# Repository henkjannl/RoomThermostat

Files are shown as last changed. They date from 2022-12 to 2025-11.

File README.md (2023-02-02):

# Roomthermostat

I wanted to create a room thermostat that can be controlled remotely ('honey, did you remember to switch off the heating?') but which also remains fully operational if internet connectivity is lost. Therefore it can be controlled through Telegram, but also via the hardware unit if WiFi is down. This is also useful since visitors may not want to use Telegram.

<p align="center">
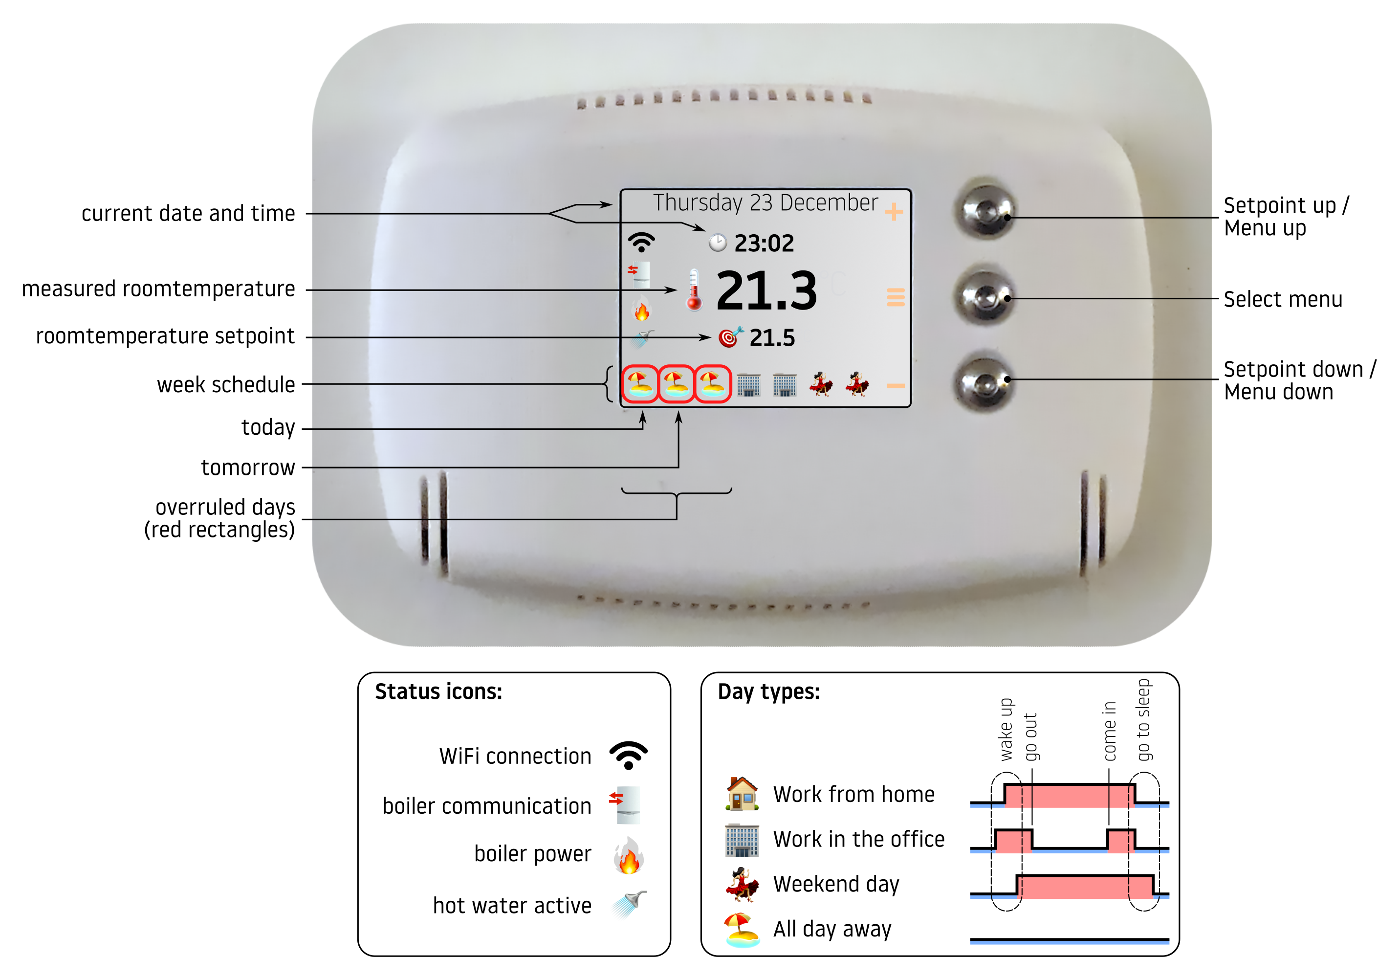
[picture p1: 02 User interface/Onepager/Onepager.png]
     
</p>

This fully (software & mechanics & electronics) open source project is based on an ESP32 microcontroller and the OpenTherm protocol.

The thermostat can be controlled by three touchbuttons on the device or via Telegram. 
In Telegram, an inline keyboard is used which changes depending on the context. This way, the user experience is similar to controlling the device via the hardware. The menu status of each Telegram user is kept in memory, so all users can communicate with the thermostat independently.

### Priorities for the temperature setpoint

<p align="center">
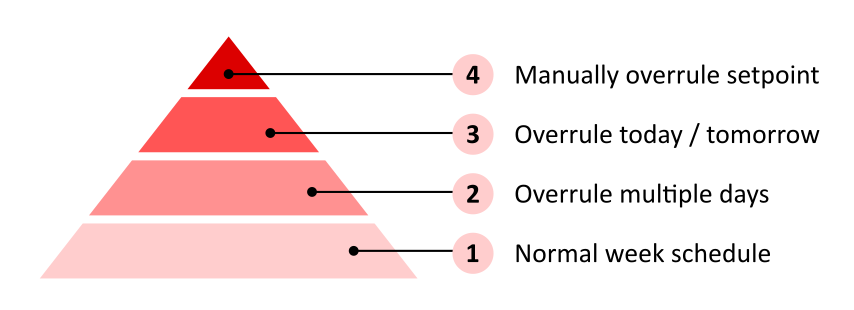
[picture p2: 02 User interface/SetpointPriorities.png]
setpoint priorities
   
</p>

The temperature setpoint can be chosen in four different ways, with increasing priority level:
1. The lowest priority level is the **normal week schedule**, which says which day type it is depending on the day of the week. 
    * There are four predefined day types:
        * :house_with_garden: **work from home**: temperature high at wake-up, and low at bed time
        * :office: **work from the office**: temperature high at wake up, low when going out, high when coming home and again low at bed time
        * :dancer: **weekend**, like :house_with_garden: **work from home** but with different wake-up and bed times
        * :palm_tree: **all day away**: temperature low throughout the day
    * The days of the week can be programmed in **settings**. 
    * All times for each type of day type can be modified
    * The low temperature and high temperature can be modified. These are the same temperatures for all day types
2. It is possible to **overrule multiple days** with a different day type, for instance to program multiple days as :dancer: **weekend day** (e.g. holiday at home) or as :palm_tree: **days away** (e.g. holiday away). 
    * The thermostat will be overruled until the number of days expires, or if the **overrule multiple days** function is **switched off** by the user
    * It is also possible to set the number of days to **forever**, for instance if heating is not required during the summer. The **overrule multiple days** can then be **switched off** in autumn.
3. **Today** and **tomorrow** can be overruled by a schedule that is different from the normal schedule.
    * Every night at midnight, **today** is replaced by **tomorrow** and **tomorrow** is switched off
    * Both can be **switched off** or changed by the user
    * For instance: if the holiday starts tomorrow, **multiple days** can be overruled to be :palm_tree: **day away**, after which **today** can be overruled as :dancer: **weekend day**
4. At all times, a **higher or lower temperature** can be manually selected. 
    * When the next programmed timeslot of the lower priority day type dawns, the temperature setting switches back the program of the nearest lower priority
    * It is also possible to choose ```Auto``` from the main menu in Telegram to switch the manual setpoint override off

If the temperature setpoint is manually overruled (priority level 4), it is displayed in red font.

Overruled day icons (priority levels 2 and 3) are surrounded by a red rectangle on the hardware unit. Telegram commands that overrule priority levels 2 and 3 will typically display  day type icons for the next 7 days.

The thermostat can be controlled by three touchbuttons on the device or via Telegram.
In Telegram, an inline keyboard is used which changes depending on the context. This way, the user experience is similar to controlling the device via the hardware. The menu status of each Telegram user is kept in memory, so all users can communicate with the thermostat independently.

## Controlling the thermostat through Telegram
### Main menu in Telegram

After selecting ```/start``` in Telegram, the following message and keyboard are returned:

<p align="center">
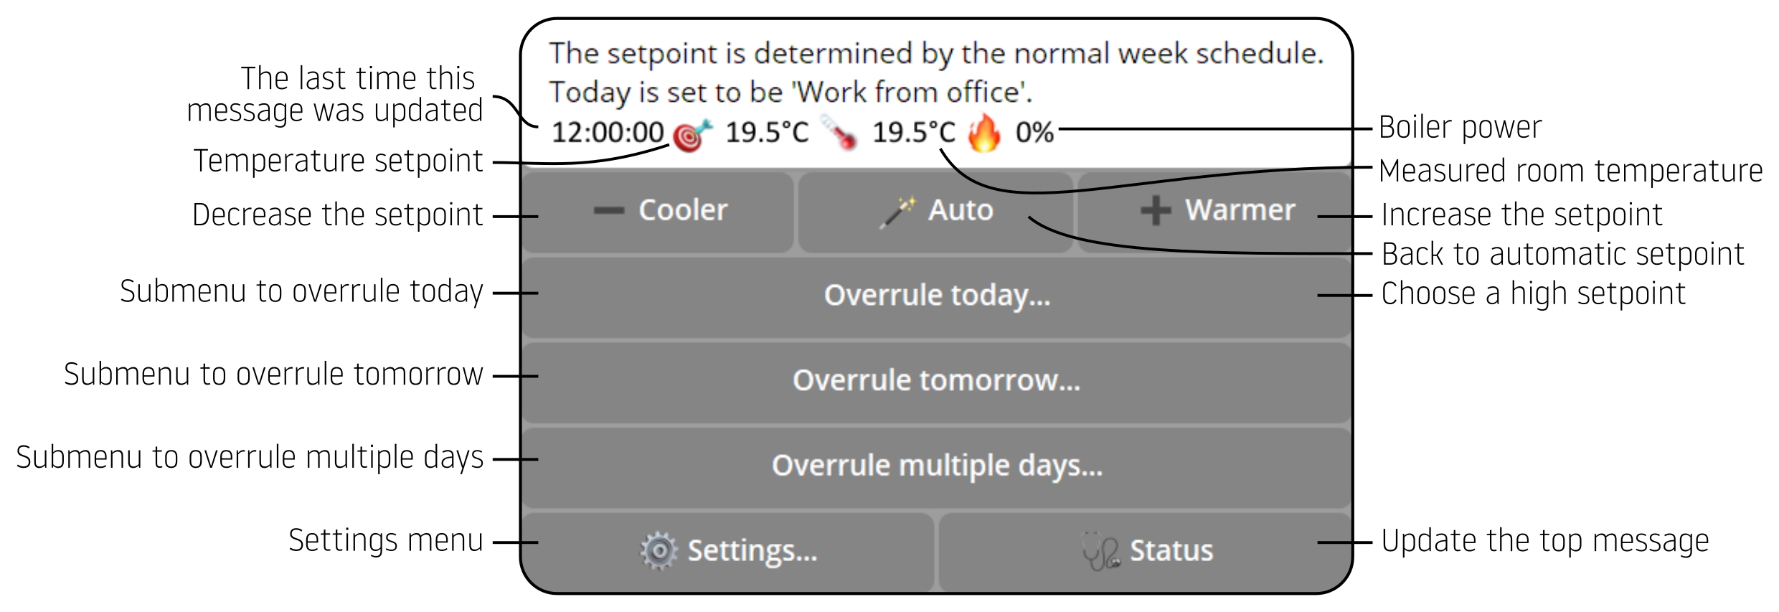
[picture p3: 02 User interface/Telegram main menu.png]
telegram main menu
   
</p>

The temperature in the room or settings of the thermostat can change over time. The display in Telegram is not automatically updated. The ```Status``` button can be used to update the status.

The settings menu has the following options:

<p align="center">
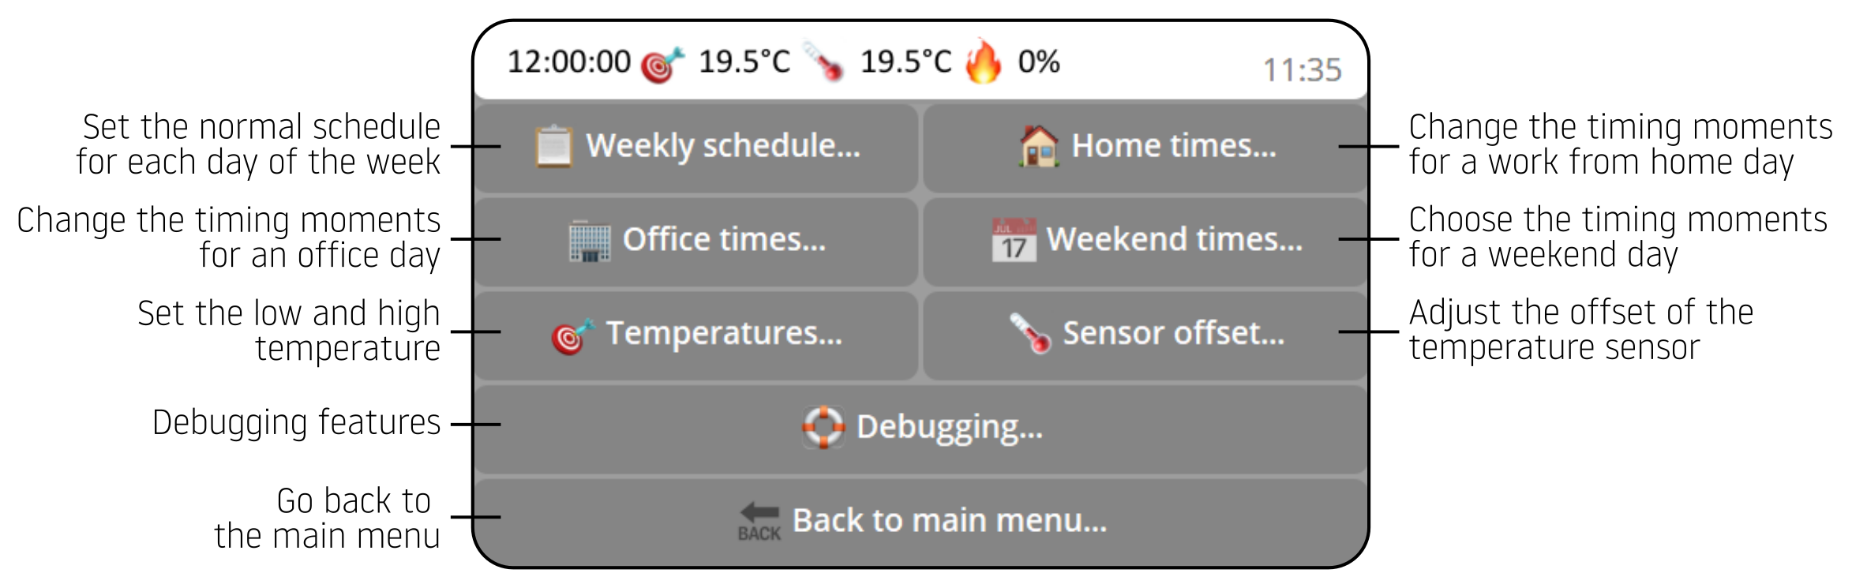
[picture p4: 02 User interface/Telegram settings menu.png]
telegram main menu
   
</p>

### Simple use case in Telegram: going on a short holiday

The scenario is that we are going on a holiday for a few days and we will return on Monday.

To do this, select ```Overrule multiple days...``` in the main menu:

<p align="center">
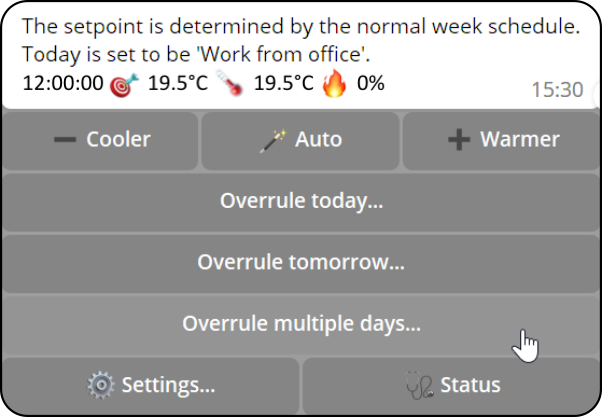
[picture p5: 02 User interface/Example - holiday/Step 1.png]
   
</p>

The icons in the next window show that the next two days are currently :office: **work from office**-days, followed by two :dancer: **weekend days** and again some :office: **work from office**-days.

<p align="center">
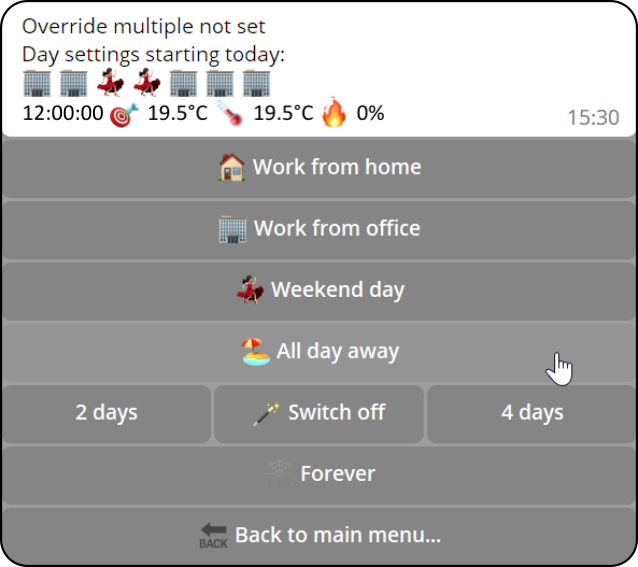
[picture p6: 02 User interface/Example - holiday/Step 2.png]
   
</p>

Select :palm_tree:```All day away``` since we will be going on a holiday:

The :palm_tree:```All day away``` scenario means that the setpoint temperature will remain low throughout the day.

Then select ```4 days``` button multiple times in the next menu until the message says there are 5 :palm_tree:**all day away**-days, including Monday, which is the last day that the temperature should remain low:

<p align="center">
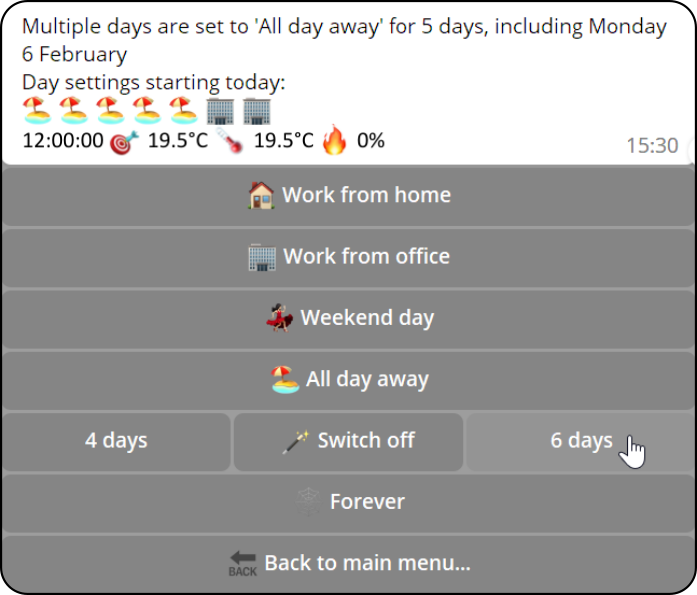
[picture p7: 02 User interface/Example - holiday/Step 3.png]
   
</p>

Next select ```Back to the main menu```:

<p align="center">
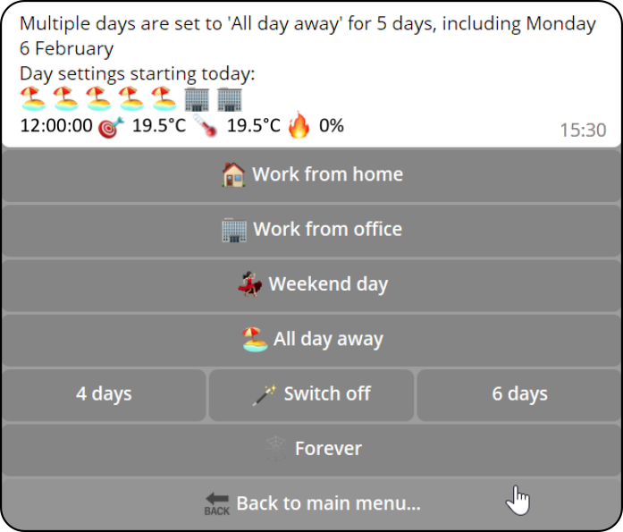
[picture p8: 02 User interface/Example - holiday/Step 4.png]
   
</p>

Now, the current day is also selected as an :palm_tree:**All day away**, with a low temperature setting for the remaining part of the day. To resolve this select ```Overrule today...```:

<p align="center">
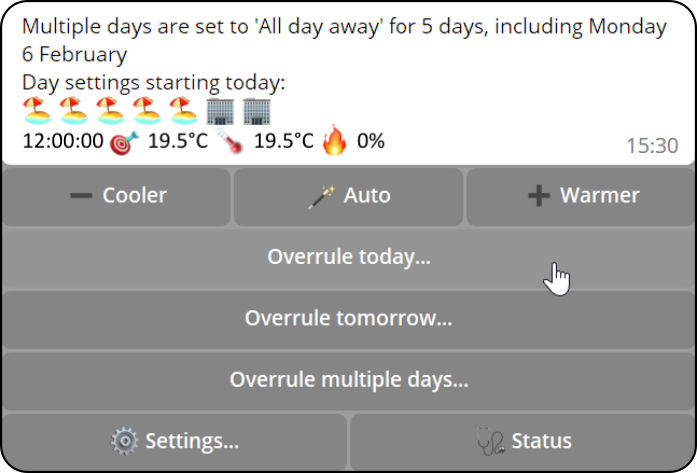
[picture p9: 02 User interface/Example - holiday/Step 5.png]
   
</p>

Choose :dancer:```Weekend day``` so we can pack our bags comfortably:

<p align="center">
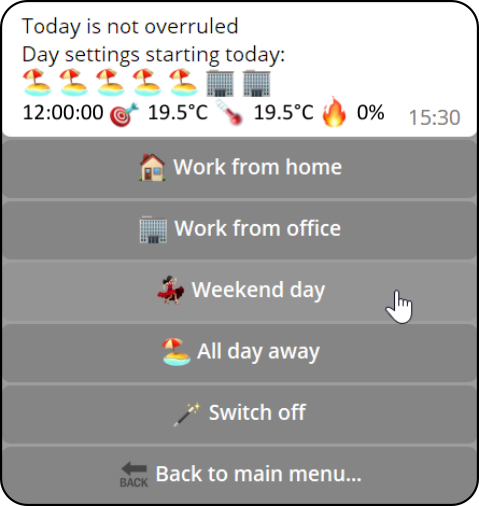
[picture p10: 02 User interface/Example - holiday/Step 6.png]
   
</p>

The remaining **Multiple days** will remain selected, only the current day will be overruled. It is also possible to overrule the next day while the remaining  **multiple days** remain overruled.

<p align="center">
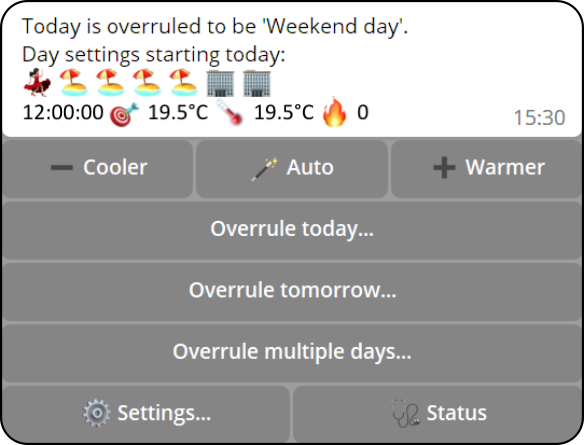
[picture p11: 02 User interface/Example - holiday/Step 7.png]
   
</p>

Of course it is also possible to do these steps after we leave, without the need to overrule the current day. As we are returning home during the next Saturday, we can also overrule the current day to ensure the house is comfortable upon arrival.

### Switch off the thermostat for a longer period of time

To switch off the thermostat for a longer period of time, for instance during the summer or during a long holiday, proceed as follows:
* Select ```Overrule multiple days...``` in the main menu
* Select :palm_tree: ```All day away```
* Select ```Forever```
* Select ```Back to the main menu...```

The thermostat is now switched off until ```Overrule multiple days``` is ```Switched off```

## Building the device

### Electronic hardware 
The hardware consists of:
* an ESP32 (mh-et-live-minikit-d1)
* an OpenTherm adaptor designed by Ihor Melnyk (DIYless Master OpenTherm Shield - https://diyless.com/product/master-opentherm-shield)
* a 2.4" 320x240 TFT screen (ILI9341)
* a 3D printed housing designed in FreeCad
* up to 4 Dallas DS18B20 temperature sensors
* a 4k7 resistor as pull-up for the Dallas temperature sensors
* 3 touch buttons (stainless steel screws, ISO7380-1, M5 x 16 + nut ISO4032 M5)
* 16 magnets (ø10 x 2.75 mm)
* a PCB designed in KiCad. This is optional, components can also be connected with wires, although it is more work and less reliable

Except for the housing and the OpenTherm interface, everything was ordered at AliExpress. The total bill of materials was about €35. The bill of materials can be found here ```\04 Electrical\Bill of materials.ods```.

### Mechanical hardware

There are two options:
* Connecting electronics via the cross connect PCB - the casing then consists of two panels, see ```03 Mechanical\RoomThermostat.FCStd```
* Connecting electronics via wires - the casing then consists of three panels, see ```03 Mechanical\RoomThermostat with PCB.FCStd```

In case of the PCB, there are two main parts to 3D print, a **front panel** and a **rear panel**. The rear panel can be screwed to the wall. The front panel is clicked on the rear panel through magnets.

Both prints need to be paused in some layer during printing to add round magnets before recommencing the printing.

It is possible to add up to four Dallas temperature sensors on the PCB (but fewer sensors should also work).

There are central ventilation openings on the bottom and top of the device to cool the ESP32 and prevent thermal cross talk between the heat of the ESP32 and the temperature sensors. There are ventilation openings in front of each temperature sensor also to measure the room temperature as accurate as possible.

The sofware has an **adjust sensor offset** feature to add or subtract a value from the measured temperature for calibration. That means that if the temperature measured by the thermostate is different from the actual room temperature, this can be corrected through the hardware buttons or via Telegram. 

### Software preparation
It is required to make a specific Telegram bot account for the thermostat. There are many sources explaining how a new Telegram bot can be created, such as in this [Random Nerd Tutorials Telegram example](https://randomnerdtutorials.com/telegram-control-esp32-esp8266-nodemcu-outputs/).

One ChatID can be provided to which the roomthermostat sends a message upon startup. This is useful to be aware that the thermostat was reset, due to a software bug or power outage.

In order to use the software, the user must first:
* make a copy of `template.jsn` (located in the `..\RoomThermoStat\05 Software\Roomthermostat\data` folder)
* rename the copy `config.jsn` 
* fill in details of one or more WiFi routers, including the timezone in which each router is located (`lon` and `lat` are currently not used)
* upload the data to SPIFFS using the ESP32 sketch upload data tool
* copy `User_Setup.h` and `User_Setup_Select.h` to the `..\Arduino\libraries\TFT_eSPI` folder (perhaps good to backup the existing versions)

The format of the `config.json` file is as follows:

```JSON
{
    "AccessPoints": [
        { "SSID": "SSIDOfWifi1", "password": "PasswordOfWifi1", "timezone" : "Europe/Amsterdam" },
        { "SSID": "SSIDOfWifi2", "password": "PasswordOfWifi2", "timezone" : "Europe/Amsterdam" }
    ],
    "BotName"     : "Name of the bot",
    "BotUsername" : "Username of the bot",
    "BotToken"    : "##########:XXXXXXXXXXXXXXXXXXXXXXXX",
    "ChatID"      : "########"
}
```

Note that there is a `config.json` and a The format of the `config_test.jsn`. The `config_test.jsn` is for test purposes, with a different bot token. It can be used for test purposes while the main thermostat bot remains accessible. To use the test bot, specify ```#define USE_TESTBOT true``` in `Roomthermostat.ino`.

Next it is necessary to upload the data folder to the ESP32 using `Tools` > `ESP32 Sketch Data Upload` in the Arduino IDE (see how this works at [Random Nerd Tutorials Telegram](https://randomnerdtutorials.com/install-esp32-filesystem-uploader-arduino-ide/).

Also, a number of libraries must be installed in Arduino:
* `ArduinoJSON` by Benoît Blanchon - https://arduinojson.org/
* `DallasTemperature` by Miles Burton - https://github.com/milesburton/Arduino-Temperature-Control-Library
* `JPEGDecoder` by Bodmer - https://github.com/Bodmer/JPEGDecoder
* `OpenTherm` by Ihor Melnyk - https://github.com/ihormelnyk/opentherm_library
* `TFT_eSPI` by Bodmer - https://github.com/Bodmer/TFT_eSPI
* `UniversalTelegram` by Brian Lough - https://github.com/witnessmenow/Universal-Arduino-Telegram-Bot

Big shout out to everyone for creating and maintaining these beautiful pieces of work!

## Software internals

### Overview of processes
| File | Module |
|---|---|
| Roomthermostat.ino | Initialization and main loop |
| a_constants.h | Defines, constants, data types |
| b_interfaces.h | Queues and structs that connect the subsystems |
| c_logger.h | Datalogging (to be implemented) |
| d_keyboard.h | Keyboard |
| e_menu.h | Menu of hardware unit |
| f_telegram.h | Handler for Telegram messages |
| g_controller.h | Temperature controller, including PID controller and program |
| h_temperature.h | Temperature measurement and communication with boiler |
| i_wifi_time.h | Wifi controller and real time clock |
| j_jpeg.h | Library to display jpeg images |
| k_display.h | Display of the hardware unit |
| l_backlight.h | Backlight |

<br><br>

## Flow of events and messages

Initially, FreeRTOS was envisaged to handle all different processes. However, I did not (yet) get this working together with the OpenTherm library, which is very time critical. It is only possible to debug this with the live boiler attached,  which is a little barrier. Now, all processes are handled sequentially by the main loop.

It also appears that the SPI bus that communicates with the display does not work well while the capacitive touch button routine is called. Every time the display updates, the `touchRead()` is temporarily disabled.

The touch buttons are also disabled while OpenTherm communicates with the boiler.

<br>
The flow of events and messages is as follows:
<br>

<p align="center">
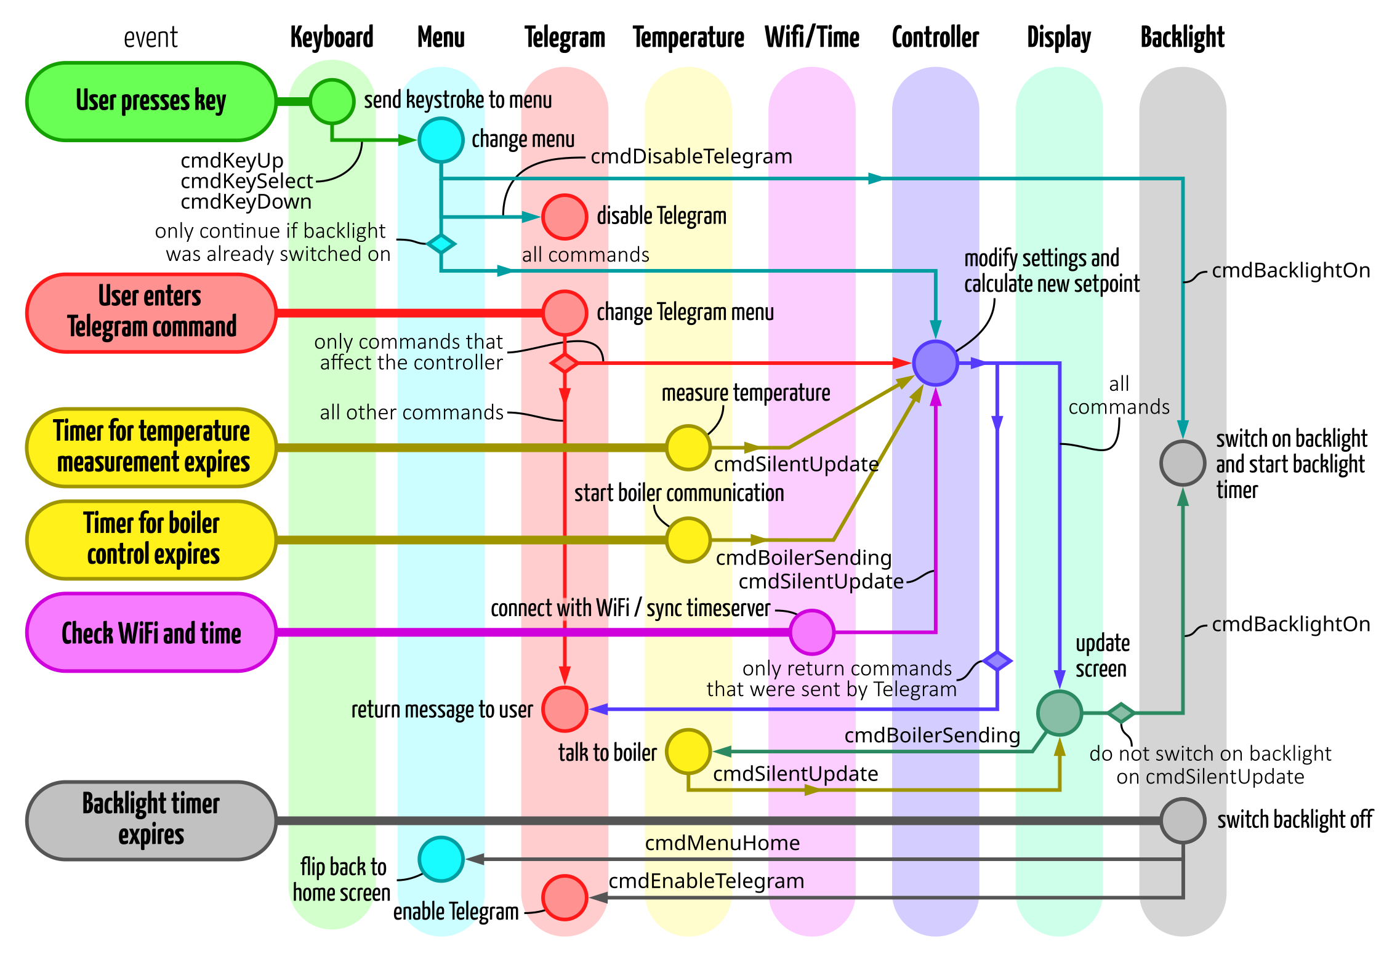
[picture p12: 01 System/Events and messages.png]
events and messages
 
</p>

* On the left hand side, the events that trigger activities are listed
* The circles represent code
* The arrows between the circles represent messages that are sent over the queues

### User presses key
* the ISR is running at about 30 Hz and is kept a small as possible. The capacitive sensors sometimes give a spike which only lasts one clock tick. Therefor, a key press is only considered valid if the key remains pressed for 2 subsequent samples. The ISR of the keyboard only sends a message to the menu, containing the key that was pressed. Subsequent actions are then carried out by the menu and other modules
* The capacitive sensor does not work well together with the SPI bus of the display, resulting in a crash of the microcontroller. Also, the keyboard ISR can interfere with the timing of the OpenThrem protocol. Therefore, polling the capacitive sensors is disabled during display or OpenTherm communication 
* the Backlight is controlled by the Display. In some cases, a button press does not result in a command to the controller (e.g., pressing the 'up'-button while the top menu item was already selected). In these cases, the backlight should also switch on. Therefore, the menu always sends a `cmdBacklightOn` command directly to the Backlight
* Telegram can take a few seconds to return. To improve responsivity of the keyboard, Telegram is temporarily disabled while the user is interacting with the keyboard. Telegram will be re-enabled as soon as the blacklight switches off.
* the first key press is only used to switch on the backlight. If the backlight is off while a key is pressed, the key is ignored and the backlight is woken up

### User enters a command in Telegram
* the status of the Telegram menu is stored independently for each individual ChatID, so each user can interact with Telegram independently of the other Telegram users and of the hardware unit
* some commands change the status of the controller (e.g., change a wake up time may cause a different setpoint for the boiler), others do not (e.g., moving to another screen in Telegram)
* only commands that change the status of the controller are sent to the controller, the other commands are directly forwarded to the Telegram queue that handles sending a response to the chat
* if the controller receives the command, it causes an update of the display which in turn switches on the backlight. This way, people in the room may notice that the setpoint was potentially changed and may act accordingly
* after the controller completes the action, the command is forwarded to the Telegram queue that returns the response to the user

### The timer for temperature measurement expires
* after the temperature is measured, the controller gets the chance to change the boiler setpoint, and a display update is triggered. This is done via a  `cmdSilentUpdate` command, which does not trigger the backlight: the change is only visible to the user if the backlight was already switched on

### The timer for the boiler expires
* as the timer expires, the controller is called to update the boiler setpoint
* the controller then forwards the `cmdBoilerSending` command to the screen which changes the boiler icon
* then, the screen again forwards the command to the temperature queue which triggers actual communication with the boiler
* finally, a `cmdSilentUpdate` command restores the boiler icon to the normal state

### Check WiFi and time timer expires
* this event (re-)connects to WiFi if needed, syncs with the timeserver if needed and updates the screen to reflect the change of the icon, without switching on the backlight

### Backlight timer expires
* the backlight is switched off
* the menu of the hardware unit is flipped back to the home screen
* Telegram is re-enabled

## Overview of directories:
* GUI and icons were created in Inkscape and are located in `..\RoomThermoStat\02 User interface\GUI design.svg`
* All types and structures of the menu structure are managed in `..\RoomThermoStat\02 User interface\Menu structure.xlsx`
* GUI colors are chosen in Inkscape converted to RGB565 in  `..\RoomThermoStat\02 User interface\Color converter RGB565.xlsx`
* Mechanical design is done in FreeCAD and is located in `..\RoomThermoStat\03 Mechanical\_RoomThermostat.FCStd`
* The interconnect PCB is designed in KiCAD and is located in  `..\RoomThermoStat\04 Electrical\Interconnect PCB V1.0 - as ordered JLC PCB`
* Arduino programs to test individual pieces of hardware are located in `..\RoomThermoStat\05 Software\Tests`
* Current version of the Arduino software is located in `..\RoomThermoStat\05 Software\Roomthermostat`

## Over the air software updates

After uploading the code over the COM port the first time, over the air updates are possible. However, during normal operation, the keyboard handler will interfere with the update process.
Therefore, first use Telegram to select ```Settings``` > ```Receive over the air update...```. The keyboard handler, the boiler and Telegram will 
be disabled for five minutes during which time boiler will switch off. 
During these five minutes, th blue LED on the back of the ESP32 will blink. During this time, choose the over the air port in Arduino (instead of the COM port) and upload the software over WiFi.

# To do

Software:
* over the air update still not working well
* over the air update does not display network port in Arduino IDE (perhaps call ArduinoOTA.handle() more often?)
  * while waiting for over the air software update, display message on screen
* improve responsiveness (keys and Telegram)
  * try to get FreeRTOS working again to improve performance of buttons and Telegram
    * perhaps Telegram can run on other core?
  * implement OpenTherm protocol in hardware timer in non-blocking way
* separate timers for blocking Telegram and backlight (backlight longer than blocking Telegram)
* include icons in the menu
* save logdata through WiFi connection 
  * Deta Base?
  * send logfile as attachment to Telegram
* much code can be simplified to remove structures that were used in previous attempts to get the code working
    * some userEventMessage_t constructs can be replaced with sendMessage() calls
    * some userEventMessage_t constructors may no longer be used
    * ...
* send automatic updates to last message of known clients every 15 minutes
  * also store list of chatIDs in permanent storage?
  * add functionality to whitelist or blacklist chatIDs?
* optimize heater control functionality
    * allow user to modify water temperature of heater and shower
    * check if D-action is implemented well in PID controller
    * take into account the weather in the control strategy
    * monitor the time it takes to heat the room in the morning, and compensate that by starting earlier or start with higher temperature
* also enable setting the time and date through hardware buttons if WiFi is unavailable
* display progress upon startup
* try if SPI frequency in TFT_eSPI can be set to higher value

Code cleanup:
* find replace action GoOut > Leave
* cleanup Serial.print
* check use of const in function calls
* cleanup the use of messages. Some fields may no longer be needed

Hardware:
* add a capacitor to prevent brownout of the ESP32 at startup
* little more space between adjacent boards
* more room for connector
* no two components at same location on either side of the main PCB (order of soldering doesn't matter, desoldering is possible)
* next step: integrate OpenTherm components and ESP32 components on main board

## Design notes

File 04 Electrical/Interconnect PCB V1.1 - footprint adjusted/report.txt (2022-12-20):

Plotted to 'C:\Users\henkj\IOT\RoomThermoStat\04 Electrical\Interconnect PCB V1.1 - footprint adjusted\Gerber\Interconnect PCB-F_Cu.gtl'.
Plotted to 'C:\Users\henkj\IOT\RoomThermoStat\04 Electrical\Interconnect PCB V1.1 - footprint adjusted\Gerber\Interconnect PCB-B_Cu.gbl'.
Plotted to 'C:\Users\henkj\IOT\RoomThermoStat\04 Electrical\Interconnect PCB V1.1 - footprint adjusted\Gerber\Interconnect PCB-F_Silkscreen.gto'.
Plotted to 'C:\Users\henkj\IOT\RoomThermoStat\04 Electrical\Interconnect PCB V1.1 - footprint adjusted\Gerber\Interconnect PCB-B_Silkscreen.gbo'.
Plotted to 'C:\Users\henkj\IOT\RoomThermoStat\04 Electrical\Interconnect PCB V1.1 - footprint adjusted\Gerber\Interconnect PCB-F_Mask.gts'.
Plotted to 'C:\Users\henkj\IOT\RoomThermoStat\04 Electrical\Interconnect PCB V1.1 - footprint adjusted\Gerber\Interconnect PCB-B_Mask.gbs'.
Plotted to 'C:\Users\henkj\IOT\RoomThermoStat\04 Electrical\Interconnect PCB V1.1 - footprint adjusted\Gerber\Interconnect PCB-Edge_Cuts.gm1'.
Created Gerber job file 'C:\Users\henkj\IOT\RoomThermoStat\04 Electrical\Interconnect PCB V1.1 - footprint adjusted\Gerber\Interconnect PCB-job.gbrjob'.
Info: Done.

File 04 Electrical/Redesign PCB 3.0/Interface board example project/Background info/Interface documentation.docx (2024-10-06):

# OpenTherm interface board

I want to create a new version of my room thermostat, and this time I want to order an assembled PCBA at JLCPCB. Eventually I also want to add a USB-C connector, power supply and ESP32 to the board, but to try out if my KiCad skills are sufficient, I first created a very simple board, which only consists of the redlined area of the schematic below:

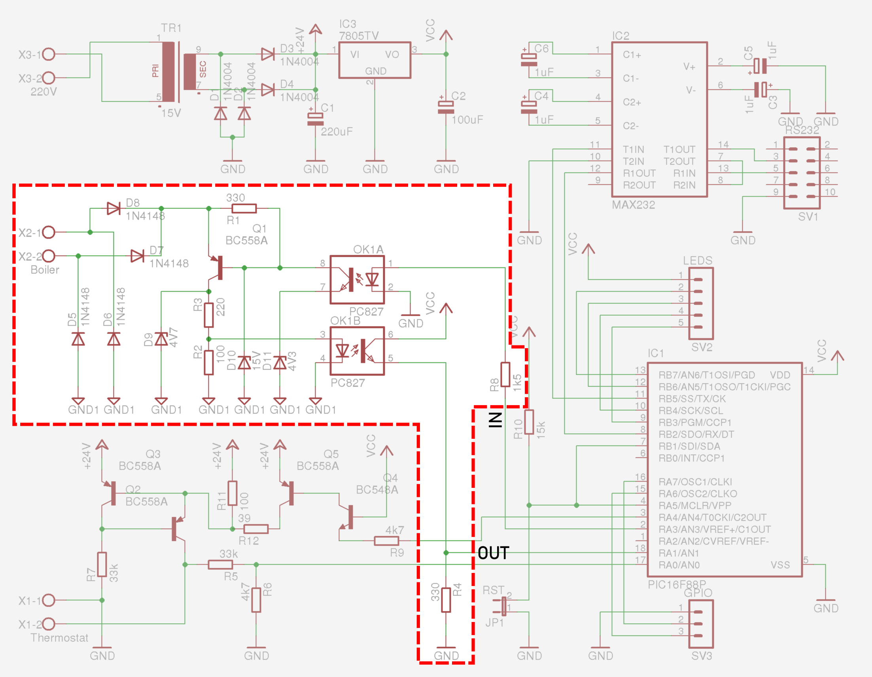
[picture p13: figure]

I copied this schematic from: otgw.tclcode.com/schematic (https://otgw.tclcode.com/schematic.html)

I needed to transfer the components list:

- Conrad numbers are provided, where I need JLCPCB part numbers
- I need to substitute through-hole components by surface mounted devices

The original parts list is (only the relevant parts):

Reference | Description | Value | Conrad | Detailed description from Conrad (Dutch)
OK1 | Dual opto-coupler | PC827 | 140235-89 (https://www.conrad.nl/zoeken?search=140235-89) | Broadcom Optocoupler fototransistor ACPL-827-000E DIP-8 Transistor DC
Q1 | PNP Transistor | BC558A | 1262971-89 (https://www.conrad.nl/zoeken?search=1262971-89) | Diotec Transistor (BJT) - discreet BC558A TO-92 PNP
D5, D6, D7, D8 | Diode | 1N4148 | 162280-89 (https://www.conrad.nl/zoeken?search=162280-89) | Diotec Ultrasnelle Si-diode 1N4148 SOD-27 75 V 150 mA
D9 | Zener Diode | 4V7 | 180084-89 (https://www.conrad.nl/zoeken?search=180084-89) | Diotec Zenerdiode ZPD4.7 Behuizingssoort (halfgeleider) DO-35 Zenerspanning 4.7 V Vermogen (max.) P(TOT) 506 mW
D10 | Zener Diode | 15V | 180203-89 (https://www.conrad.nl/zoeken?search=180203-89) | Diotec Zenerdiode ZPD15 Behuizingssoort (halfgeleider) DO-35 Zenerspanning 15 V Vermogen (max.) P(TOT) 518 mW
D11 | Zener Diode | 4V3 | 180076-89 (https://www.conrad.nl/zoeken?search=180076-89) | Diotec Zenerdiode ZPD4.3 Behuizingssoort (halfgeleider) DO-35 Zenerspanning 4.3 V Vermogen (max.) P(TOT) 505 mW
R2 | 1/4 Watt 5% Resistor | 100 | 1417639-89 (https://www.conrad.nl/zoeken?search=1417639-89) | Yageo CFR25J100RH CFR-25JT-52-100R Koolfilmweerstand 100 Ω Axiaal bedraad 0207 0.25 W 5 % 1 stuk(s)
R3 | 1/4 Watt 5% Resistor | 220 | 1417693-89 (https://www.conrad.nl/zoeken?search=1417693-89) | Yageo CFR25J220RH CFR-25JT-52-220R Koolfilmweerstand 220 Ω Axiaal bedraad 0207 0.25 W 5 % 1 stuk(s)
R1, R4 | 1/4 Watt 5% Resistor | 330 | 1417730-89 (https://www.conrad.nl/zoeken?search=1417730-89) | Yageo CFR25J330RH CFR-25JT-52-330R Koolfilmweerstand 330 Ω Axiaal bedraad 0207 0.25 W 5 % 1 stuk(s)
R8 | 1/4 Watt 5% Resistor | 1k2 | 1417712-89 (https://www.conrad.nl/zoeken?search=1417712-89) | Yageo CFR25J1K2H CFR-25JT-52-1K2 Koolfilmweerstand 1.2 kΩ Axiaal bedraad 0207 0.25 W 5 % 1 stuk(s)

# Modified schematic

My modified schematic looks like this:

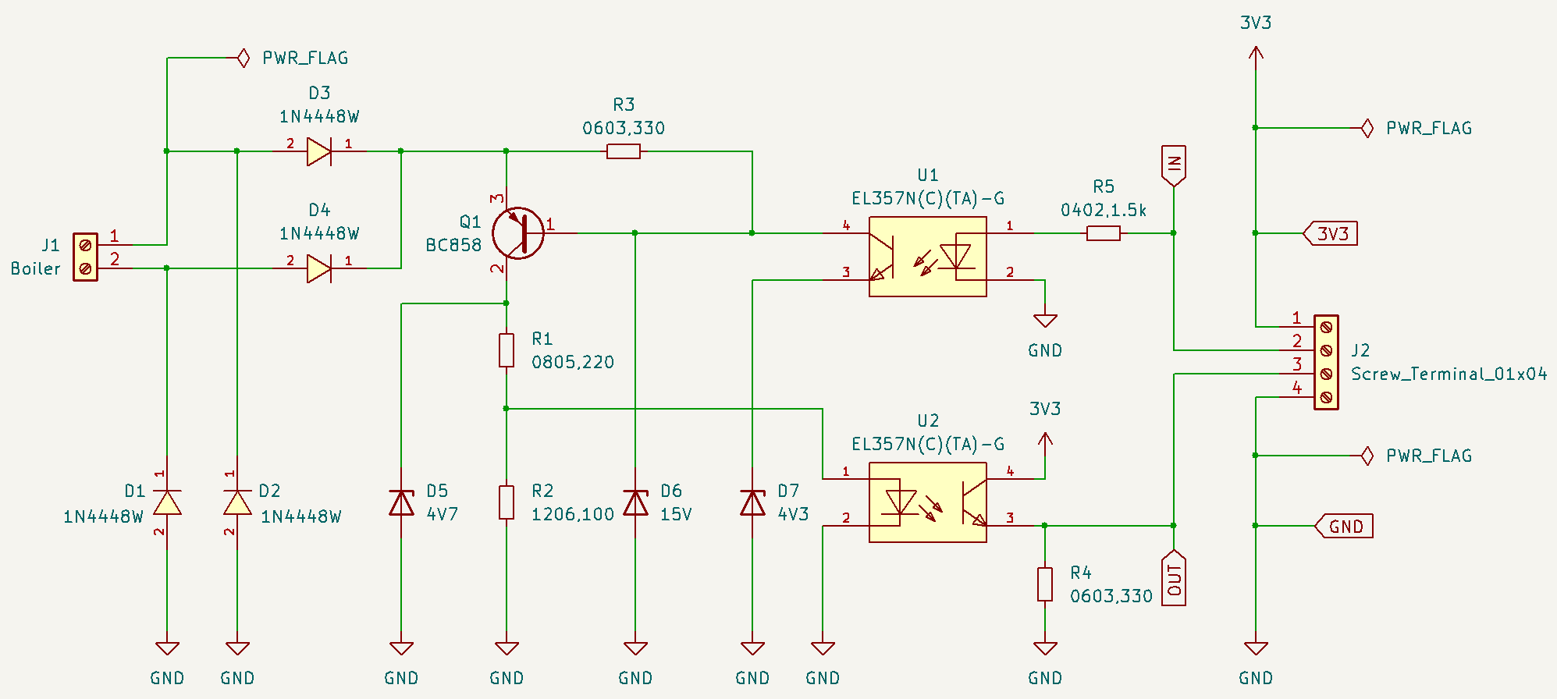
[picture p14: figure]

# Finding equivalent SMD components

I installed a library of JLCPCB components and footprints from https://github.com/CDFER/JLCPCB-Kicad-Library.git, but found that many components that are available at JLCPCB are missing. I tried to find equivalent SMT components on https://jlcpcb.com/partdetail. Typically, several versions of a component exist, and specifications are slightly different from the original through-hole part.

Starting with D1, D2, D3 and D4 in the new bill of materials, this is the original 1N4448 from the Conrad part:

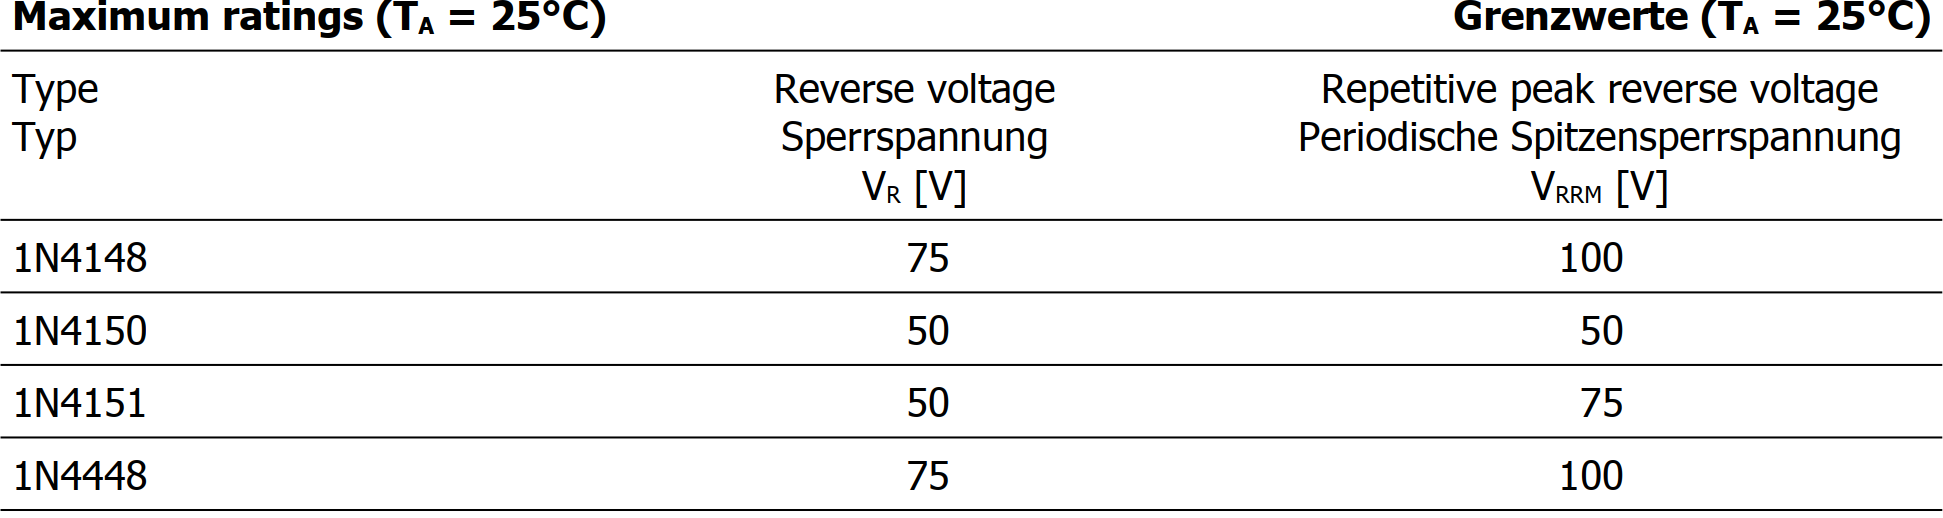
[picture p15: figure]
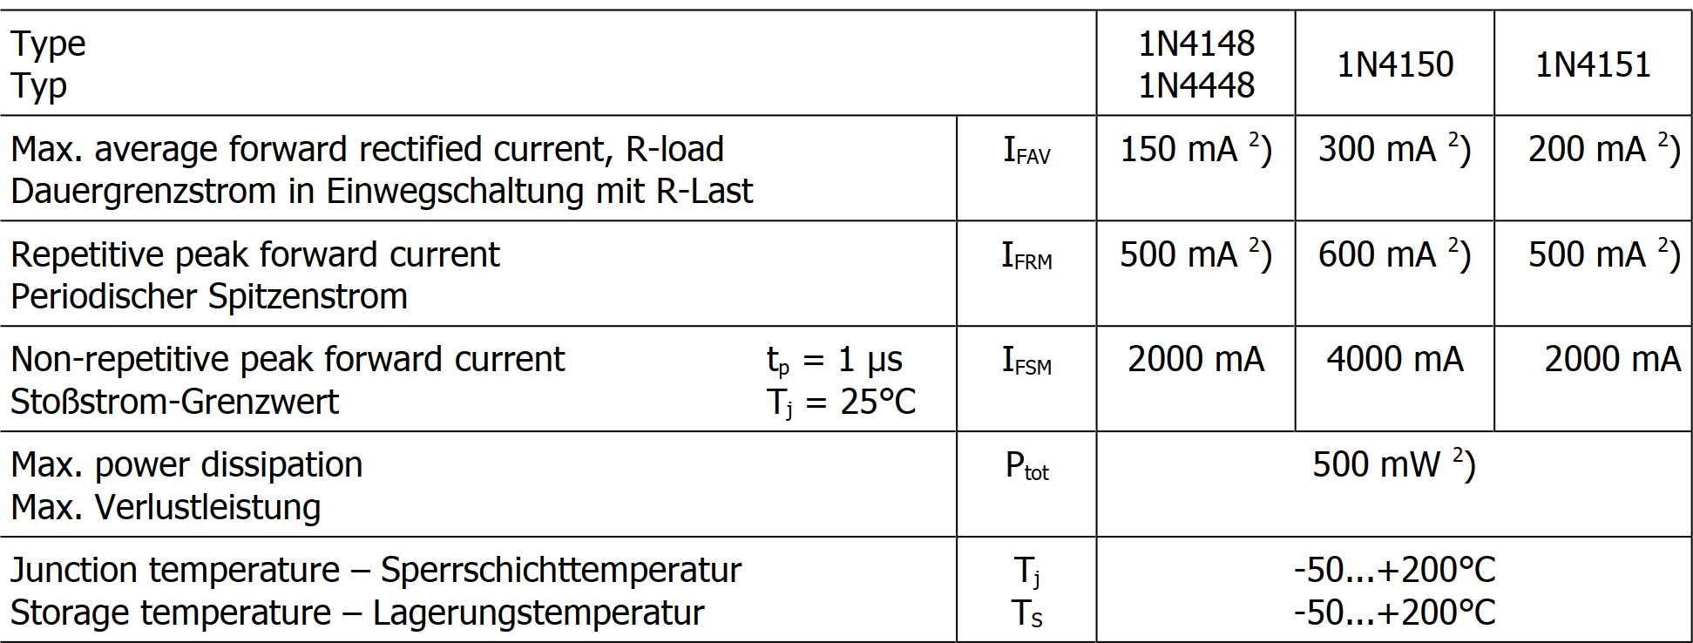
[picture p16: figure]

In JLCPCB, I sorted on available stock and started at the top:

Here is a sample of the datasheet of the Xzt 1N4448W, LCSC# C5805633:

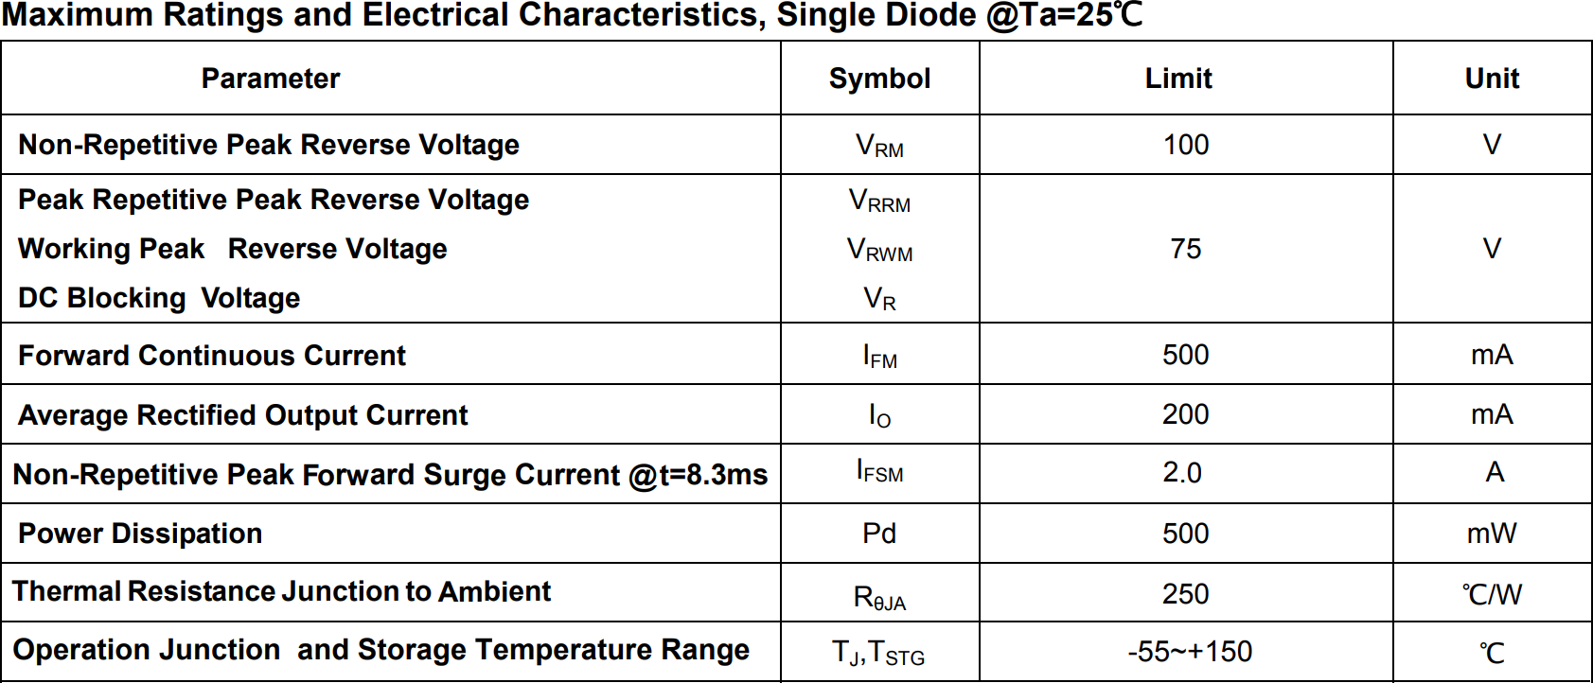
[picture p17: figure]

Comparison:

Property | | 1N4448 Conrad | 1N4448W JLCPCB | Suitable
Reverse voltage | VR | 75 V | 100 V (?) | OK
Repetitive peak reverse voltage | VRRM | 100 V | 75 V | NOK
Max. average forward rectified current, R-load | IFAV | 150 mA | ? | ?
Repetitive peak forward current | IFRM | 500 mA | ?
Non-repetitive peak forward current, tp = 1 µs | IFSM | 2000 mA | 2 A | OK
Power dissipation | Ptot | 500 mW | 500 mW | OK

To know if the JLCPCB version is suitable for this application, I would need to reverse-engineer the circuit based on the OpenTherm specification. What kind of due diligence is common when designating alternative components?

# Reverse engineering the schematic

To determine the requirements of all components, I decided to simulate the schematic in KiCAD.

First, I retrieved the specification of the OpenTherm protocol (http://files.domoticaforum.eu/uploads/Manuals/Opentherm/Opentherm%20Protocol%20v2-2.pdf):

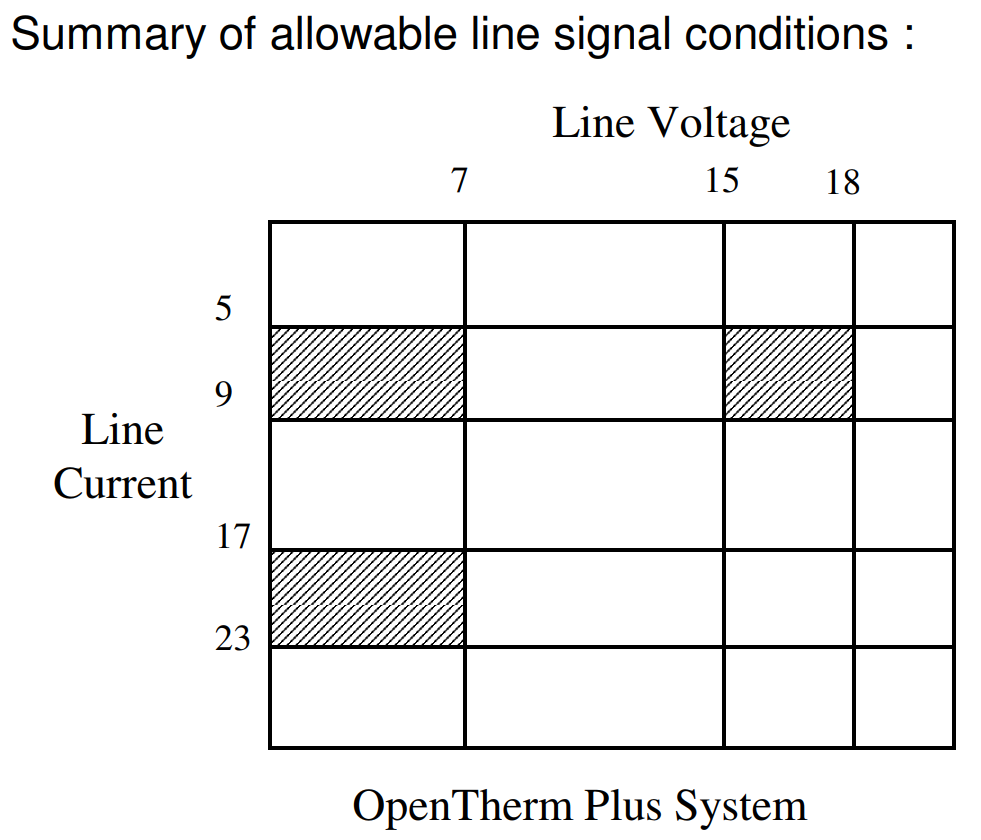
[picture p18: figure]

The units are Volts horizontally and mA vertically. The boiler can send signals to the controller by changing the current, the controller sends signals back to the boiler by changing the voltage.

Fun fact: it is backwards compatible with old-style hydrogen-drop-in-glass-bead Honeywell thermostats, since if the circuit is closed or open for longer periods of time, the boiler starts or stops boiling at full load.

Without external load, the voltage emitted by the boiler is 42 V.

I calculated 4 cases:

Case | Current controlled by boiler | State of optocoupler U1
1 | 7 mA | Open
2 | 23 mA | Open
3 | 7 mA | Closed
4 | 23 mA | Closed

I learned that it is important to start with really simple simulations to understand if the simulation works well, and then make schematics more complicated.

The first circuit involved a voltage source, a resistor and a diode. I retrieved the VDC source and the diode from the simulation_SPICE library. In other libraries, the pinout of the diode is often swapped.

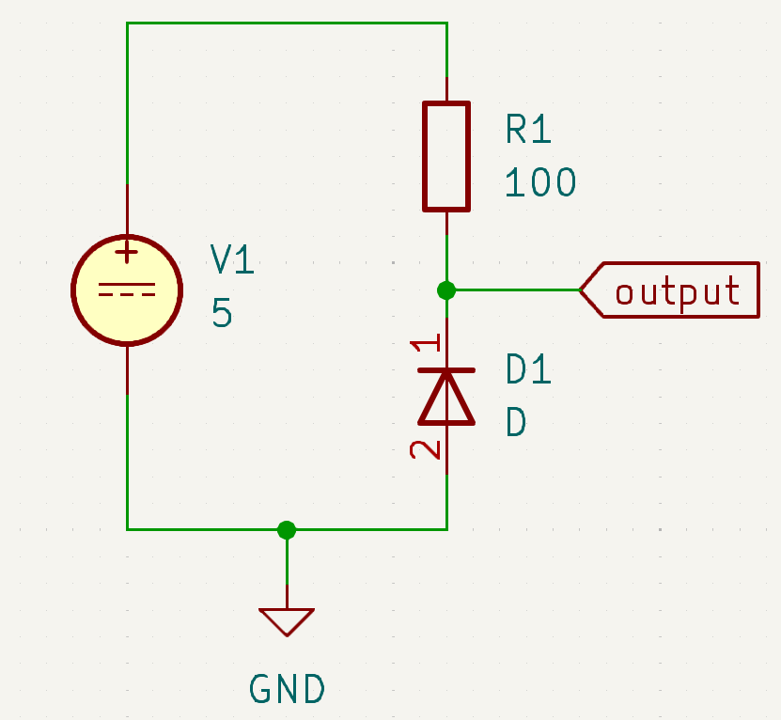
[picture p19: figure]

In the spice simulator, a sweep analysis is chosen, sweeping the voltage of BT1 between -5 and +5 V with steps of 0.01V:

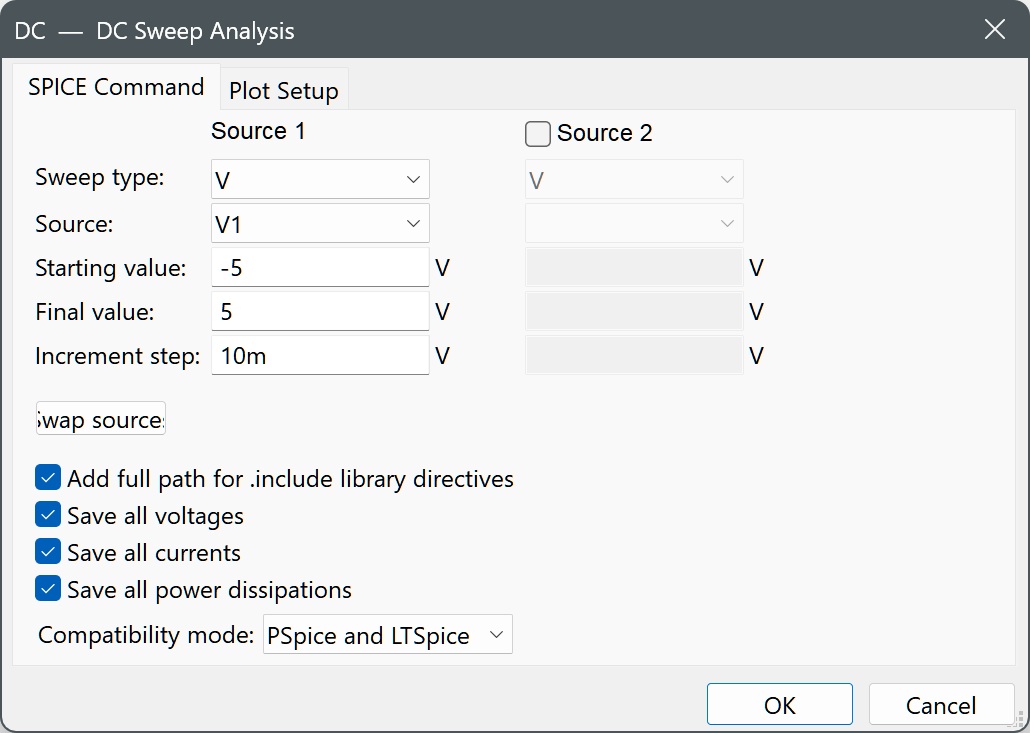
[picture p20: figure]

The voltage of the output changes as function of the supplied voltage:

When the supplied voltage is negative, the diode conducts current, and there is only a -0.7V potential at the output. When the supplied voltage is positive, the diode blocks and the output voltage becomes equal to the supply voltage.

Now, we will see if a Zener diode works well. Replace the diode with a Zener:

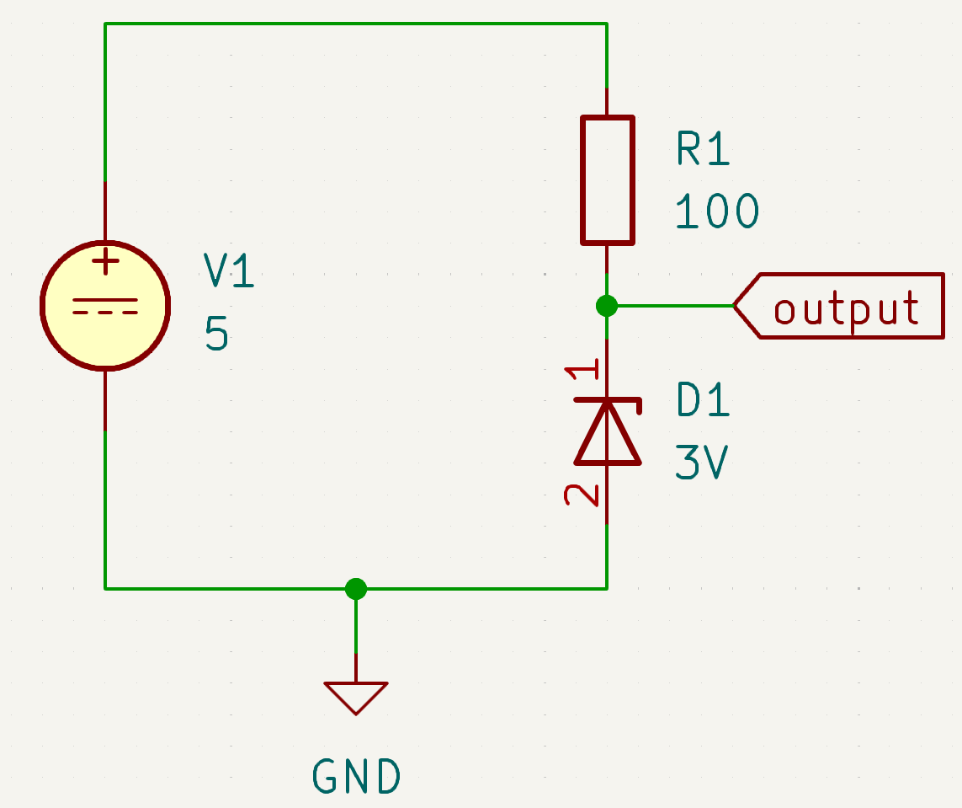
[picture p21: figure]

The Zener is not available in the simulation_SPICE library, so I used D_zener from the Device library. In this library, the pins are swapped, so Sim.Pins has to be modified to 1=K 2=A. Pin numbers can be shown in the schematic by flagging the “Show pin numbers”in the Symbol Properties.

Set the parameters of the Zener diode as follows, specifying the breakdown voltage bv=3 V, and defining pin 1 as Anode and pin 2 as Kathode:

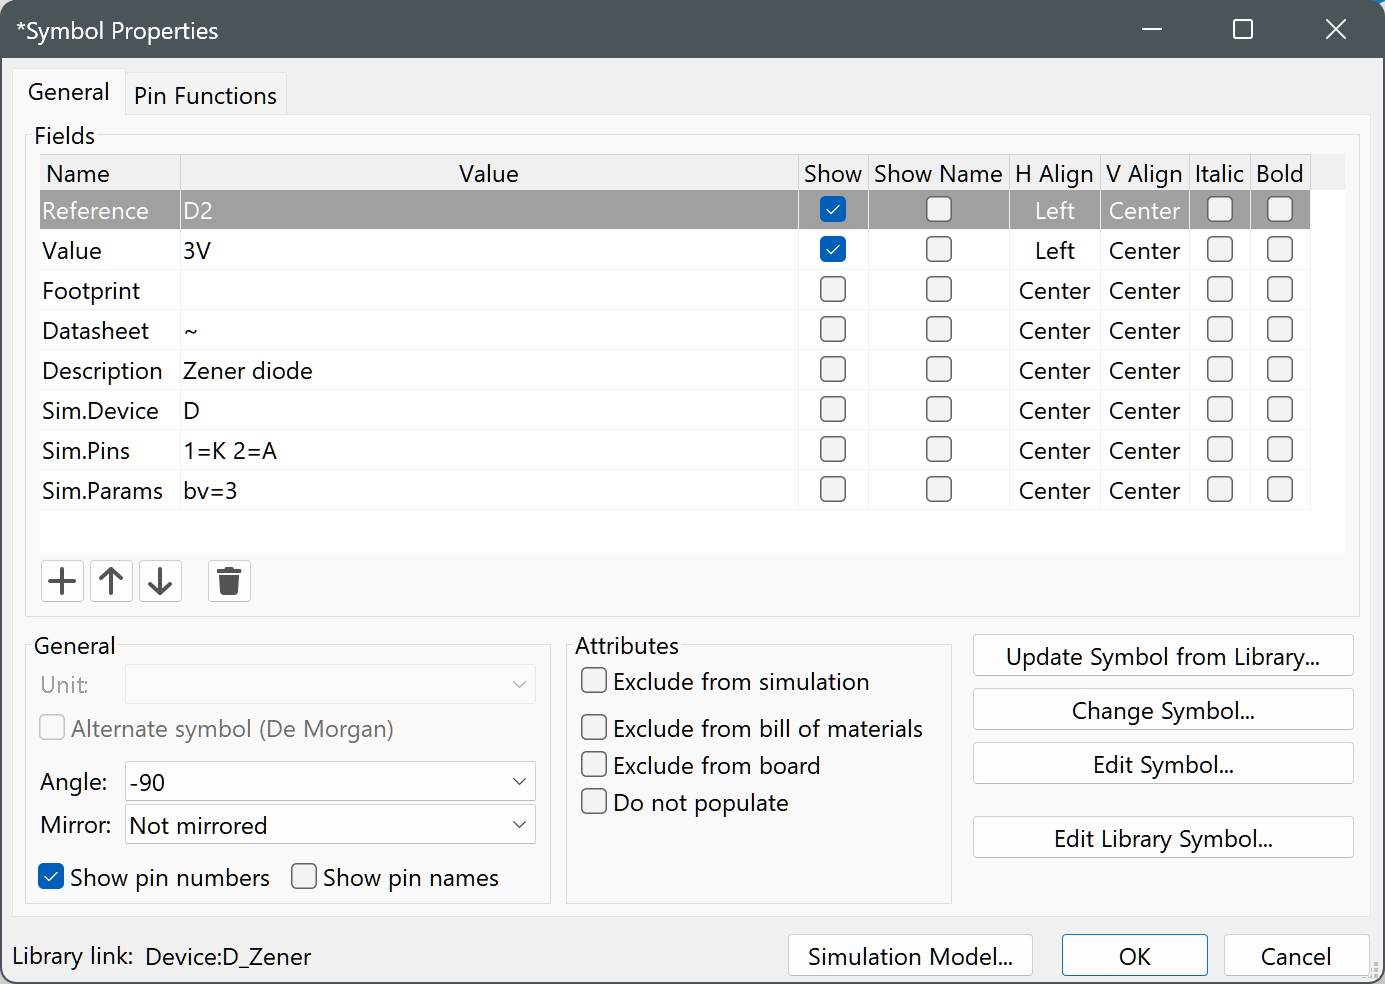
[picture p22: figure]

The simulation shows:

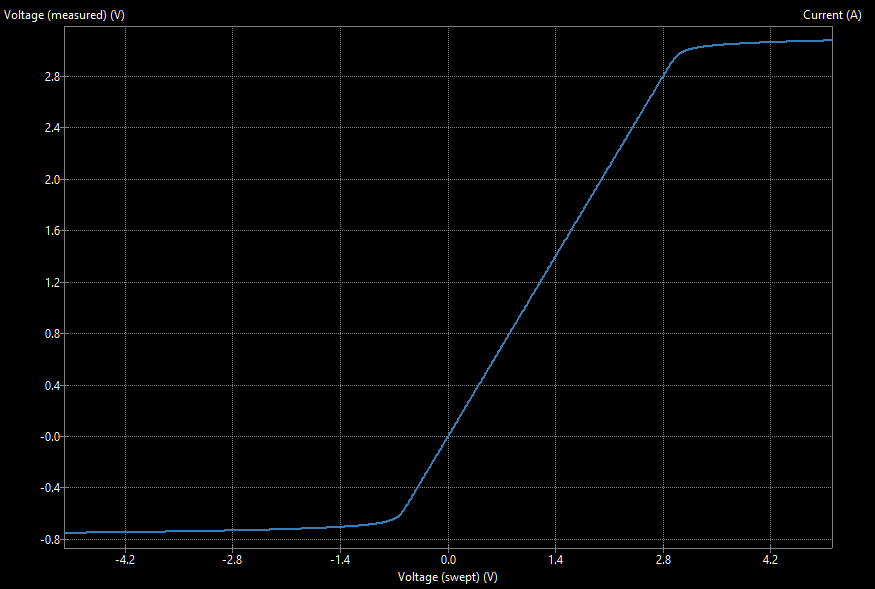
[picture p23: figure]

-5 … | -1.4 V | Zener conducts, resulting in a potential of -0.7 V at the output
-0.5 … | +2.8 V | Output is proportional to input
+3 … | +5 V | Zener clips output to 3 V

We can also show the current through the Zener diode:

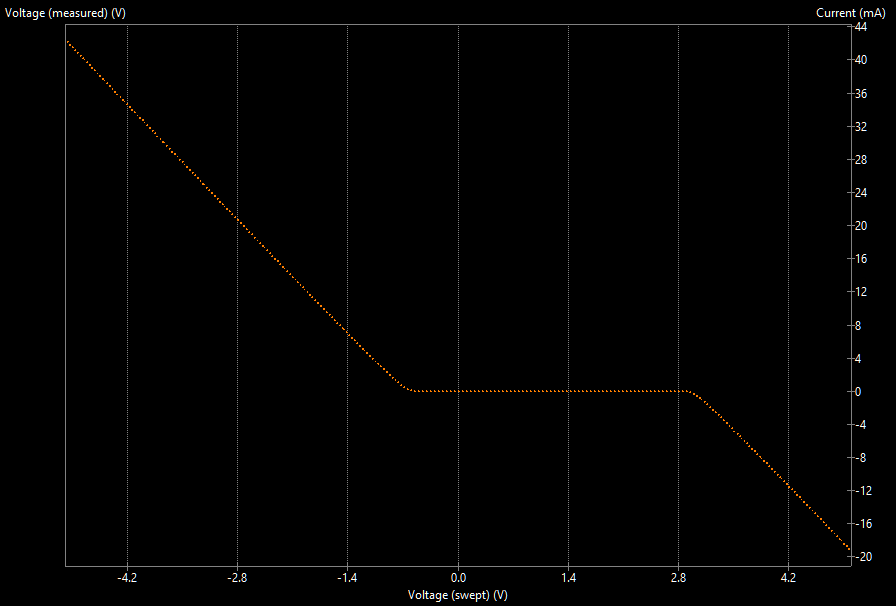
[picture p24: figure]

In KiCAD, a positive voltage leads to a current in the negative direction. Thus, when the potential is -5 V, the current through the circuit is positive. Between -0.7 V and +3 V, the current remains constant, where the resistance of the Zener remains very low. Beyond +3 V, the conductivity of the Zener increases to keep voltage b constant at +3 V.

ChatGPT suggested to use the MMBT2907A as an SMT alternative for the BC558, and kindly suggested the following pspice parameters for the Gummel-Poon model:

Saturation Current | IS | 6.734×10⁻¹⁴ | A
Forward Beta or Current Gain | BF | 220 | -
Forward Emission Coefficient | NF | 1 | -
Forward Early Voltage | VAF | 60 | V
Corner for Forward Beta Roll-Off | IKF | 0.1 | A
Reverse Beta | BR | 8 | -
Reverse Emission Coefficient | NR | 1 | -
Reverse Early Voltage | VAR | 8 | V
Corner for Reverse Beta Roll-Off | IKR | 0.03 | A
Base-Collector Leakage Saturation Current | ISC | 1x10⁻¹³ | A
Base-Collector Leakage Emission Coefficient | NC | 2 | -
Base-Emitter Zero-Bias Capacitance | CJE | 24p | F
Base-Emitter Built-In Potential | VJE | 0.75 | V
Base-Emitter Capacitance Grading Coefficient | MJE | 0.33 | -
Forward Transit Time | TF | 200p | s
Coefficient for Excess Phase in Forward Transistor Region | XTF | 2 | -
Voltage for Coefficient XTF | VTF | 2 | V
High Current Injection for Transit Time Modulation | ITF | 0.02 | A
Excess Phase Related to TF | PTF | 0 | -
Base-Collector Zero-Bias Capacitance | CJC | 12p | F
Base-Collector Built-In Potential | VJC | 0.5 | V
Base-Collector Capacitance Grading Coefficient | MJC | 0.5 | -
Fraction of Base-Collector Capacitance | XCJC | 0.5 | -
Reverse Transit Time | TR | 200n | s
Base-Substrate Zero-Bias Capacitance | CJS | 0 | F
Base-Substrate Built-In Potential | VJS | 0.75 | V
Base-Substrate Capacitance Grading Coefficient | MJS | 0.5 | -
Zero-Bias Base Resistance | RB | 10 | Ω
Emitter Resistance | RE | 0.3 | Ω
Collector Resistance | RC | 0.3 | Ω

To check if the transistor works, I added a voltage supply and changed the existing supply to a current source:

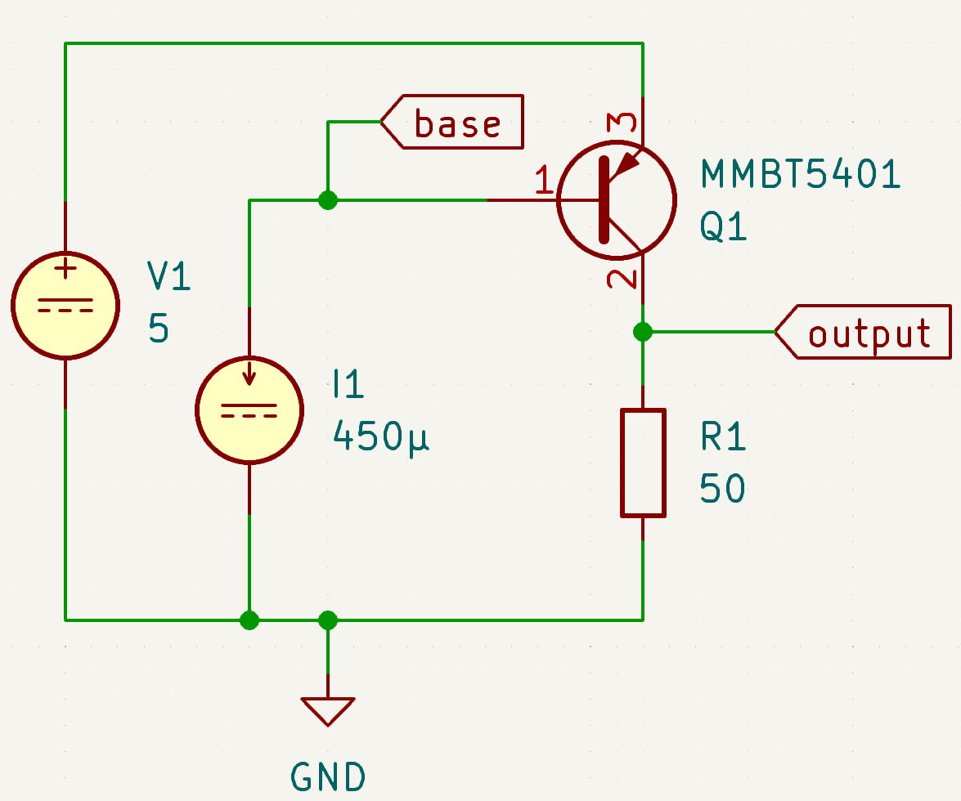
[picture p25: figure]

is=6.734e-14 bf=220 nf=1 vaf=60 ikf=0.1 br=8 nr=1 var=8 ikr=0.03 isc=1e-13 nc=2 rb=10 re=0.3 rc=0.3 cje=24p vje=0.75 mje=0.33 tf=200p xtf=2 vtf=2 itf=0.02 ptf=0 cjc=12p vjc=0.5 mjc=0.5 xcjc=0.5 tr=200n cjs=0 vjs=0.75 mjs=0.5

(for BC558 this is:

is=1.4e-14 bf=300 nf=1 vaf=50 ikf=0.03 br=6 nr=1 var=10 ikr=0.03 isc=1e-13 nc=2 rb=2 re=0.5 rc=1 cje=20p vje=0.63 mje=0.33 tf=0.4n xtf=2 vtf=5 itf=0.3 ptf=0 cjc=7.5p vjc=0.75 mjc=0.33 xcjc=0.5 tr=0.1n cjs=0 vjs=0.75 mjs=0.5)

This time, I swept the current of I1 while keeping V1 steady at 5V. The collector of the transistor can drive 100mA, so the resistor was chosen to be 5V/0.1A=50Ω. The current gain of the transistor is 220, so to have the transistor drive 100 mA, the base current must be 50m/220=450µA.

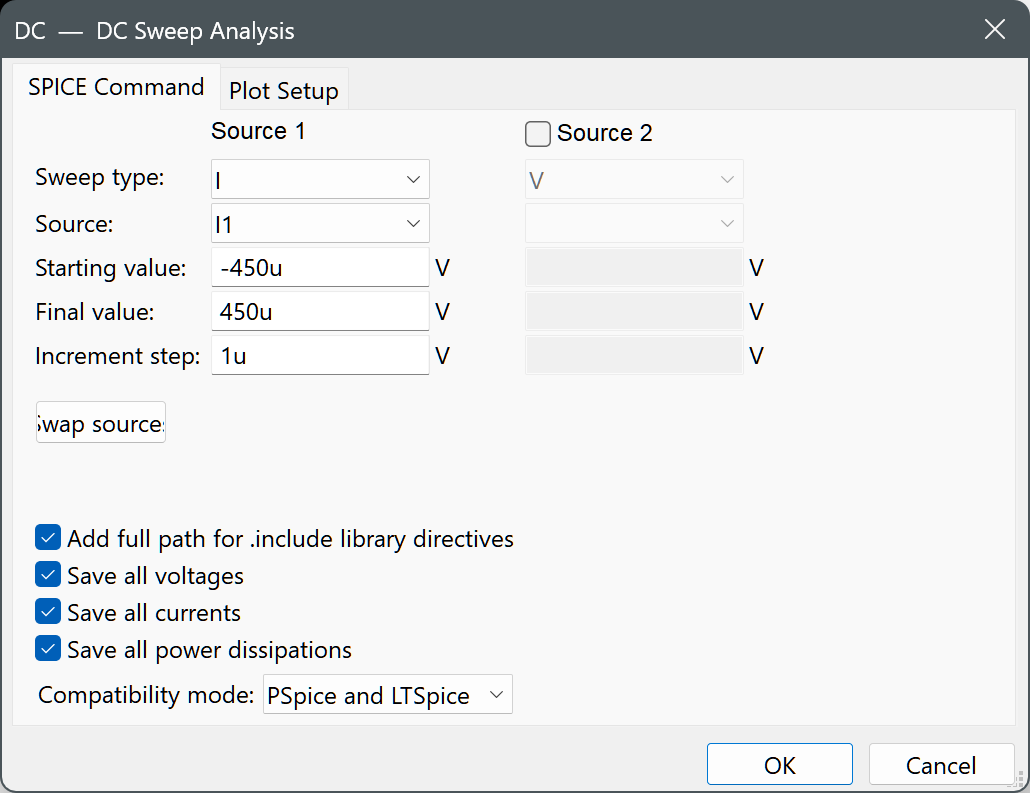
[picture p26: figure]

The simulation shows that the transistor remains closed below 0A, and opens between 0 and 450µA:

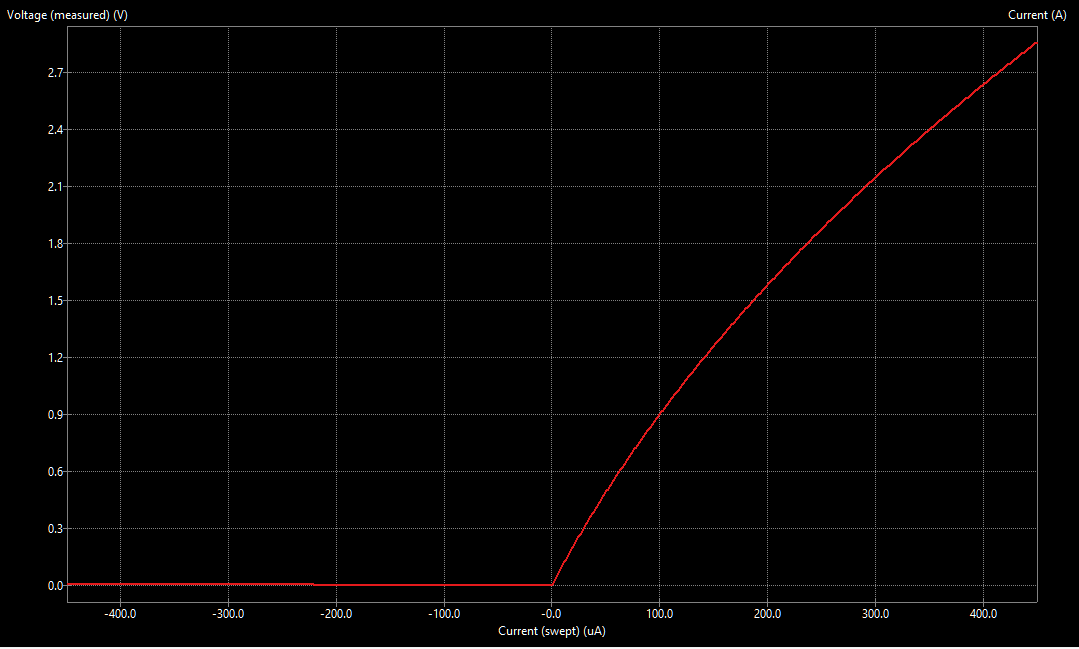
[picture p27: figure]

Now all components have been tested individually, the core of the OpenTherm circuit can be simulated to investigate if it is working as expected:

When U1 is closed, it will be modelled as a simple diode. When U1 is open, both U1 and D7 are omitted from the schematic. By driving the input with different currents, 4 situations can be simulated:

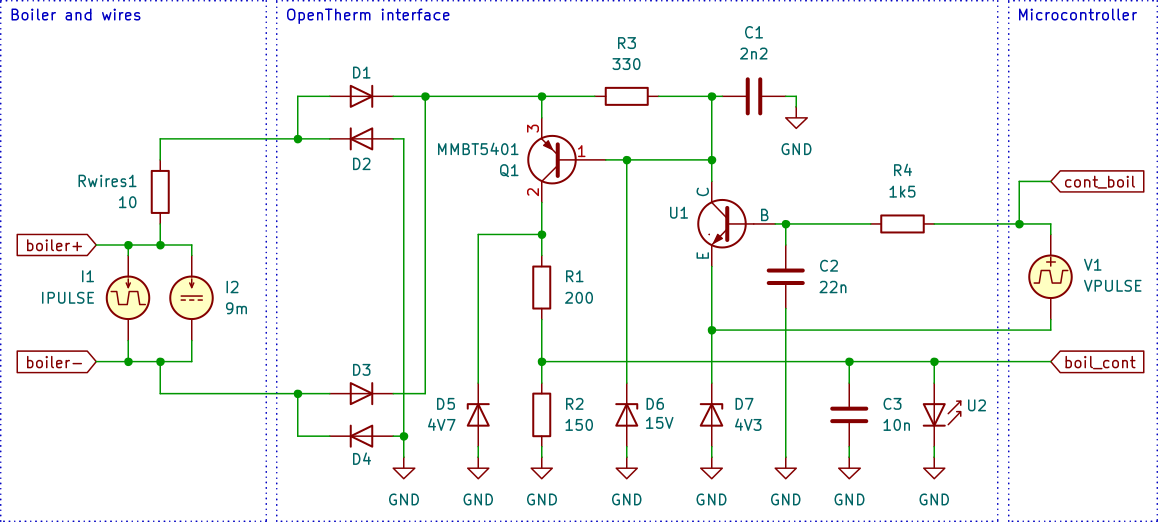
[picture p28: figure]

The components in the left rectangle mimic the boiler. The boiler provides a current on the wires of the OpenTherm bus, with a minimum current of 9 mA and a maximum current of 23 mA with a period of 1ms. The rise and fall times are specified as less than 50µs in the OpenTherm specification.

The interface is in the centre rectangle. The BC558A is replaced by a very common SMD version, the MMBT5401. The original optocouplers U1 and U2 (EL357N-G) were replaced by dummies for the simulation (a PNP transistor and an LED respectively), since a SPICE model of the EL357N-G was not available. Resistor R2 was increased from 100 Ω to 150 Ω to more clearly separate the vboil_cont signal from the forward voltage of the LED of the EL357N-G. Three small capacitors were added to reduce ripple on the signals.

The right rectangle represents the microcontroller. V1 provides a 1ms pulse which is delayed by 125 µs, so it is a quarter phase behind the current signal from the boiler. In reality, the boiler responds after a request from the controller is completed, so either current or the voltage are modulated.

The results of the simulation are:

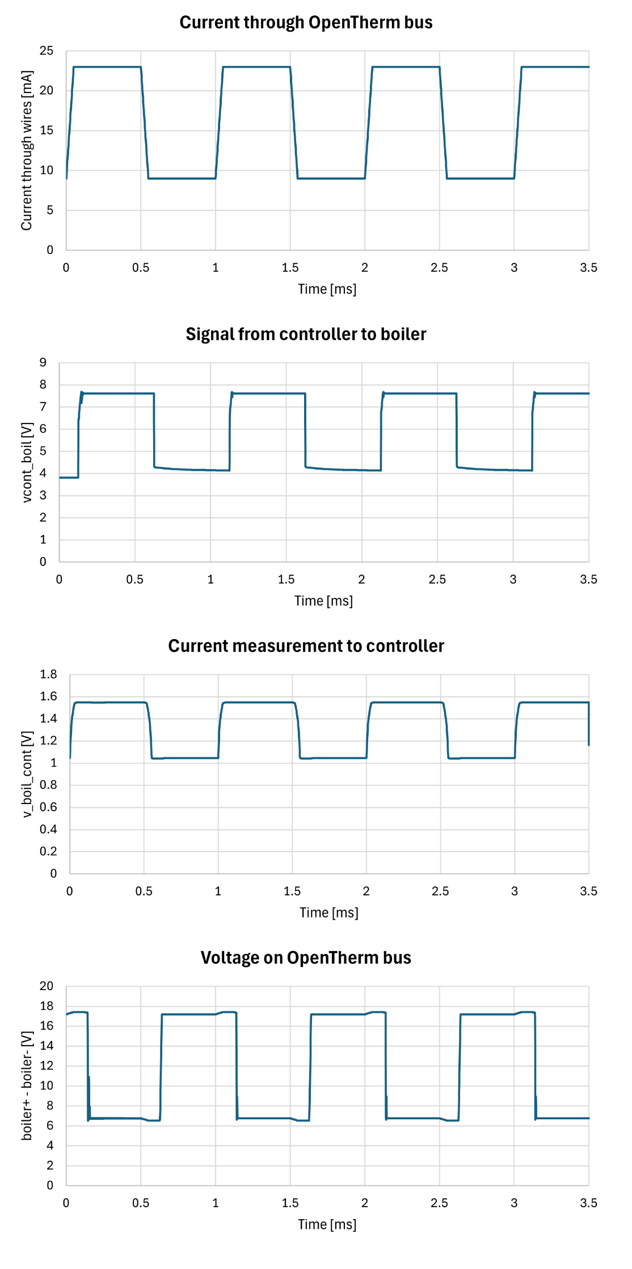
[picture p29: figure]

Conclusions:

1. Changes in the current signal modulated by the boiler do not interfere with the voltage signal modulated by the controller, or vice versa.
2. The 9…23 mA signal from the boiler translates into a 1.05…1.56 V signal for the LED of optocoupler U2. The LED of the EL357N-G has a forward voltage of typically 1.2 V and max. 1.4 V. The signal values are well outside of this range.
3. The output of the controller results in a voltage on the OpenTherm bus of 6.8 V or 17.4 V. This is outside the specified 7…15 V range of the OpenTherm specification.
4. The circuit performs according to the OpenTherm specification

# Specifications for components

Specifications for the components were derived from the simulations.

## Diodes D1…D4

Without margin, these diodes should be able to dissipate 20 mW and draw 25 mA of current.

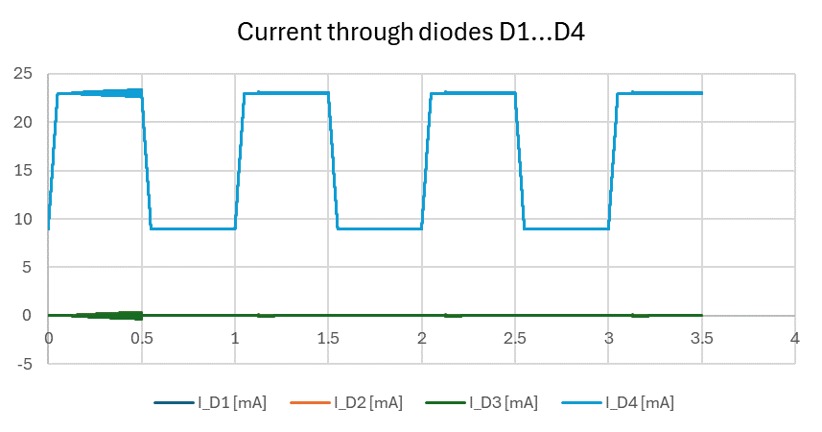
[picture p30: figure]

Property | | Symbol | | Unit | Required | 1N4148WS
Non-Repetitive Peak Reverse Voltage | | VRM | | V | 42 | 100
Average Rectified Output Current | | IO | | A | 25m | 150m
Power Dissipation | | PD | | W | 20 | 200m
Package | | | | | | SOD-323
JLCPCB | | | | | | C2128

## Zener D5, 4V7

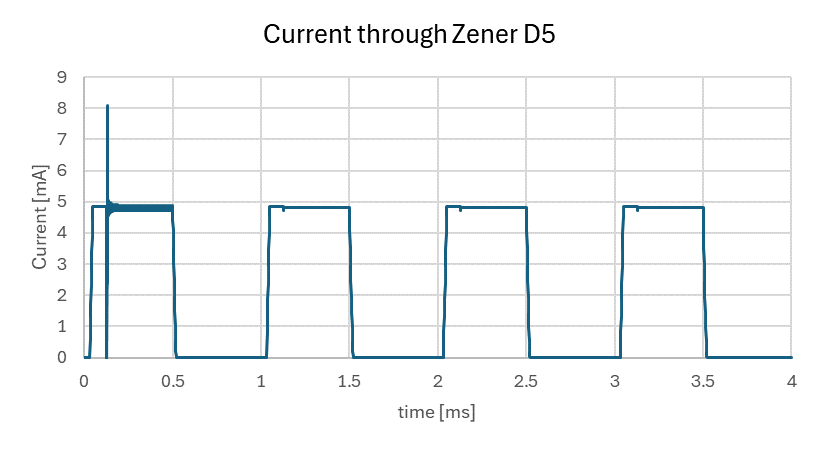
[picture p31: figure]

Property | Symbol | Unit | Required | BZT52C4V7S | BZX84C4V7
Zener voltage | Vz | V | 4.7 | 4.7 | 4.7
Power dissipated | PD | W | 24m | 200m | 350m
Zener current | Iz | A | 4.8m | Ok | ok
Package | | | | SOD-323 | SOT-23
JLCPCB | | | | C5190168 | C2926229
Stock | | | | 18723 | 22953

## Zener D6, 15

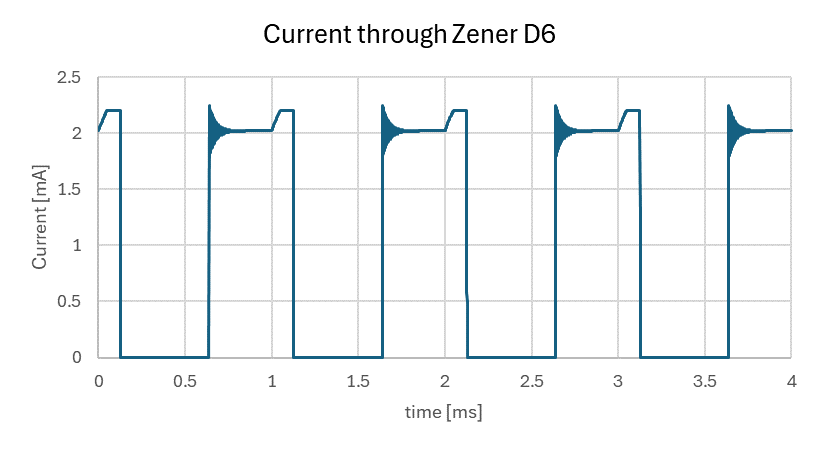
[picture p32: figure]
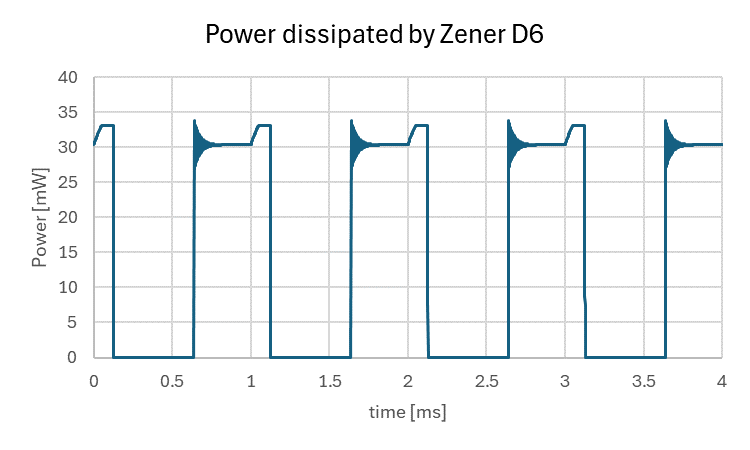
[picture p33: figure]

Property | Symbol | Unit | Required | | BZT52C15V | BZT52C15S
Zener voltage | Vz | V | 15 | | 13.8…15.6 | 13.8…15.6
Power dissipated | PD | W | 35m | | 500m | 200m
Zener current | Iz | A | 2.5mA | | ok | Ok
Package | | | | | SOD-123 | SOD-123
JLCPCB | | | | | C5299435 | C19077448
Stock | | | | | 6263 | 10668

## Zener D7, 4V3

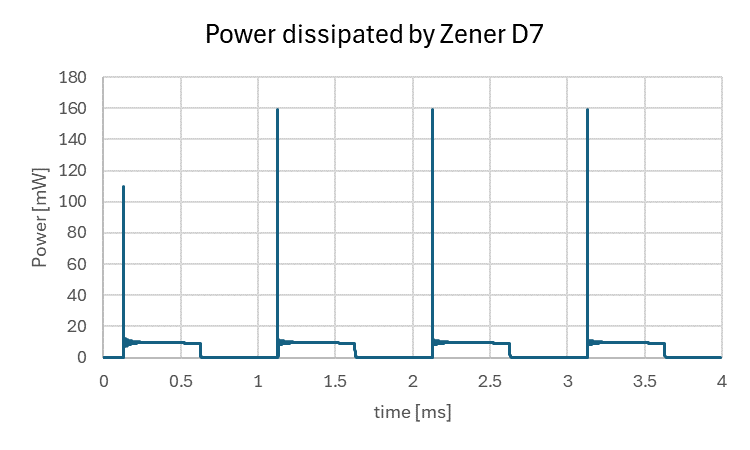
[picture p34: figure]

Property | Symbol | Unit | Required | | BZT52C4V3
Zener voltage | Vz | V | 4.3 | | 4.3
Power dissipated | PD | W | 35m | | 500m
Peak power | | W | 160m
Zener current | Iz | A | 3m | | ok
Package | | | | | SOD-123
JLCPCB | | | | | C726993
Stock | | | | | 11300

## Transistor Q1, BC558A

Property | Sym | Unit | Required | BC856A-7-F | MMBT2907A | PMBT3906,215
Emitter collector voltage | VCEO | V | 15 | 65 | 60 | 40
Collector current | IC | A | 40m | 100m | 600m | 200m
Base current | IB | A | 15m | 200m | | 100m
Power dissipation | PD | W | 250m | 310m | 300m | 250m
Package | | | | SOT-23 | SOT-23 | SOT-23
JLCPCB | | | | C460180 | C916373 | C8670
Stock | | | | 17393 | 173550 | 108572

## U1 Optocoupler EL357N(A)(TA)-G

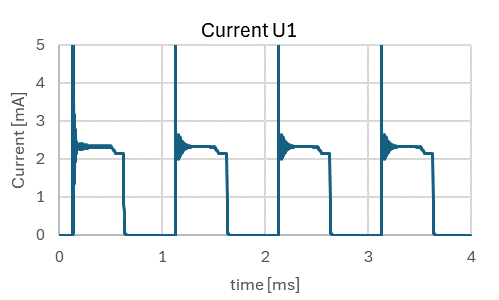
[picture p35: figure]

Property | Symbol | Unit | Required | EL357N(C)(TA)-G
Current | I | A | 3m
Power | P | W | 3m
Package | | | | SOP-4-2.54mm
JLCPCB | | | | C29981
Stock | | | | 667116

## Resistors R1…R4

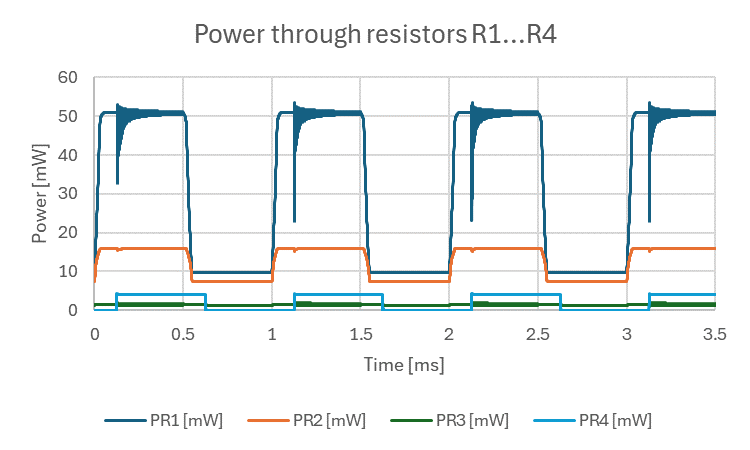
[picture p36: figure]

| | R1 | R2 | R3, R5 | R4
Resistance | Ω | 200 | 150 | 330 | 1k5
Power | W | 125m | 125m | 125m | 125m
Type | | 0805W8J0201T5E | 0805W8F1500T5E | 0805W8F3300T5E | 0805W8F1501T5E
Package | | 0805 | 0805 | 0805 | 0805
JLCPCB | | C17540 | C17471 | C17630 | C4310

## Capacitors

| | C1, C3 | C2, C4
Capacitance | F | 10n | 2n2
Rated voltage | V | 50 | 50
Type | | 0603B103K500NT | 0603B222K500NT
Package | | 0603 | 0603
JLCPCB | | C57112 | C1604

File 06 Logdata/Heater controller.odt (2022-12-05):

# Hoe het werkt

De measuredTemperature is de temperatuur die door de thermometer in de kamer wordt gemeten.

Het Setpoint is de temperatuur die het in de kamer moet zijn.

- Overdag staat deze meestal op 21°C.
- ‘s Nachts is deze 10°C
- Je kunt hem ook overrulen waardoor hij bijvoorbeeld ook op 20°C of 20.5°C kan staan

De temperatuurregelaar ziet er schematisch als volgt uit:


De rode waarden / pijltjes staan wel in de software maar worden niet naar de logfile geëxporteerd. Ze zitten dus niet in de dataset.

Er is gebruik gemaakt van een PID regelaar (https://nl.wikipedia.org/wiki/PID-regelaar) die de watertemperatuur requestedBoilerTemperature van de ketel bestuurt op basis van de gemeten kamertemperatuur measuredTemperature en de gewenste kamertemperatuur Setpoint.

Deze PID regelaar heeft intern de volgende waarden:

KP = 10 [-]

KI = 0.02 [1/s]

KD = 0 [s]

Omdat de laatste waarde 0 is wordt de D-actie dus eigenlijk niet gebruikt (ik twijfel eigenlijk of ik die wel goed heb geïmplementeerd in de software als ik hem aan zou zetten).

Er is een anti-windup maatregel (https://en.wikipedia.org/wiki/Integral_windup) op de I-actie gezet om te voorkomen dat deze heel hoog wordt als het setpoint veel hoger of lager is dan de gemeten temperatuur. Deze anti-windup betekent dat de I-actie niet verder mag oplopen als de uitgestuurde waarde al aan het einde van het regelbereik zit.

In de logfile zie je ook kolommen P, I en D. Zoals je in het schema kunt zien kun je de P, I en D waarden bij elkaar optellen om de requestedBoilerTemperature uit te rekenen. Dit is de gevraagde temperatuur van het water dat door de radiatoren stroomt. Het blokje wat er nog tussen zit zorgt ervoor dat de waarde niet beneden outputLow (=10°C) kan komen, en ook niet boven outputHigh (=80°C).

Omdat ik zeker wilde weten of de verwarming ‘s nachts wel echt uit gaat heb ik ook geïmplementeerd dat enableCentralHeating op ‘false’ wordt gezet als de Setpoint temperatuur minimaal 2°C lager is dan de measuredTemperature. Met andere woorden: als je ‘s avonds naar bed gaat, gaat het setpoint naar 10°C maar is het in de kamer nog 21°C. Het verschil is dan groter dan 2°C waardoor enableCentralHeating uit gaat. Dit had ik de eerste dagen nog niet geïmplementeerd dus het kan zijn dat dit de laatste twee dagen ander gedrag oplevert.

Met flameOn rapporteert de verwarmingsketel terug of de vlam van de brander wel of niet brandt. Verder meldt de ketel ook de echte temperatuur actualBoilerTemperature van het water terug.

Het warme water van de douche is apart geregeld. Ik stuur enableHotwater naar de ketel om aan te geven dat hij ook de douche van warm water mag voorzien (deze waarde is altijd true). Verder is er domesticHotWaterSetpoint. Dit is de gewenste waarde voor de watertemperatuur voor de douche. Deze stond in de eerste versie op 40°C, maar omdat Eliza toen een koud bad had heb ik die waarde verhoogd naar 55°C. De ketel rapporteert terug of isHotWaterActive wordt gebruikt (Y/N) en wat de werkelijke temperatuur van het warme water actualHotWaterTemperature is.

# Dingen waar ik benieuwd naar ben

## Gaat de kachel ‘s nachts wel uit?

Het verbaast me een beetje dat de measuredTemperature in de woonkamer ‘s nachts slechts tot 18°C lijkt af te koelen. Ik had verwacht dat het veel kouder zou worden. Staat de kachel echt uit?


Hoewel ik ‘s nachts enableCentralHeating uit zet (in de eerste dagen niet, heb ik later veranderd, maar ik weet niet of je de invloed daarvan op de dataset kan zien omdat enableCentralHeating zelf niet wordt gelogd) en requestedBoilerTemperature ook op 10°C staat, schommelt de actualBoilerTemperature tussen 30°C en 50°C. Gaat de ketel dan toch aan ‘s nachts?


Hier zie je bijvoorbeeld dat de watertemperatuur midden in de nacht in ene 17°C opwarmt terwijl isFlameOn N blijft:


Misschien gaat de vlam maar heel kort branden als de temperatuur onder de 30°C zakt maar is de vlam weer uit als de volgende regel in de dataset wordt toegevoegd. Mogelijk is die 30°C een instelling op de ketel zelf waar ik me niet van bewust ben. Het bijzondere is dan wel dat de actualBoilerTemperature soms wel naar 20°C daalt.

Ik heb de handleiding van de Remeha Avanti in de readonly directory gezet maar kon zo snel niets vinden.

## Kunnen we aan de dataset zien wat ons gasverbruik is?

Ik heb een tweede dataset gasverbruik.txt toegevoegd met ons gasverbruik in m³ per dag. Dit heb ik overgetypt uit de engie app.

Het lijkt er op dat ons gasverbruik de laatste tijd niet omhoog is gegaan, dus dat is goed nieuws.

Ik kan me voorstellen dat dit correleert met:

- de integraal van het positieve deel van d(actualBoilerTemperature)/dt (de ketel stookt alleen als dit een positief getal is, je levert geen gas terug als de temperatuur daalt)
- het aantal minuten per dat dat isHotWaterActive aan staat

Het is misschien wel lastig om met zo weinig data en correlatie vast te stellen omdat het gasverbruik per dag niet zo heel sterk varieert.

## Is de regelaar optimaal?

Als ik naar dit stukje grafiek kijk:


Zie je:

- dat measuredTemperature pas na een uur de juiste waarde heeft bereikt
- er vervolgens 1.3°C overshoot is
- de temperatuur verder heel nauwkeurig wordt geregeld

Dit kan vast beter op basis van de beschikbare meetwaarden. Ik denk aan:

- betere instellingen van P, I en D
- misschien een ander soort regelaar (machinelearning in plaats van PID?)
- een lerend systeem die bijvoorbeeld bijhoudt dat de verwarming alvast een uur van tevoren moet beginnen

Bij al die dingen is het wel belangrijk om te voorkomen dat het gasverbruik omhoog gaat. Ik wil ook oppassen dat we geen verkeerde waarden naar de ketel sturen waardoor de levensduur achteruit zou kunnen gaan.

Een verkeerd ingestelde PID regelaar kan gaan opslingeren waardoor het minder aangenaam in hui wordt en het gasverbruik zeker omhoog zal gaan.

## Kan het gasverbruik omlaag?

Ik weet ook niet zeker of de regelaar gedurende de dag te aggressief is afgesteld. Over de dag heen wijkt de teperatuur maximaal ongeveer een halve graad af van het setpoint.


Stel dat we de regelaar iets soepeler afstellen, zou dat invloed hebben op het gasverbruik?

Iets anders is of we measuredTemperature eigenlijk nog willen filteren. Nu zit er wat ruis op dit signaal, ik weet eigenlijk niet of dit erg is.

## Bijlage: werkende import van de logdata

import numpy as np

import pandas as pd

import matplotlib.pyplot as plt

import datetime

df = pd.read_csv('Logdata.txt', sep='\t', parse_dates=[['Date', 'Time']], index_col='Date_Time')

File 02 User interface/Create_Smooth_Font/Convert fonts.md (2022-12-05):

# Converting TTF and OTF fonts to smooth fonts
1. Download Processing IDE from https://processing.org/download
1. Copy truetype font to \data directory
1. Open Create_font.pde in processing
    * Change font name 
    * Change desired output size
1. Copy .vlw files to \data subdirectory under the sketch
1. Upload data to SPIFFS using "ESP32 Sketch data upload" tool
2. Ensure SPIFFS is loaded by encorporating SPIFFS.begin() in the code

The .vlw files must be uploaded to the processors FLASH filing system (SPIFFS, LittleFS or SD card) for use. Alternatively the .vlw files can be converted to C arrays (see "Smooth Font -> FLASH_Array" examples) and stored directly in FLASH as part of the compile process. The array based approach is convenient, provides performance improvements and is suitable where: either use of a filing system is undesirable, or the processor type (e.g. STM32) does not support a FLASH based filing sytem.

//String fontName ="Noway_Regular";  
String fontName ="Noway_Light";  
//String fontName ="Noway_Medium";

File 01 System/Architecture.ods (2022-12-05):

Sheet: Message flows
Event | Keyboard | Menu | Telegram | Controller | Display | Thermometer | Boiler | Config | Wifi | Time
Hardware button pressed | send key info to menu
 |  | decide action based on menu
 |  | request to controller
 |  |  |  | update settings
 |  |  |  | send information to display
 |  |  |  |  | update display
 |  |  |  |  | end of event
Telegram button received |  |  | menu dependent action
 |  |  | request to controller
 |  |  |  | update settings
 |  |  |  | prepare telegram message
 |  |  |  | request for telegram
 |  |  | update keyboard
 |  |  | Telegram message
 |  |  | end of event
Control boiler temperature |  |  |  |  |  | measure temperature
 |  |  |  |  |  | send temperature to controller
 |  |  |  | update boiler setpoint
 |  |  |  | request to boiler
 |  |  |  |  |  |  | send setpoint to boiler
 |  |  |  |  |  |  | request data from boiler
 |  |  |  |  |  |  | send data to telegram
 |  |  |  |  |  |  | send data to controller
 |  |  |  |  |  |  | send data to display
Load config |  |  |  |  |  |  |  | load config
 |  |  |  |  |  |  |  | send data to controller
 |  |  |  |  |  |  |  | send data to wifi
 |  |  |  |  |  |  |  | send data to time

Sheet: Menu
scnHome | Home
 |  | cmdSetpointHigher
 |  | cmdMenuMain
 |  | cmdSetpointLower
scnMain | Main menu
 |  | cmdMenuOverruleToday
 |  | cmdMenuOverruleTomorrow
 |  | cmdMenuOverruleMultipleDays
 |  | cmdMenuSettings
 |  | cmdMenuHome
scnOverruleToday | Overrule today
 |  | cmdWorkFromHome
 |  | cmdWorkAtOffice
 |  | cmdWeekend
 |  | cmdTodayAllDayAway
 |  | cmdTodayAutomatic
 |  | cmdMenuMain
scnOverruleTomorrow | Overrule tomorrow
 |  | cmdWorkFromHome
 |  | cmdWorkAtOffice
 |  | cmdWeekend
 |  | cmdTodayAllDayAway
 |  | cmdTodayAutomatic
 |  | cmdMenuMain
scnOverruleMultiple | Overrule multiple days
 |  | cmdMultipleMoreDays
 |  | cmdMultipleFewerDays
 |  | cmdMultipleDaySchedule
 |  | cmdMultipleAutomatic
 |  | cmdMenuMain
scnOverruleMultipleSchedule | Overrule multiple - schedule
 |  | cmdWorkFromHome
 |  | cmdWorkAtOffice
 |  | cmdWeekend
 |  | cmdTodayAllDayAway
 |  | cmdTodayAutomatic
 |  | cmdMenuOverruleMultipleDays
scnSettingsMain | Settings
 |  | cmdMenuTemperature
 |  | cmdMenuSensorOffset
 |  | cmdMenuWeekSchedule
 |  | cmdMenuHomeTimes
 |  | cmdMenuOfficeTimes
 |  | cmdMenuWeekendTimes
 |  | cmdMenuMain
scnSettingsTemperature | Temperature settings
 |  | cmdHighTemperatureUp
 |  | cmdHighTemperatureDown
 |  | cmdLowTemperatureUp
 |  | cmdLowTemperatureDown
 |  | cmdMenuSettings
scnSettingsSensorOffset | Adjust sensor offset
 |  | cmdSensorOffsetUp
 |  | cmdSensorOffsetDown
 |  | cmdMenuSettings
scnSettingsWeekSchedule | Set week schedule
 |  | cmdMonday
 |  | cmdTuesday
 |  | cmdWednesday
 |  | cmdThursday
 |  | cmdFriday
 |  | cmdSaturday
 |  | cmdSunday
 |  | cmdMenuSettings
scnSettingsDaySchedule | Set day schedule
 |  | cmdWorkFromHome
 |  | cmdWorkAtOffice
 |  | cmdWeekend
 |  | cmdTodayAllDayAway
 |  | cmdMenuWeekSchedule
scnSettingsHomeTimes | Set home times
 |  | cmdHomeWakeUpLater
 |  | cmdHomeWakeUpEarlier
 |  | cmdHomeGoToSleepLater
 |  | cmdHomeGoToSleepEarlier
 |  | cmdMenuSettings
scnSettingsOfficeTimes | Set office times
 |  | cmdOfficeWakeUpLater
 |  | cmdOfficeWakeUpEarlier
 |  | cmdOfficeLeaveLater
 |  | cmdOfficeLeaveEarlier
 |  | cmdOfficeComeHomeLater
 |  | cmdOfficeComeHomeEarlier
 |  | cmdHomeGoToSleepLater
 |  | cmdHomeGoToSleepEarlier
 |  | cmdMenuSettings
scnSettingsWeekendTimes | Set weekend times
 |  | cmdWeekendWakeUpLater
 |  | cmdWeekendWakeUpEarlier
 |  | cmdWeekendGoToSleepLater
 |  | cmdWeekendGoToSleepEarlier
 |  | cmdMenuSettings

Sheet: Sheet3
Event | Actions required | Sender | Receiving queue | Command
System starts up | Main loop sends message to controller | sndMenu | controllerQueue | cmdUpdateScreen
 |  | sndController | displayQueue | cmdUpdateScreen
User presses hardware key up | Menu handles key press | sndKeyboard | menuQueue | cmdKeyUp
User presses hardware key select | Menu handles key press | sndKeyboard | menuQueue | cmdKeySelect
User presses hardware key down | Menu handles key press | sndKeyboard | menuQueue | cmdKeyDown
User presses a button | Backlight switches on Telegram temporarily disabled | sndMenu | backlightQueue | cmdBacklightOn | Change to cmdKeyPressed?
Check if this is needed! |  | sndDisplay | backlightQueue | cmdBacklightOn
It has been some time since the last key was pressed | Backlight switches off Telegram reactivated | sndBacklight | menuQueue | cmdMenuHome
Backlight dimming completed | Menu switches back to home screen | sndBacklight | menuQueue | cmdMenuHome
Update a menu screen |  | sndMenu | displayQueue | cmdUpdateScreen
Telegram has changed something in the controller Switch backlight on |  | sndTelegram | backlightQueue | cmdUpdateScreen

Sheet: Sheet4
14:56:12.368 | Loading config data
14:56:12.404 | Config loaded
14:56:12.404 | Initializing temperature sensors and boiler
14:56:12.404 | 0 device(s) found on OneWire bus
14:56:12.404 | Parasite power on OneWire bus is: OFF
14:56:14.121 | Initializing backlight
14:56:14.121 | Initializing display
14:56:14.623 | Initializing controller
14:56:14.623 | Initializing WiFi
14:56:19.331 | WiFi connected to HenkJanHot
14:56:19.331 | Initializing Telegram handler
14:58:49.395 | Initializing menu
14:58:49.395 | Initializing keyboard
14:58:49.395 | Sending cmdUpdateScreen mesage to controller
14:58:49.395 | Configuring watchdog
14:58:49.395 | Setup finished
14:58:49.395
14:58:49.395
14:58:50.178 | Thermometer | Display [Update screen] k=0
14:58:50.178 | Display::processMessage() screen: Home command: Main menu
14:58:50.335 | Display::displayHomeScreen()
14:58:50.695 | telegramHandler.checkNewMessages()
14:58:53.822 | Menu | Controller [Update screen] k=0
14:58:53.822 | Controller::control()
14:58:53.822 | requestTimeZoneIfNeeded
14:58:53.822 | Requesting time zone and daylight saving time
14:58:53.822 | Time zone [Europe/Amsterdam], request [http://worldtimeapi.org/api/timezone/Europe/Amsterdam]
14:58:54.210 | Time zone difference retrieved
14:58:54.210 | syncTimeIfNeeded
14:58:54.210 | Wifi connected: Y
14:58:54.210 | Total: 4764.0 ± nan ms max=4764.0 ms
14:58:54.210 | Temperature: 751.0 ± nan ms max=751.0 Menu: 0.0 ± nan ms max=0.0 ms
14:58:54.210 | Display: 549.0 ± nan ms max=549.0 ms
14:58:54.210 | Telegram: 3094.0 ± nan ms max=3094.0 mController: 0.0 ± nan ms max=0.0 ms
14:58:54.210 | Backlight: 0.0 ± nan ms max=0.0 ms
14:58:54.210 | WiFi: 0.0 ± nan ms max=0.0 ms
14:58:54.210 | Time: 370.0 ± nan ms max=370.0 ms
14:58:54.210
14:58:54.210 | Software version: 1.0.4
14:58:54.210 |  | Time since reboot: 2 minutes 42 seconds
14:58:54.210 |  | Temperature measurement successful: N
14:58:54.210 |  | Total free bytes in the heap: 138524
14:58:54.260 |  | Total bytes allocated to data in the heap: 131156
14:58:54.260 |  | Size of the largest free block in the heap: 75796
14:58:54.260 |  | Lifetime minimum free heap size: 60288
14:58:54.260 |  | Number of blocks allocated in the heap: 1086
14:58:54.260 |  | Number of free blocks in the heap: 44
14:58:54.260 |  | Total number of blocks in the heap: 1130
14:58:54.260 | Controller | Display [Update screen] k=0
14:58:54.260 | Display::processMessage() screen: Home command: Main menu
14:58:54.260 | Display::displayHomeScreen()
14:58:54.622 | Thermometer | Controller [Control temperature] k=0
14:58:54.622 | Controller::control()
14:58:54.622 | Wifi | Display [Update screen] k=0
14:58:54.622 | Display::processMessage() screen: Home command: Main menu
14:58:54.622 | Display::displayHomeScreen()
14:58:54.960 | telegramHandler.checkNewMessages()
14:59:00.279 | telegramHandler.checkNewMessages()
14:59:21.045 | syncTimeIfNeeded
14:59:21.827 | BoilerCommunicate()
14:59:22.860 | Boiler response: timeout
14:59:23.893 | Thermometer | Display [Update screen] k=0
14:59:23.893 | Display::processMessage() screen: Home command: Main menu
14:59:23.893 | Display::displayHomeScreen()
14:59:24.278 | Boiler | Telegram [Disable Telegram] k=0
14:59:24.278 | TelegramHandler::handleQueueCommand() for chatID:
14:59:24.278 | Thermometer | Controller [Control temperature] k=0
14:59:24.278 | Controller::control()
14:59:24.278 | Telegram | Backlight [Turn backlight on] k=0
14:59:24.278 | Boiler | Display [Boiler sending icon] k=0
14:59:24.278 | Display::processMessage() screen: Home command: Main menu
14:59:24.278 | Display: Icon boiler transmitting
14:59:24.328 | Boiler | Telegram [Enable Telegram] k=0
14:59:24.328 | TelegramHandler::handleQueueCommand() for chatID:
14:59:24.328 | telegramHandler.checkNewMessages()
14:59:57.337 | Telegram | Backlight [Turn backlight on] k=0
14:59:57.337 | syncTimeIfNeeded
14:59:57.337 | Wifi connected: Y
14:59:57.337 | Total: 4.1 ± 310.9 ms max=33068.0 ms
14:59:57.337 | Temperature: 0.2 ± 22.8 ms max=2820.0 Menu: 0.0 ± 0.1 ms max=1.0 ms
14:59:57.337 | Display: 0.1 ± 6.5 ms max=549.0 ms
14:59:57.337 | Telegram: 3.7 ± 307.8 ms max=33006.0 mController: 0.0 ± 0.1 ms max=3.0 ms
14:59:57.337 | Backlight: 0.0 ± 0.1 ms max=4.0 ms
14:59:57.337 | WiFi: 0.0 ± 0.1 ms max=1.0 ms
14:59:57.337 | Time: 0.0 ± 2.9 ms max=370.0 ms
14:59:57.337
14:59:57.337 | Software version: 1.0.4
14:59:57.337 |  | Time since reboot: 3 minutes 45 seconds
14:59:57.337 |  | Temperature measurement successful: N
14:59:57.381 |  | Total free bytes in the heap: 131900
14:59:57.381 |  | Total bytes allocated to data in the heap: 137564
14:59:57.381 |  | Size of the largest free block in the heap: 75796
14:59:57.381 |  | Lifetime minimum free heap size: 60256
14:59:57.381 |  | Number of blocks allocated in the heap: 1099
14:59:57.381 |  | Number of free blocks in the heap: 46
14:59:57.381 |  | Total number of blocks in the heap: 1145
14:59:58.124 | Boiler | Display [Update screen] k=0
14:59:58.124 | Display::processMessage() screen: Home command: Main menu
14:59:58.124 | Display::displayHomeScreen()
14:59:58.466 | telegramHandler.checkNewMessages()
15:00:12.827 | Thermometer | Controller [Control temperature] k=0
15:00:12.827 | Controller::control()
15:00:12.827 | WeekendWakeUp
15:00:12.827 | syncTimeIfNeeded
15:00:12.827 | Time synched: 15:00:12
15:00:12.827 | Telegram | Display [Update screen] k=0
15:00:12.827 | Display::processMessage() screen: Home command: Main menu
15:00:12.827 | Display::displayHomeScreen()
15:00:13.149 | Telegram | Display [Update screen] k=0
15:00:13.149 | Display::processMessage() screen: Home command: Main menu
15:00:13.149 | Display::displayHomeScreen()
15:00:13.429 | Thermometer | Display [Update screen] k=0
15:00:13.429 | Display::processMessage() screen: Home command: Main menu
15:00:13.429 | Display::displayHomeScreen()
15:00:13.755 | Wifi | Display [Update screen] k=0
15:00:13.755 | Display::processMessage() screen: Home command: Main menu
15:00:13.755 | Display::displayHomeScreen()
15:00:14.034 | telegramHandler.checkNewMessages()
15:01:14.227 | Wifi connected: Y
15:01:14.317 | Total: 8.8 ± 578.8 ms max=60505.0 ms
15:01:14.317 | Temperature: 0.3 ± 23.6 ms max=2820.0 Menu: 0.0 ± 0.1 ms max=1.0 ms
15:01:14.317 | Display: 0.2 ± 8.5 ms max=549.0 ms
15:01:14.317 | Telegram: 8.3 ± 573.4 ms max=60202.0 mController: 0.0 ± 0.1 ms max=3.0 ms
15:01:14.317 | Backlight: 0.0 ± 0.1 ms max=4.0 ms
15:01:14.317 | WiFi: 0.0 ± 0.1 ms max=1.0 ms
15:01:14.317 | Time: 0.0 ± 2.9 ms max=370.0 ms
15:01:14.317
15:01:14.317 | Software version: 1.0.4
15:01:14.317 |  | Time since reboot: 5 minutes 2 seconds
15:01:14.317 |  | Temperature measurement successful: N
15:01:14.317 |  | Total free bytes in the heap: 142192
15:01:14.317 |  | Total bytes allocated to data in the heap: 127292
15:01:14.317 |  | Size of the largest free block in the heap: 60880
15:01:14.317 |  | Lifetime minimum free heap size: 59456
15:01:14.317 |  | Number of blocks allocated in the heap: 1096
15:01:14.317 |  | Number of free blocks in the heap: 53
15:01:14.317 |  | Total number of blocks in the heap: 1149
15:01:15.058 | 0 device(s) found on OneWire bus
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

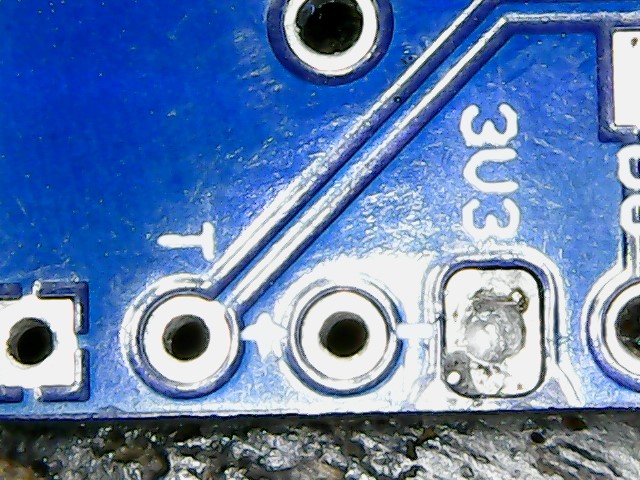
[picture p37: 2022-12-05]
04 Electrical/Redesign PCB 3.0/Photos DIYless/B05.jpg

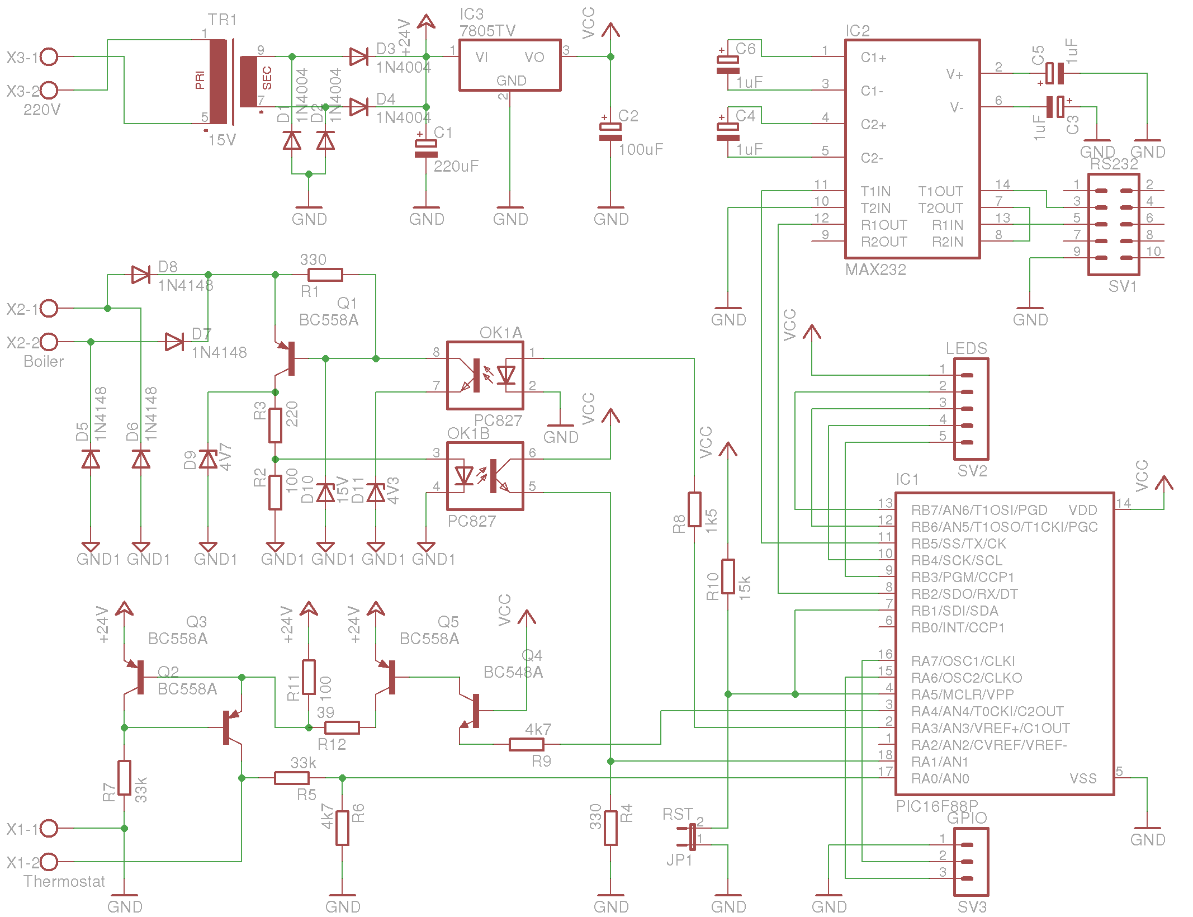
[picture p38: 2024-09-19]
04 Electrical/Redesign PCB 3.0/Interface board example project/Background info/otgw-big-sch.png

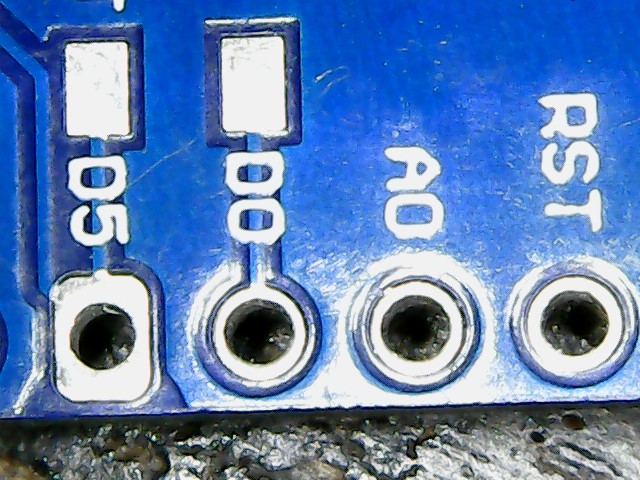
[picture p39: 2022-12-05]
04 Electrical/Redesign PCB 3.0/Photos DIYless/B03.jpg

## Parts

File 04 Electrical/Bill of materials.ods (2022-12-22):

Item | Count | Name | Manufacturer | Type | Manufacturer code | Supplier | Supplier code | Cost | Supplier link | Manufacturer link
1 | 1 | ESP32 |  | MH-ET Live minikit |  | Aliexpress |  | € 4.50
2 | 1 | Touch screen 320x240 |  | ILI9341 Touch (red) |  | Aliexpress |  | € 5.96
3 | 1 | Opentherm | DIYless | Mastershield |  | DIYless |  | € 14.95
4 | 4 | Temperature sensor | Maxim | DS18B20 |  | Aliexpress |  | € 0.31
5 | 1 | PCB connector | Phoenix | MSTB-2,5-2-G |  |  |  | € 3.66
6 | 1 | Cable connector | Phoenix | MSTB 2,5 2-ST |  |  |  | € 2.95
 | € 33.27 | Total cost

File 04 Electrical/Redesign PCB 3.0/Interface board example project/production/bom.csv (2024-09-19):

Designator | Footprint | Quantity | Value | LCSC Part #
D1, D2, D3, D4 | SOD-323_L1.8-W1.3-LS2.5-RD | 4 | 1N4148WS_T4 | C2128
D5 | SOD-323_L1.8-W1.3-LS2.5-RD | 1 | 4V7 | C353517
D6 | SOD-123_L2.7-W1.6-LS3.7-RD-1 | 1 | 15V | C2104
D7 | SOD-123_L2.7-W1.6-LS3.7-RD-1 | 1 | 4V3 | C726993
J1 | TerminalBlock_RND_205-00001_1x02_P5.00mm_Horizontal | 1 | Boiler | C395849
J2 | TerminalBlock_4Ucon_1x04_P3.50mm_Vertical | 1 | Screw_Terminal_01x04 | C557656
Q1 | SOT-23-5_L3.0-W1.7-P0.95-LS2.8-BL | 1 | BC858 | C549539
R1 | 0805_2012Metric | 1 | 0805,220 | C17557
R2, R3 | 0603_1608Metric | 2 | 0603,330 | C23138
R4 | 0402_1005Metric | 1 | 0402,1.5k | C25867
R6 | 1206_3216Metric | 1 | 1206,100 | C17901
U1, U2 | OPTO-SMD-4_L4.4-W4.1-P2.54-LS7.0-TL | 2 | EL357N(C)(TA)-G | C29981

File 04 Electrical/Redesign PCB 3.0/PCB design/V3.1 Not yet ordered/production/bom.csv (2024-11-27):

Designator | Footprint | Quantity | Value | LCSC Part #
C1, C4 | 0603 | 2 | 1u
C2, C6, C7 | 0603 | 3 | 0.1u
C3, C5, C8 | 0402 | 3 | 10u
C9 | 0805 | 1 | 22u
D1, D6 | 0603 | 2 | XL-1608UGC-04
D10, D7, D8, D9 | D_SOD-323 | 4 | 1N4148WS
D11 | D_SOD-323 | 1 | BZT52C4V7S
D12 | D_SOD-123 | 1 | BZT52C15V
D13 | D_SOD-123 | 1 | BZT52C4V3
D14, D15, D16, D17, D18 | D_SOD-882 | 5 | LESD8D3.3CAT5G-ES
D2, D3, D4 | D_SOD-523 | 3 | BSD5C051L
D5 | D_SOD-123 | 1 | 1N5819HW-7-F
J1 | USB_C_Receptacle_GCT_USB4105-xx-A_16P_TopMnt_Horizontal | 1 | USB-C port
J2 | JST_SH_SM02B-SRSS-TB_1x02-1MP_P1.00mm_Horizontal | 1 | Boiler
Q1 | SOT-23 | 1 | MMBT2907A
R1, R3 | 0603 | 2 | 10k
R10 | 0805 | 1 | 1k5
R11, R9 | 0805 | 2 | 330
R12, R4, R5 | 0603 | 3 | 4k7
R2, R6 | 0603 | 2 | 5k1
R7 | 0805 | 1 | 180
R8 | 0805 | 1 | 100
SW_1 | SW_SPST_TL3342 | 1 | EN
SW_2 | SW_SPST_TL3342 | 1 | BOOT
SW_3 | SW_SPST_TL3342 | 1 | HOME
SW_4 | SW_SPST_TL3342 | 1 | UP
SW_5 | SW_SPST_TL3342 | 1 | DOWN
SW_6 | SW_SPST_TL3342 | 1 | CONFIRM
SW_7 | SW_SPST_TL3342 | 1 | BACK
TP1 | TestPoint_Keystone_5015_Micro-Minature | 1 | 5V | C5199798
TP2 | TestPoint_Keystone_5015_Micro-Minature | 1 | 3V3 | C5199798
TP3 | TestPoint_Keystone_5015_Micro-Minature | 1 | GND1 | C5199798
TP4 | TestPoint_Keystone_5015_Micro-Minature | 1 | GND | C5199798
TP5 | TestPoint_Keystone_5015_Micro-Minature | 1 | opnthm | C5199798
TP6 | TestPoint_Keystone_5015_Micro-Minature | 1 | B1 | C5199798
TP7 | TestPoint_Keystone_5015_Micro-Minature | 1 | B2 | C5199798
U1 | ESP32-S3-WROOM-1 | 1 | ESP32-S3-WROOM-1-N8R2
U2 | TO-252-2 | 1 | UZ1086L-33-TN3-R
U3, U4 | SO-4_4.4x3.6mm_P2.54mm | 2 | EL357N-G

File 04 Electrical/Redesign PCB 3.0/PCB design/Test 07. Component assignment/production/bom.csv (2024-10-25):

Designator | Footprint | Quantity | Value | LCSC Part #
C1, C3 | 0603 | 2 | 10n | C57112
C2, C4 | 0603 | 2 | 2n2 | C1604
D1, D2, D3, D4 | D_SOD-323 | 4 | 1N4148WS | C2128
D5 | D_SOD-323 | 1 | BZT52C4V7S | C5190168
D6 | D_SOD-123 | 1 | BZT52C15V | C5299435
D7 | D_SOD-123 | 1 | BZT52C4V3 | C726993
J1 | TerminalBlock_bornier-2_P5.08mm | 1 | OpenTherm
J2 | TerminalBlock_bornier-4_P5.08mm | 1 | Controller
Q1 | SOT-23 | 1 | MMBT2907A | C916373
R1 | 0805 | 1 | 200 | C17540
R2 | 0805 | 1 | 150 | C17471
R3, R5 | 0805 | 2 | 330 | C17630
R4 | 0805 | 1 | 1k5 | C4310
U1, U2 | OPTO_EL357N-G | 2 | EL357N-G | C29981

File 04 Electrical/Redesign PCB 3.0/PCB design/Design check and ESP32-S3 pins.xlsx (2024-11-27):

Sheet: Checklist
Check all IO of ESP32 | v |  | Here’s a checklist for designing a PCB in KiCad for outsourcing to JLCPCB:
Check if SPI bus display | v
Check if SPI bus SD card | v |  | Design Considerations
Check bus of TOF sensor | v |  |  | 1. Board Dimensions
Check onewire bus | v | v |  |  | Verify overall dimensions, ensuring they fit within JLCPCB's limits (e.g., max 600 mm × 600 mm).
Check capacitors opentherm circuit | v | v |  |  | Ensure board outline is correctly defined on the Edge.Cuts layer.
Check all footprints | v |  |  | 2. Layer Setup
Logo for PCB | v | v |  |  | Choose the correct number of layers (e.g., 2-layer, 4-layer) and stackup configuration.
Remove unused field names in components | v | v |  |  | Assign proper copper thickness (default is 1 oz, but JLCPCB offers other options).
Check dimensions of display pins |  |  |  | 3. Design Rules
Check all JLCPCB numbers | v |  |  |  | Set minimum trace width and clearance to JLCPCB's capabilities (e.g., 0.1 mm for standard services).
Correct J3, include MP conncetions in symbol | v |  |  |  |  | Trace width | 5 | mil | 0.127 | mm | for 1-2 layer PCB
 |  |  |  |  | Verify via and drill hole sizes (minimum 0.2 mm drill hole, 0.4 mm pad size for standard).
 |  |  |  | 4. Component Placement
 |  |  |  |  | Place components with sufficient spacing for soldering.
 |  | v |  |  | Ensure orientation markings for polarized components like diodes and electrolytic capacitors are clear.
 |  |  |  | 5. Footprints
 |  | v |  |  | Use verified footprints that match your components and check against the manufacturer’s datasheets.
 |  | v |  |  | Double-check the pad sizes and hole sizes for through-hole components.
 |  |  |  | 6. Designators
 |  | v |  |  | Ensure all components have reference designators on the Silkscreen layer.
 |  | v |  |  | Avoid silkscreen text overlapping with pads or vias.
 |  |  | Electrical Considerations
 |  |  |  | 7. Netlist Checks
 |  | v |  |  | Perform an Electrical Rules Check (ERC) to identify missing connections or errors.
 |  | v |  |  | Verify that all critical nets (e.g., power, ground) are correctly connected.
 |  |  |  | 8. Copper Layers
 |  | v |  |  | Add proper ground planes and power planes.
 |  | v |  |  | Ensure that no floating copper areas exist.
 |  |  |  | 9. High-Speed Signals
 |  | v |  |  | For high-speed designs, verify impedance control (use JLCPCB’s impedance guidelines if needed).
 |  | v |  |  | Route differential pairs and match lengths for high-speed signals.
 |  |  | Mechanical Considerations
 |  |  |  | 10. Drills
 |  | v |  |  | Verify that all drill holes (vias, mounting holes, etc.) meet JLCPCB's minimum size requirements.
 |  | v |  |  | Ensure plated and non-plated holes are correctly defined.
 |  |  |  | 11. Keep-Out Zones
 |  | v |  |  | Define zones for keep-out areas to avoid components/vias in specific regions (e.g., mounting holes).
 |  |  |  | 12. Panelization
 |  | v |  |  | If needed, design a panelized version of the board. JLCPCB can panelize for you, but you may save costs by doing it yourself.
 |  |  | File Preparation
 |  |  |  | 13. Gerber Files
 |  | v |  |  | Export Gerber files from KiCad with the following layers:
 |  | v |  |  |  | F.Cu, B.Cu (and inner layers for multilayer boards)
 |  | v |  |  |  | F.Mask, B.Mask
 |  | v |  |  |  | F.SilkS, B.SilkS
 |  | v |  |  |  | Edge.Cuts
 |  | v |  |  |  | Include Drill files in Excellon format.
 |  |  |  | 14. Design Rule Check (DRC)
 |  | v |  |  | Run a DRC to catch violations like clearance issues, minimum width problems, or unconnected nets.
 |  |  |  | 15. Assembly Files (if needed)
 |  |  |  |  | For assembly services:
 |  | v |  |  |  | Generate a Pick and Place (PnP) file with component positions.
 |  | v |  |  |  | Create a BOM (Bill of Materials) with exact part numbers (preferably using JLCPCB’s SMT library).
 |  | v |  |  | Submission to JLCPCB
 |  |  |  | 16. File Review
 |  | v |  |  | Review all generated files in a Gerber viewer (e.g., JLCPCB’s online viewer).
 |  | v |  |  | Ensure files align with the board design and specifications.
 |  |  |  | 17. Order Details
 |  | v |  |  | Verify details like layer count, solder mask color, silk color, and surface finish (e.g., HASL, ENIG).
 |  | v |  |  | Check production time and quantity.
 |  |  |  | 18. Optional Testing
 |  | v |  |  | If needed, include test points for in-circuit testing (ICT) or functional testing.
 |  |  | Miscellaneous
 |  |  |  | 19. Solder Mask
 |  | v |  |  | Ensure no solder mask over pads for soldered components.
 |  | v |  |  | Add solder mask openings for test points if applicable.
 |  |  |  | 20. Design for Manufacturability (DFM)
 |  | v |  |  | Avoid sharp corners on copper (use rounded traces for high-current paths).
 |  | v |  |  | Check that vias don't interfere with pads.
 |  |  | By following this checklist, you can ensure your PCB is optimized for manufacturing at JLCPCB!

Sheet: Bill of Materials
Reference | Value | LCSC Part # | Footprint | Stock | Description | Comment | Datasheet
C1,C4 | 1u | C15849 | Capacitor_SMD:C_0603_1608Metric | 6999268 | Unpolarized capacitor |  | ~
C2,C6,C7 | 0.1u | C14663 | Capacitor_SMD:C_0603_1608Metric | 49145410 | Unpolarized capacitor |  | ~
C3,C5,C8 | 10u | C15525 | Capacitor_SMD:C_0402_1005Metric | 5863900 | Unpolarized capacitor |  | ~
C9 | 22u | C45783 | Capacitor_SMD:C_0805_2012Metric | 3800678 | Unpolarized capacitor |  | ~
D1,D6 | XL-1608UGC-04 | C965804 | LED_SMD:LED_0603_1608Metric | 959405 | LED, green, 520nm |  | https://wmsc.lcsc.com/wmsc/upload/file/pdf/v2/lcsc/2402181505_XINGLIGHT-XL-1608UGC-04_C965804.pdf
D2,D3,D4 | BSD5C051L | C151983 | Diode_SMD:D_SOD-523 | 64983
D5 | 1N5819HW-7-F | C82544 | Diode_SMD:D_SOD-123 | 198180 | Diode |  | ~
D7,D8,D9,D10 | 1N4148WS | C2128 | Diode_SMD:D_SOD-323 | 2278397 | Diode for simulation or PCB |  | https://ngspice.sourceforge.io/docs/ngspice-html-manual/manual.xhtml#cha_DIODEs
D11 | BZT52C4V7S | C5190168 | Diode_SMD:D_SOD-323 | 9583 | Zener diode |  | ~
D12 | BZT52C15V | C5299435 | Diode_SMD:D_SOD-123 | 4378 | Zener diode |  | ~
D13 | BZT52C4V3 | C726993 | Diode_SMD:D_SOD-123 | 6606 | Zener diode |  | ~
D14,D15,D16,D17,D18 | LESD8D3.3CAT5G-ES | C5199186 | Diode_SMD:D_SOD-882 | 23806 | 6A 80W 10V 3.7V Bidirectional 3.3V DFN1006-2L ESD and Surge Protection (TVS/ESD) ROHS |  | https://wmsc.lcsc.com/wmsc/upload/file/pdf/v2/lcsc/2210171700_ElecSuper-LESD8D3-3CAT5G-ES_C5199186.pdf
J1 | USB-C port | C2765186 | Connector_USB:USB_C_Receptacle_GCT_USB4105-xx-A_16P_TopMnt_Horizontal | 52367 | USB 2.0-only 16P Type-C Receptacle connector |  | https://www.usb.org/sites/default/files/documents/usb_type-c.zip
J2 | Test connector |  | Connector_PinHeader_2.54mm:PinHeader_1x06_P2.54mm_Vertical |  | Generic connector, single row, 01x06, script generated |  | ~
J3 | Boiler | C160402 | Connector_JST:JST_SH_SM02B-SRSS-TB_1x02-1MP_P1.00mm_Horizontal | 1266817 | Generic connector, single row, 01x02, script generated |  | https://www.lcsc.com/datasheet/lcsc_datasheet_2304140030_JST-SM02B-SRSS-TB-LF-SN_C160402.pdf
J4 | VL6180 |  | Connector_PinHeader_2.00mm:PinHeader_1x06_P2.00mm_Vertical |  | Generic connector, single row, 01x06, script generated |  | ~
Q1 | MMBT2907A | C916373 | Package_TO_SOT_SMD:SOT-23 | 25537 | PNP transistor, base/collector/emitter |  | ~
R1,R3 | 10k | C25804 | Resistor_SMD:R_0603_1608Metric | 24832802 | Resistor |  | ~
R2,R6 | 5k1 | C23186 | Resistor_SMD:R_0603_1608Metric | 4255582 | Resistor |  | ~
R4,R5,R12 | 4k7 | C23162 | Resistor_SMD:R_0603_1608Metric | 4331579 | Resistor |  | ~
R7 | 180 | C25270 | Resistor_SMD:R_0805_2012Metric | 339930 | Resistor |  | ~
R8 | 100 | C17408 | Resistor_SMD:R_0805_2012Metric | 2673800 | Resistor |  | ~
R9,R11 | 330 | C17630 | Resistor_SMD:R_0805_2012Metric | 842965 | Resistor |  | ~
R10 | 1k5 | C4310 | Diode_SMD:D_0805_2012Metric | 749892 | Resistor |  | ~
SW_1 | EN | C318884 | Button_Switch_SMD:SW_SPST_TL3342 | 163701 | Push button switch, generic, two pins |  | https://www.lcsc.com/datasheet/lcsc_datasheet_2304140030_XKB-Connection-TS-1187A-B-A-B_C318884.pdf
SW_2 | BOOT | C318884 | Button_Switch_SMD:SW_SPST_TL3342 | 163701 | Push button switch, generic, two pins |  | https://www.lcsc.com/datasheet/lcsc_datasheet_2304140030_XKB-Connection-TS-1187A-B-A-B_C318884.pdf
SW_3 | HOME | C318884 | Button_Switch_SMD:SW_SPST_TL3342 | 163701 | Push button switch, generic, two pins |  | https://www.lcsc.com/datasheet/lcsc_datasheet_2304140030_XKB-Connection-TS-1187A-B-A-B_C318884.pdf
SW_4 | UP | C318884 | Button_Switch_SMD:SW_SPST_TL3342 | 163701 | Push button switch, generic, two pins |  | https://www.lcsc.com/datasheet/lcsc_datasheet_2304140030_XKB-Connection-TS-1187A-B-A-B_C318884.pdf
SW_5 | DOWN | C318884 | Button_Switch_SMD:SW_SPST_TL3342 | 163701 | Push button switch, generic, two pins |  | https://www.lcsc.com/datasheet/lcsc_datasheet_2304140030_XKB-Connection-TS-1187A-B-A-B_C318884.pdf
SW_6 | CONFIRM | C318884 | Button_Switch_SMD:SW_SPST_TL3342 | 163701 | Push button switch, generic, two pins |  | https://www.lcsc.com/datasheet/lcsc_datasheet_2304140030_XKB-Connection-TS-1187A-B-A-B_C318884.pdf
SW_7 | BACK | C318884 | Button_Switch_SMD:SW_SPST_TL3342 | 163701 | Push button switch, generic, two pins |  | https://www.lcsc.com/datasheet/lcsc_datasheet_2304140030_XKB-Connection-TS-1187A-B-A-B_C318884.pdf
U1 | ESP32-S3-WROOM-1-N8R2 | C2913204 | PCM_Espressif:ESP32-S3-WROOM-1 | 1310 | 2.4 GHz WiFi (802.11 b/g/n) and Bluetooth Â® 5 (LE) module Built around ESP32S3 series of SoCs, Xtensa Â® dualcore 32bit LX7 microprocessor Flash up to 16 MB, PSRAM up to 8 MB 36 GPIOs, rich set of peripherals Onboard PCB antenna |  | https://www.espressif.com/sites/default/files/documentation/esp32-s3-wroom-1_wroom-1u_datasheet_en.pdf
U2 | SGM2212-3.3XKC3G/TR | C3294699 | Package_TO_SOT_SMD:SOT-223-3_TabPin2 |  | 1.5V, 1.5A, Low Noise, Fast Transient Response LDO Regulator, SOT-223 |  | https://www.analog.com/media/en/technical-documentation/data-sheets/1963aff.pdf
U3,U4 | EL357N-G | C29981 | Package_SO:SO-4_4.4x3.6mm_P2.54mm | 267309 | DC Optocoupler, Vce 35V, CTR 50%, SO-4 |  | https://www.buerklin.com/medias/sys_master/download/download/h91/ha0/8892020588574.pdf
U5 | ILI9341_no_touch |  | Project:ILI9341_no_touch_no_mount |  | ILI9341 controller, SPI TFT LCD Display, 9-pin breakout PCB, 4-pin SD card interface, 5V/3.3V |  | http://pan.baidu.com/s/11Y990

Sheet: Opentherm parameters
Resistor values
R1 | 200 | 220 | 220 | 200 | 180
R2 | 150 | 150 | 100 | 100 | 100
Vmin | 1.05 | 1.05 | 0.698 | 0.698 | 0.698
Vmax | 1.53 | 1.52 | 1.39 | 1.43 | 1.47
Capacitor values
C1 | 2n2 | 0
C2 | 2n2 | 0
C3 | 10n | 0

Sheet: ESP32 pins
PIN | GPIO | Assignment | Remark
1 |  | GND
2 |  | 3V3
3 |  | EN
4 | 4 | not connected
5 | 5 | Onewire thermometers
6 | 6 | LED
7 | 7 | not connected
8 | 15 | Display RST
9 | 16 | Display DC
10 | 17 | not connected
11 | 18 | not connected
12 | 8 | cntr_to_boil
13 | 19 | USB D-
14 | 20 | USB D+
15 | 3 | not connected | JTAG signal source strapping
16 | 46 | not connected | Chip boot strapping pin ROM message printing strapping pin Default: weak pull-down
17 | 9 | Display backlight
18 | 10 | Display CS
19 | 11 | Display MOSI
20 | 12 | Display SCK
21 | 13 | Display MISO
22 | 14 | boil_to_cntr
23 | 21 | btn_back
24 | 47 | not connected | For S3R16V, voltage is 1.8V
25 | 48 | not connected | For S3R16V, voltage is 1.8V
26 | 45 | not connected | VDD_SPI voltage strapping pin Default: weak pull-down Only relevant if EFUSE_VDD_SPI_FORCE is 1
27 | 0 | BOOT | Chip boot strapping pin If pulled-down during boot, joint download boot mode is activated
28 | 35 | btn_confirm | Default function decided by eFuse
29 | 36 | SD_CS | Default function decided by eFuse
30 | 37 | SD_MOSI | Default function decided by eFuse
31 | 38 | SD_MISO
32 | 39 | SD_SCK
33 | 40 | btn_down
34 | 41 | btn_up
35 | 42 | btn_home
36 | 44 | TOF_SDA
37 | 43 | TOF_SCL
38 | 2 | TOF_GPIO01
39 | 1 | TOF_XSHUT
40 |  | GND

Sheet: SPI
SPI bus display
SPI0 used by ESP32-S3’s GDMA controller and cache to access in-package or off-package flash/PSRAM
SPI1 used by the CPU to access in-package or off-package flash/PSRAM
SPI2 is a general purpose SPI controller with access to a DMA channel allocated by the GDMA controller
SPI3 is a general purpose SPI controller with access to a DMA channel allocated by the GDMA controller
SPI2: Display
SPI2
– Via IO MUX:
* Interface 4c is multiplexed with GPIO9 ~ GPIO14, RTC_GPIO9 ~ RTC_GPIO14, Touch Sensor interface, SAR ADC interface, and SPI interfaces 4d and 4g via IO MUX. It is the SPI2 main interface for fast SPI connection.
* (not recommended) Interface 4f is multiplexed with GPIO33 ~ GPIO38, SPI interfaces 4e and 4b via IO MUX. It is the alternative SPI2 interface if the main SPI2 is not available. Its performance is comparable to SPI2 via GPIO matrix, so use the GPIO matrix instead.
* (not recommended) Interface 4g is multiplexed with GPIO10 ~ GPIO14, RTC_GPIO10 ~ RTC_GPIO14, Touch Sensor interface, SAR ADC interface, and SPI interfaces 4c and 4d via IO MUX. It is the alternative SPI2 interface signal lines for 8-line SPI connection.
– Via GPIO Matrix: The pins used can be chosen from any GPIOs via the GPIO Matrix.
Pin | GPIO | Pin function | Signal | Schematic
17 | 9 | FSPIHD | Hold | Disp_LED
18 | 10 | FSPICSO | Chip select | Disp_CS
19 | 11 | FSPID | Data in | Disp_MOSI
20 | 12 | FSPICLK | Clock | Disp_SCK
21 | 13 | FSPIQ | Data out | Disp_MISO
22 | 14 | FSPIWP | Write protect | boil_to_ctrl
SPI3: SD Card
SPI3: The pins used can be chosen from any GPIOs via the GPIO Matrix.

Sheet: Sheet1 (2)
 |  | X | Y
01 | VCC | 0 | 0
02 | GND | 0 | 2.54
03 | ~CS | 0 | 5.08
04 | RST | 0 | 7.62
05 | D/~C | 0 | 10.16
06 | MOSI | 0 | 12.7
07 | SCK | 0 | 15.24
08 | LED | 0 | 17.78
09 | MISO | 0 | 20.32
10 | SD_CS | 63.52 | 5.08 | 213.52 | 70.08
11 | SD_MOSI | 63.52 | 7.62
12 | SD_MISO | 63.52 | 10.16
13 | SD_SCK | 63.52 | 12.7
14 | FLASH_CD | 63.52 | 15.24
 | Screen_min | 6 | -8
 | Screen_max | 58 | 28
 | Screen_avg | 32 | 10
 | Screen middle | 150 | 75
 | Pin0 | 118 | 65
 | SD_CS | 181.52 | 70.08 |  |  | 118

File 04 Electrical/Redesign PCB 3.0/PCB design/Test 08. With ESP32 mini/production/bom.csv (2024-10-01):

Designator | Footprint | Quantity | Value | LCSC Part #
C1, C3 | 0603 | 2 | 10n
C2, C4 | 0603 | 2 | 2n2
D1, D2, D3, D4 | D_SOD-323 | 4 | 1N4148WS
D5 | D_SOD-323 | 1 | BZT52C4V7S
D6 | D_SOD-123 | 1 | BZT52C15V
D7 | D_SOD-123 | 1 | BZT52C4V3
Q1 | SOT-23 | 1 | MMBT2907A
R1 | 0805 | 1 | 200
R2 | 0805 | 1 | 150
R3, R6 | 0805 | 2 | 330
R4 | 0805 | 1 | 4k7
R5 | 0805 | 1 | 1k5
U5, U6 | OPTO_EL357N-G | 2 | EL357N-G

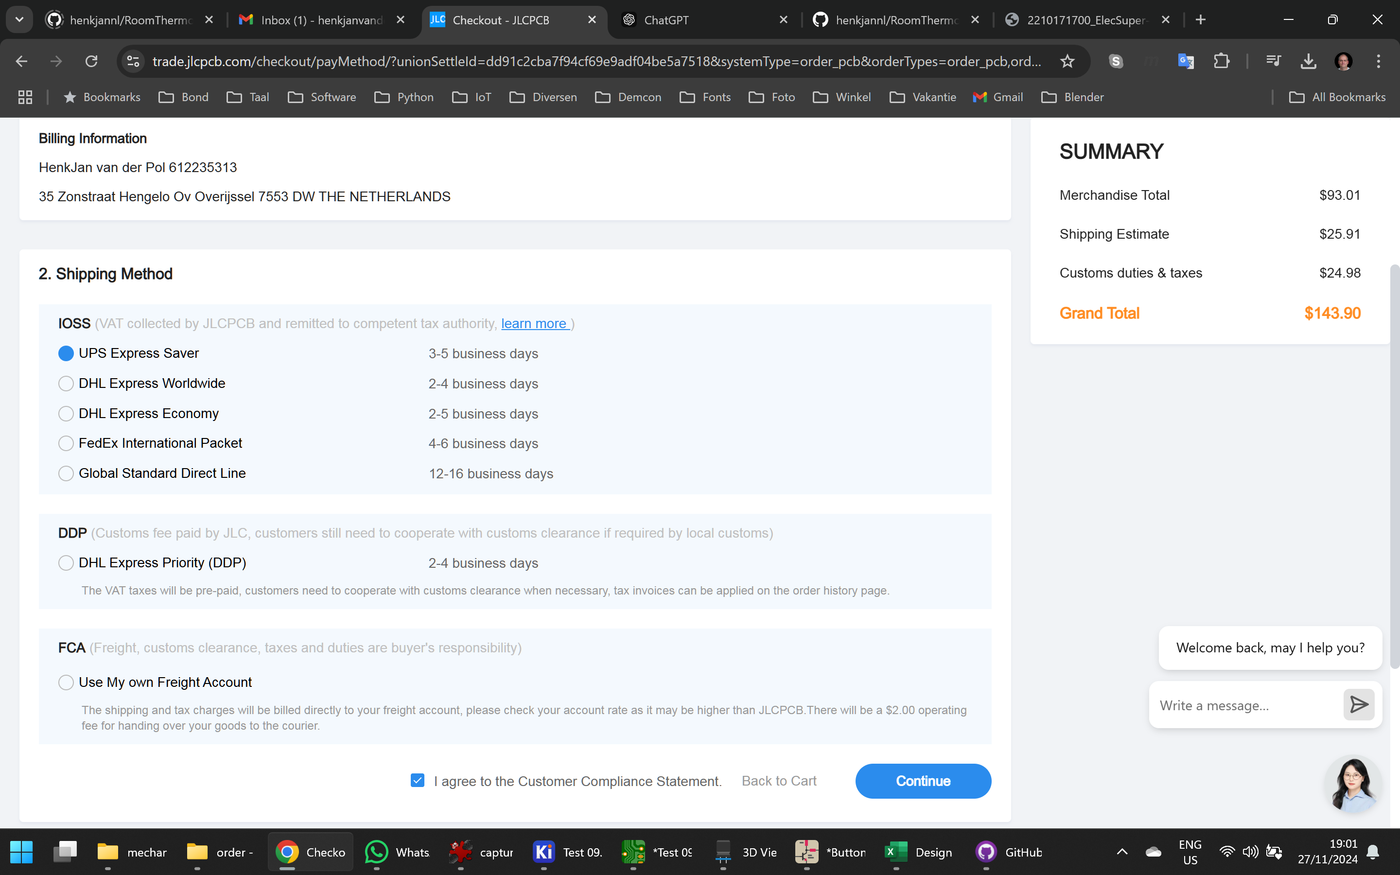
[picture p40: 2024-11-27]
04 Electrical/Redesign PCB 3.0/PCB design/V3.1 Not yet ordered/order/capture_013.png

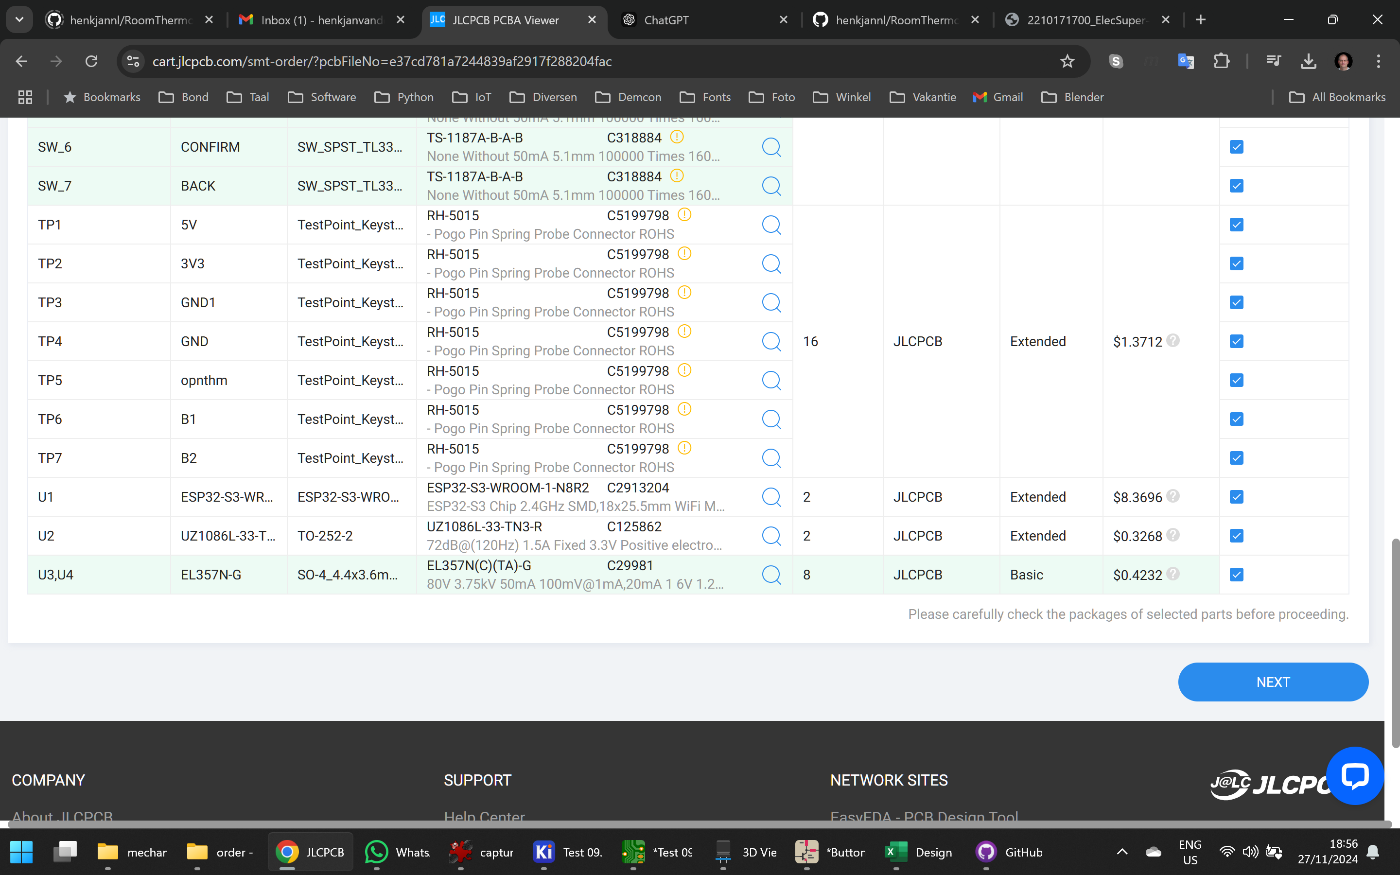
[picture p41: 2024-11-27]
04 Electrical/Redesign PCB 3.0/PCB design/V3.1 Not yet ordered/order/capture_008.png

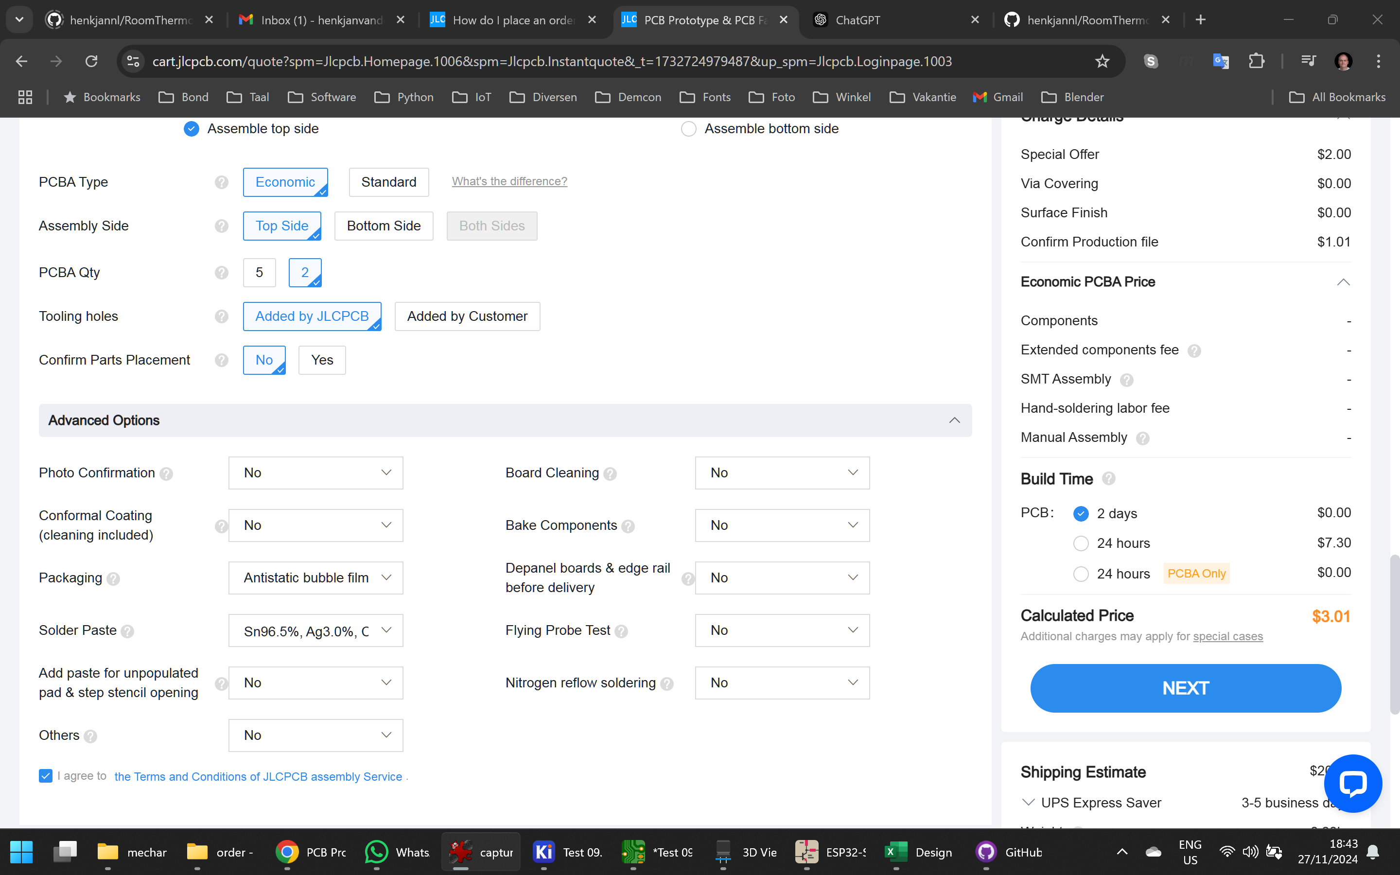
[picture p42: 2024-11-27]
04 Electrical/Redesign PCB 3.0/PCB design/V3.1 Not yet ordered/order/capture_004.png

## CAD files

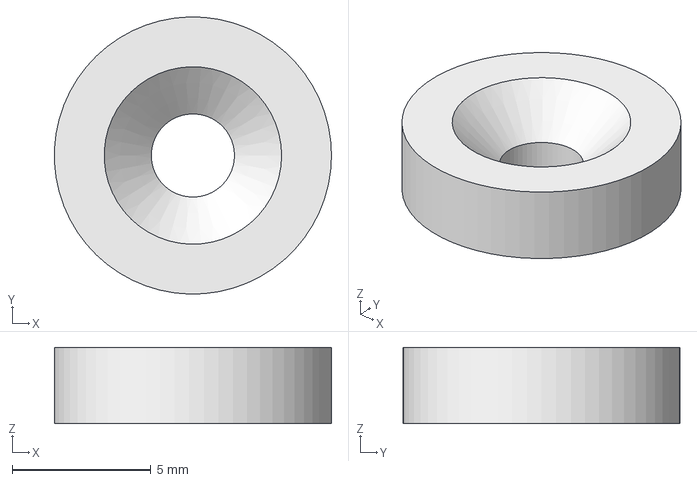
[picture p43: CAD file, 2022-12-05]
03 Mechanical/Components/RingMagnet10x2.75.FCStd
9.99 x 10.00 x 2.75 mm

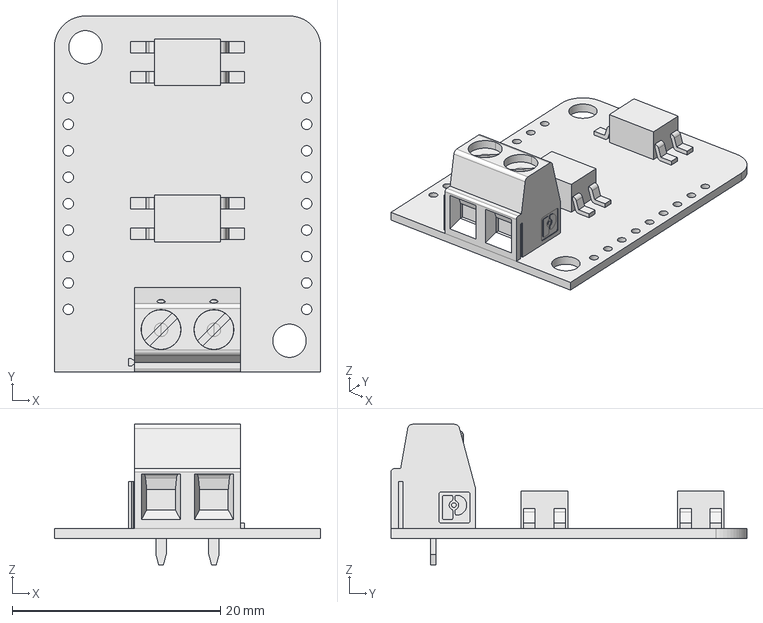
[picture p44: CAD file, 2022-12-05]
03 Mechanical/Housing for TTGO and Opentherm/OpenThermAdaptor.FCStd
25.6 x 34.2 x 13.5 mm

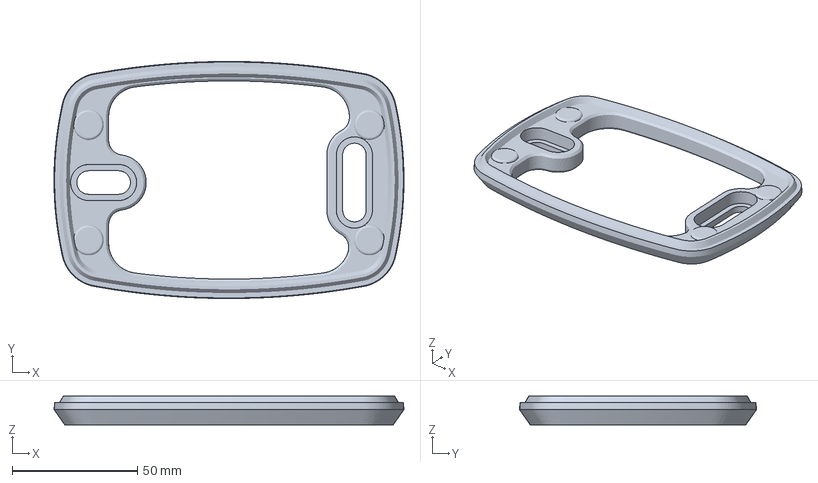
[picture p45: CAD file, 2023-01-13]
03 Mechanical/Wall plate.3mf
139.6 x 94.6 x 11.5 mm

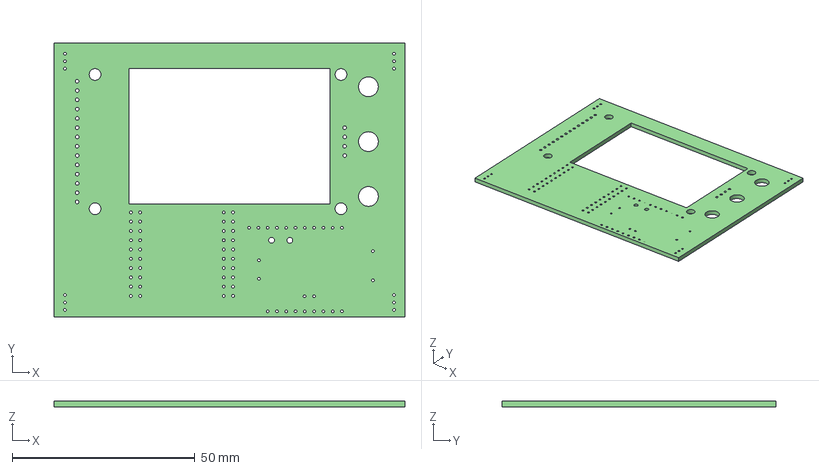
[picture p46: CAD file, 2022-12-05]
04 Electrical/Interconnect PCB V2.0 - opentherm as individual components/InterconnectPCB.step
96.0 x 75.0 x 1.60 mm

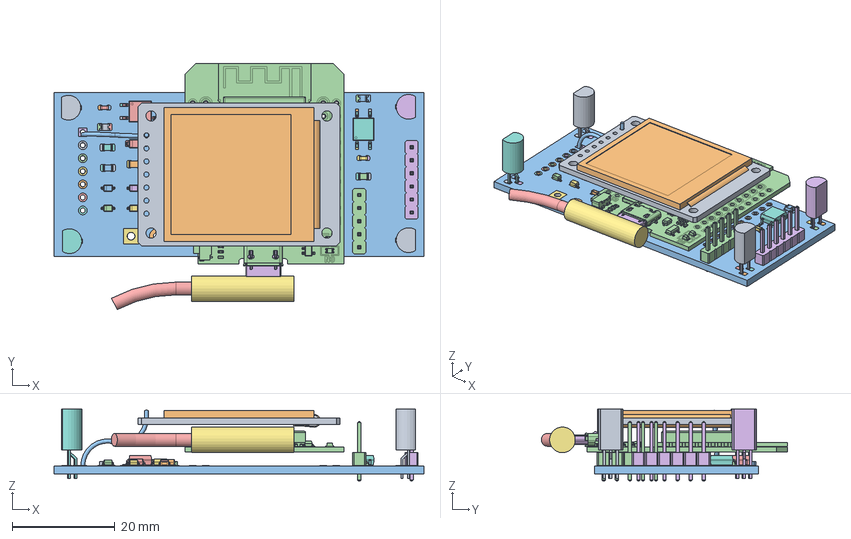
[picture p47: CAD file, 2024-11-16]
04 Electrical/Redesign PCB 3.0/Interface board example project/Background info/Mechanical design.FCStd
72.0 x 47.9 x 14.0 mm
SCREEN
GLASS
Skeleton
D_SOD_323
EL357N-G
TO-92L_Narrow
D_SOD_123
EL357N-G002
TO-92L_Narrow001
C_0603_1608Metric
D_SOD_324
R_0805_2012Metric
C_0603_1608Metric002
D_SOD_325
C_0603_1608Metric004
R_0805_2012Metric002
TO-92L_Narrow002
SOT_23
D_0805
C_0603_1608Metric006
D_SOD_326
PinHeader_1x06_P254mm_Vertical
D_SOD_327
TO-92L_Narrow003
D_0806
R_0805_2012Metric004
R_0805_2012Metric006
PinHeader_1x05_P254mm_Vertical
D_SOD_328
Test 08. With ESP32 mini_pad_1
Test 08. With ESP32 mini_pad_2
Test 08. With ESP32 mini_pad_3
Test 08. With ESP32 mini_pad_4
Test 08. With ESP32 mini_pad_5
Test 08. With ESP32 mini_pad_6
Test 08. With ESP32 mini_pad_7
Test 08. With ESP32 mini_pad_8
Test 08. With ESP32 mini_pad_9
Test 08. With ESP32 mini_pad_10
Test 08. With ESP32 mini_pad_11
Test 08. With ESP32 mini_pad_12
Test 08. With ESP32 mini_pad_13
Test 08. With ESP32 mini_pad_14
Test 08. With ESP32 mini_pad_15
Test 08. With ESP32 mini_pad_16
Test 08. With ESP32 mini_pad_17
Test 08. With ESP32 mini_pad_18
Test 08. With ESP32 mini_pad_19
Test 08. With ESP32 mini_pad_20
Test 08. With ESP32 mini_pad_21
Test 08. With ESP32 mini_pad_22
Test 08. With ESP32 mini_pad_23
Test 08. With ESP32 mini_pad_24
Test 08. With ESP32 mini_pad_25
Test 08. With ESP32 mini_pad_26
Test 08. With ESP32 mini_pad_27
Test 08. With ESP32 mini_pad_28
Test 08. With ESP32 mini_pad_29
Test 08. With ESP32 mini_pad_30
Test 08. With ESP32 mini_pad_31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

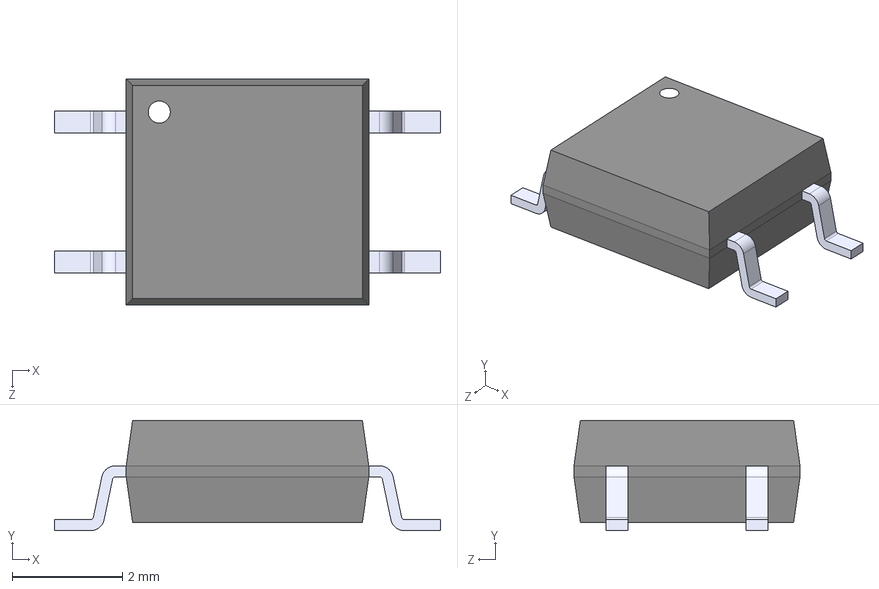
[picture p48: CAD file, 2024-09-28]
04 Electrical/Redesign PCB 3.0/Interface board example project/KiCad Library/EL357N-G/EL357N-G.step
7.00 x 2.00 x 4.10 mm

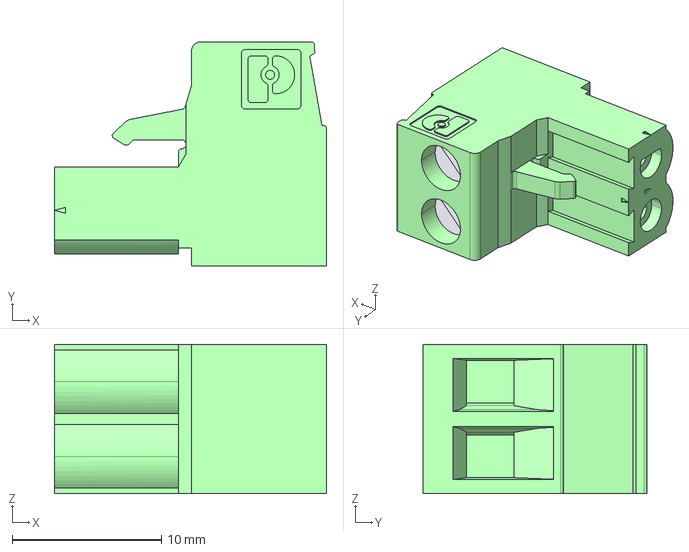
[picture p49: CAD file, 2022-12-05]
07 Readonly/Phoenix connector/Phoenix MSTB 2,5 2-ST cable part/pxc_1754449_06_MSTB-2-5-2-ST_3D.stp
18.2 x 15.0 x 10.0 mm

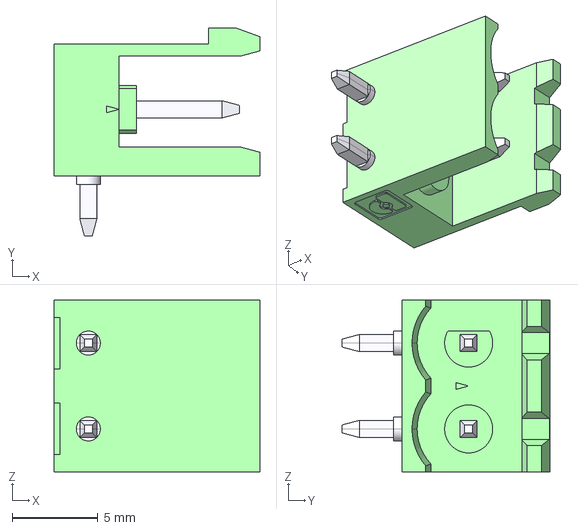
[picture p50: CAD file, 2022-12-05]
07 Readonly/Phoenix connector/Phoenix MSTB-2,5-2-G PCB part/pxc_1754436_04_MSTB-2-5-2-G_3D.stp
12.0 x 12.1 x 10.0 mm

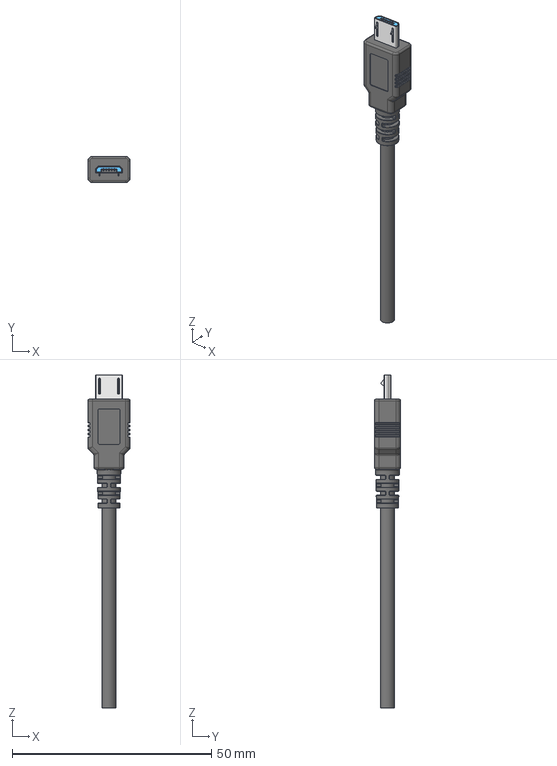
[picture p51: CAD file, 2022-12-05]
03 Mechanical/Components/Micro USB Plug.step
10.6 x 6.60 x 83.5 mm
Cable
Micro_USB_Plug_Connector

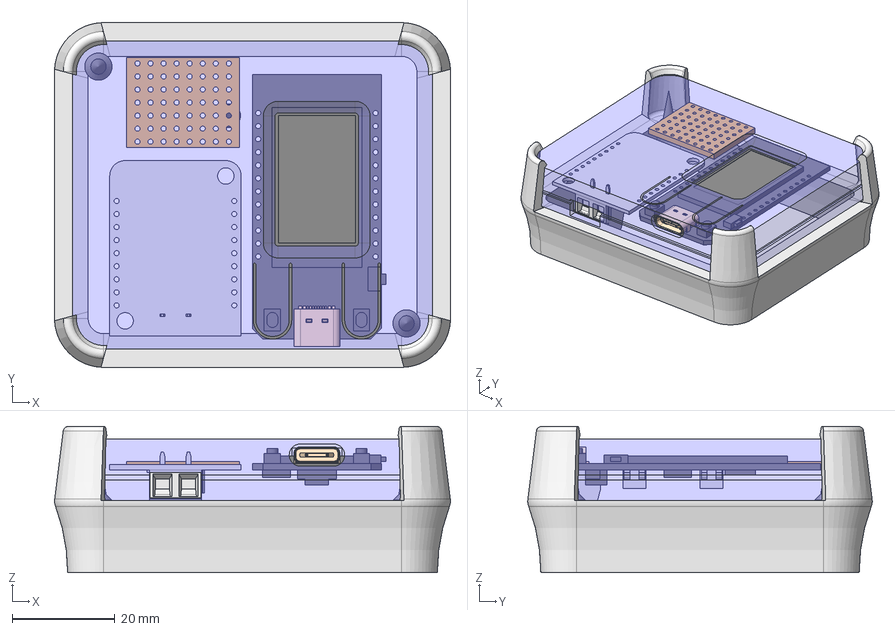
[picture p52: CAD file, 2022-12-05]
03 Mechanical/Housing for TTGO and Opentherm/Thermostat.FCStd
77.1 x 67.1 x 28.4 mm
USB Type C Port (SMD Type)
OpenThermAdaptor
DallasSensorHousing
TH Top housing
SelftappingScrew3.0x16_01
SelftappingScrew3.0x16_002
BH Bottom housing
HD Holder

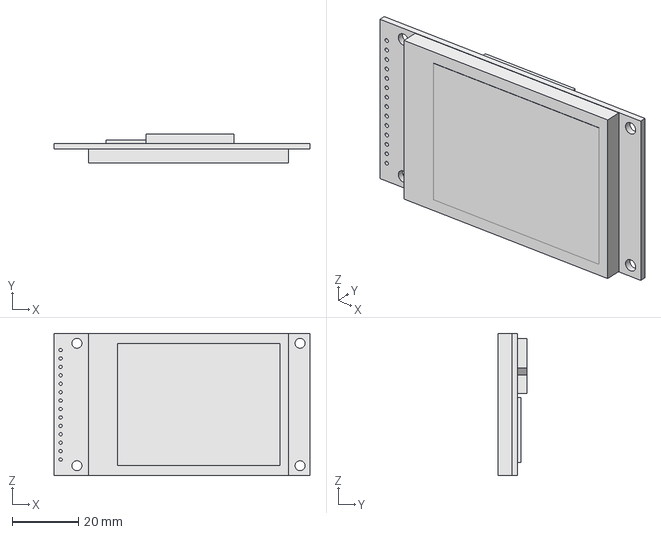
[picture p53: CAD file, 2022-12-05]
03 Mechanical/Components/Display 2.4'' 320x240.FCStd
77.2 x 8.80 x 42.9 mm

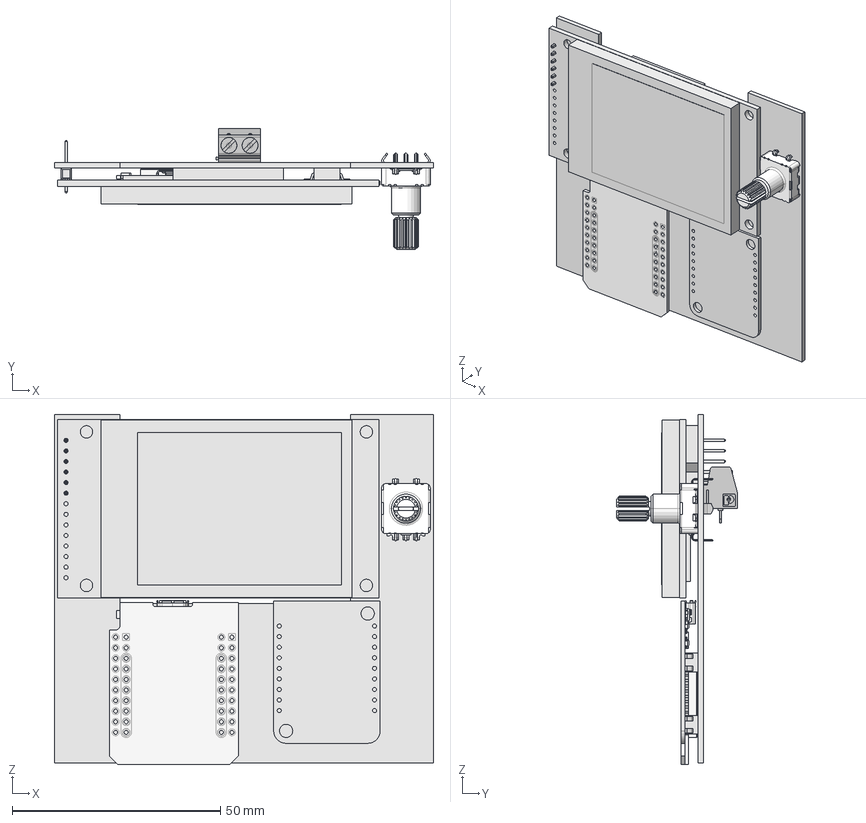
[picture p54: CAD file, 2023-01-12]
03 Mechanical/RoomThermostat with PCB and rotary encoder (concept).FCStd
91.1 x 29.0 x 84.1 mm
Display
EC11E-05SW
MH-ET_LIVE_MiniKit
OpenThermAdaptor
Phonix2Pins001

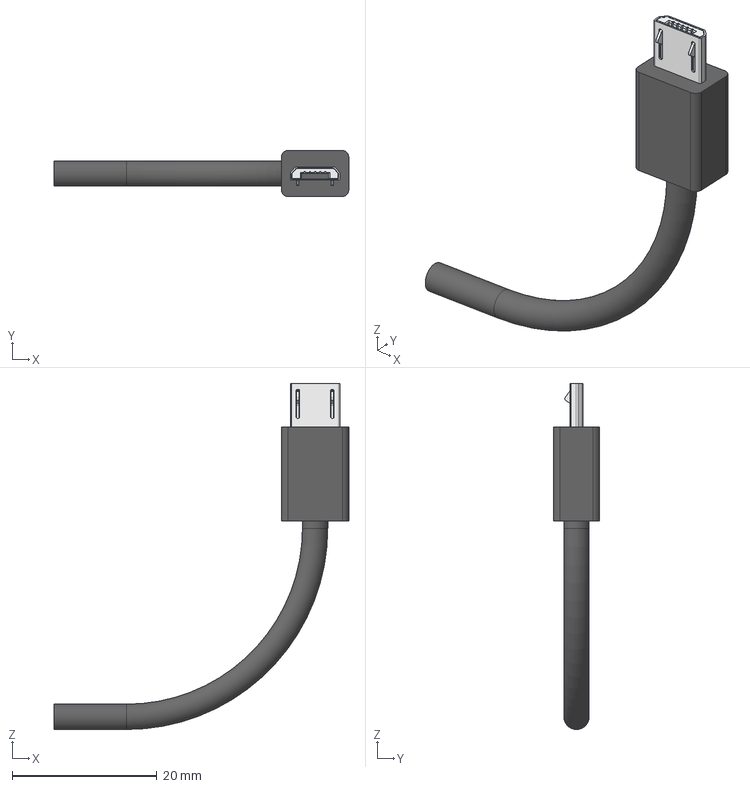
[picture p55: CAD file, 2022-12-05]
03 Mechanical/Components/Micro USB connector.FCStd
40.6 x 6.35 x 47.8 mm
Cable
Micro_USB_Plug_Connector
Housing

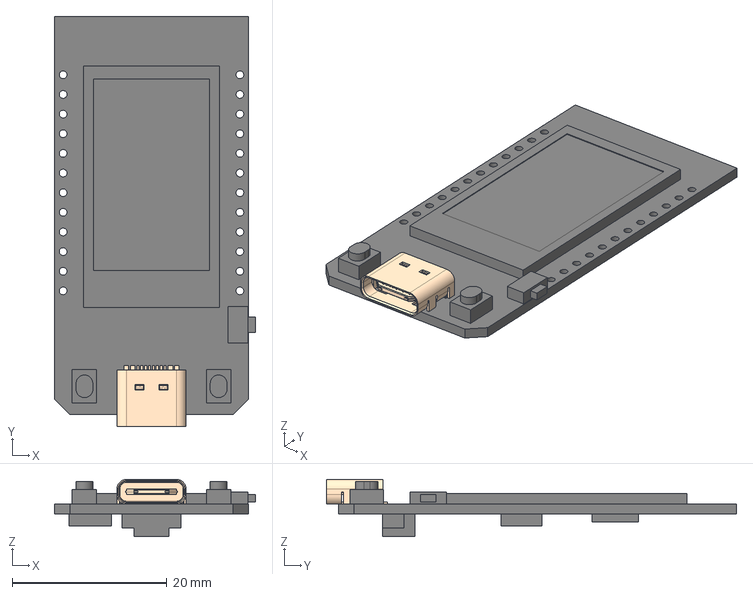
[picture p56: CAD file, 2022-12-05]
03 Mechanical/Housing for TTGO and Opentherm/TTGO-Tdisplay.FCStd
26.0 x 53.0 x 7.40 mm
USB Type C Port (SMD Type)

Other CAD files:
03 Mechanical/Components/Dallas DS18B20.step
03 Mechanical/Housing for TTGO and Opentherm/DallasSensor.FCStd
03 Mechanical/Screw interface.3mf
03 Mechanical/Housing for TTGO and Opentherm/SelftappingScrew3.0x10.FCStd
03 Mechanical/Screw interface.stl
03 Mechanical/ScrewInterface.stl

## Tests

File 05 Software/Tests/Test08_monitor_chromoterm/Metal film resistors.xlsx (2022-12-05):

Metal film resistors
30 values
20 of each value
1% accuracy
Resistance
10
22
47
100
150
200
220
270
330
470
510
680
1000
2000
2200
3300
4700
5100
6800
10000
20000
47000
51000
68000
100000
220000
300000
470000
680000
1000000

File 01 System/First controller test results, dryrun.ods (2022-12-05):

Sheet: Sheet1
22:19:32.609 | -> | setpoint | 25.5 | C | measured | 22.025 | C | Error | 3.475 | C | P | 34.75 | I | 1.236 | D | 0 | boiler | 35.986 | C
22:19:32.609 | -> | setpoint | 25.5 | C | measured | 22.025 | C | Error | 3.475 | C | P | 34.75 | I | 1.236 | D | 0 | boiler | 35.986 | C
22:19:38.736 | -> | setpoint | 25.5 | C | measured | 21.962 | C | Error | 3.538 | C | P | 35.375 | I | 1.661 | D | 0 | boiler | 37.036 | C
22:19:44.865 | -> | setpoint | 25.5 | C | measured | 21.962 | C | Error | 3.538 | C | P | 35.375 | I | 2.085 | D | 0 | boiler | 37.46 | C
22:19:51.038 | -> | setpoint | 25.5 | C | measured | 22.025 | C | Error | 3.475 | C | P | 34.75 | I | 2.502 | D | 0 | boiler | 37.252 | C
22:19:57.148 | -> | setpoint | 25.5 | C | measured | 22.025 | C | Error | 3.475 | C | P | 34.75 | I | 2.919 | D | 0 | boiler | 37.669 | C
22:20:03.291 | -> | setpoint | 25.5 | C | measured | 22.025 | C | Error | 3.475 | C | P | 34.75 | I | 3.336 | D | 0 | boiler | 38.086 | C
22:20:09.432 | -> | setpoint | 25.5 | C | measured | 22.087 | C | Error | 3.413 | C | P | 34.125 | I | 3.746 | D | 0 | boiler | 37.871 | C
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

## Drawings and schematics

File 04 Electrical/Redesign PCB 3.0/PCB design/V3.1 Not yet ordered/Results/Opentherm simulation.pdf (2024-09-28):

## Current through OpenTherm bus

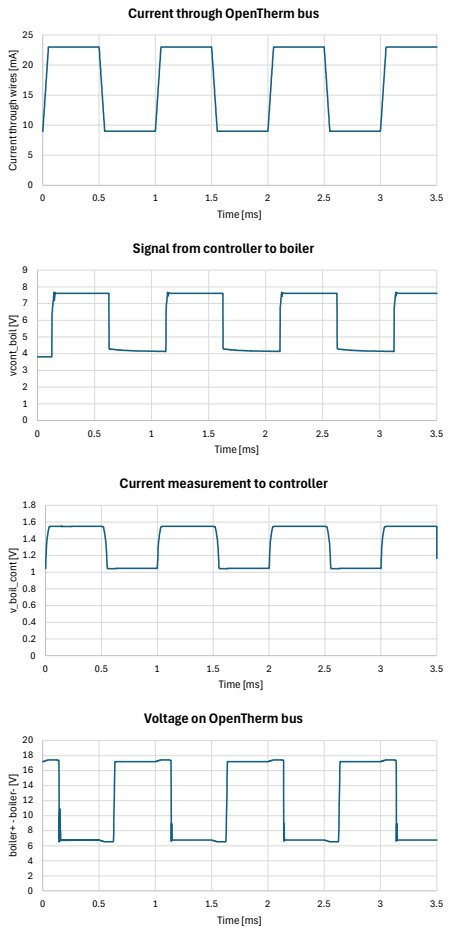
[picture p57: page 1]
3.5 Current through wires [mA]; Time [ms]; 3.5 vcont_boil [V]; 3.5 v_boil_cont [V]; 3.5 boiler+ ⁻ boiler- [V]

Signal from controller to boiler

Current measurement to controller

Voltage on OpenTherm bus

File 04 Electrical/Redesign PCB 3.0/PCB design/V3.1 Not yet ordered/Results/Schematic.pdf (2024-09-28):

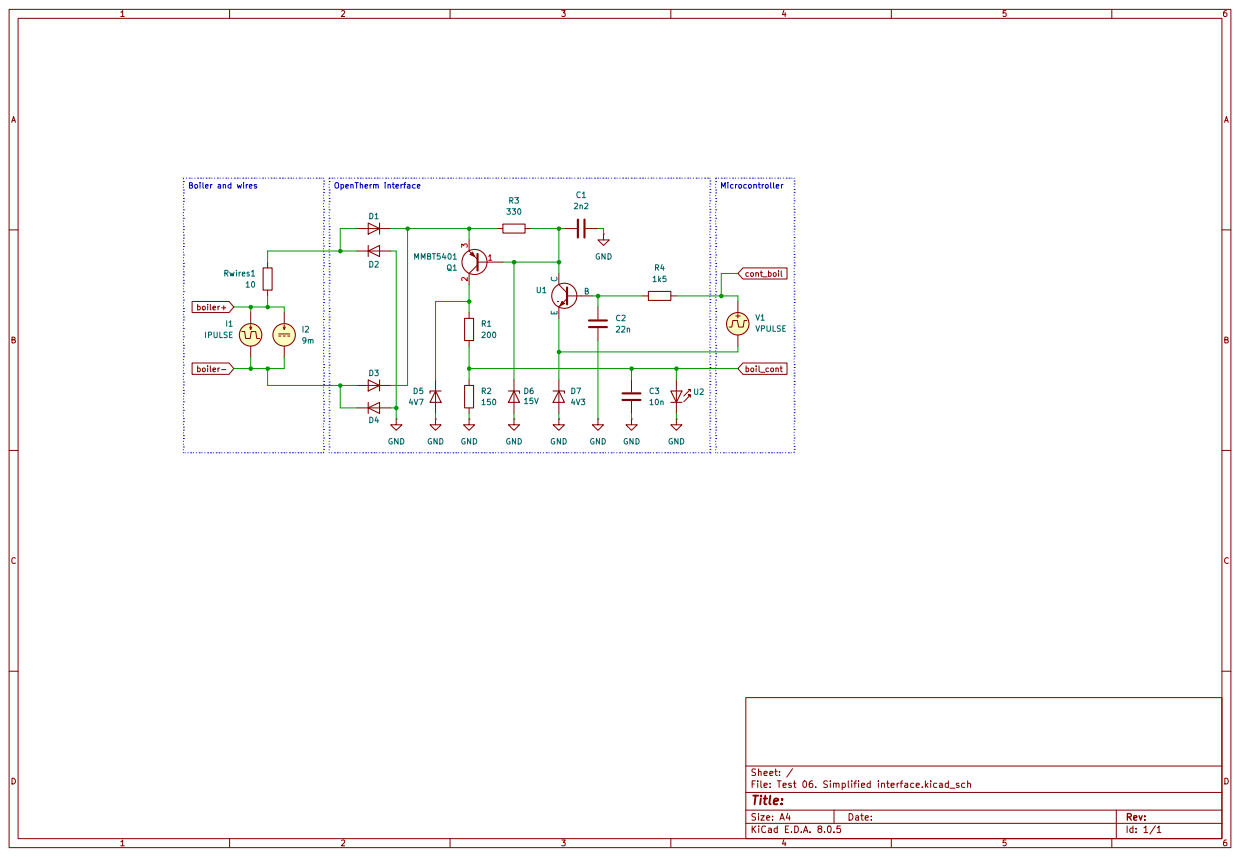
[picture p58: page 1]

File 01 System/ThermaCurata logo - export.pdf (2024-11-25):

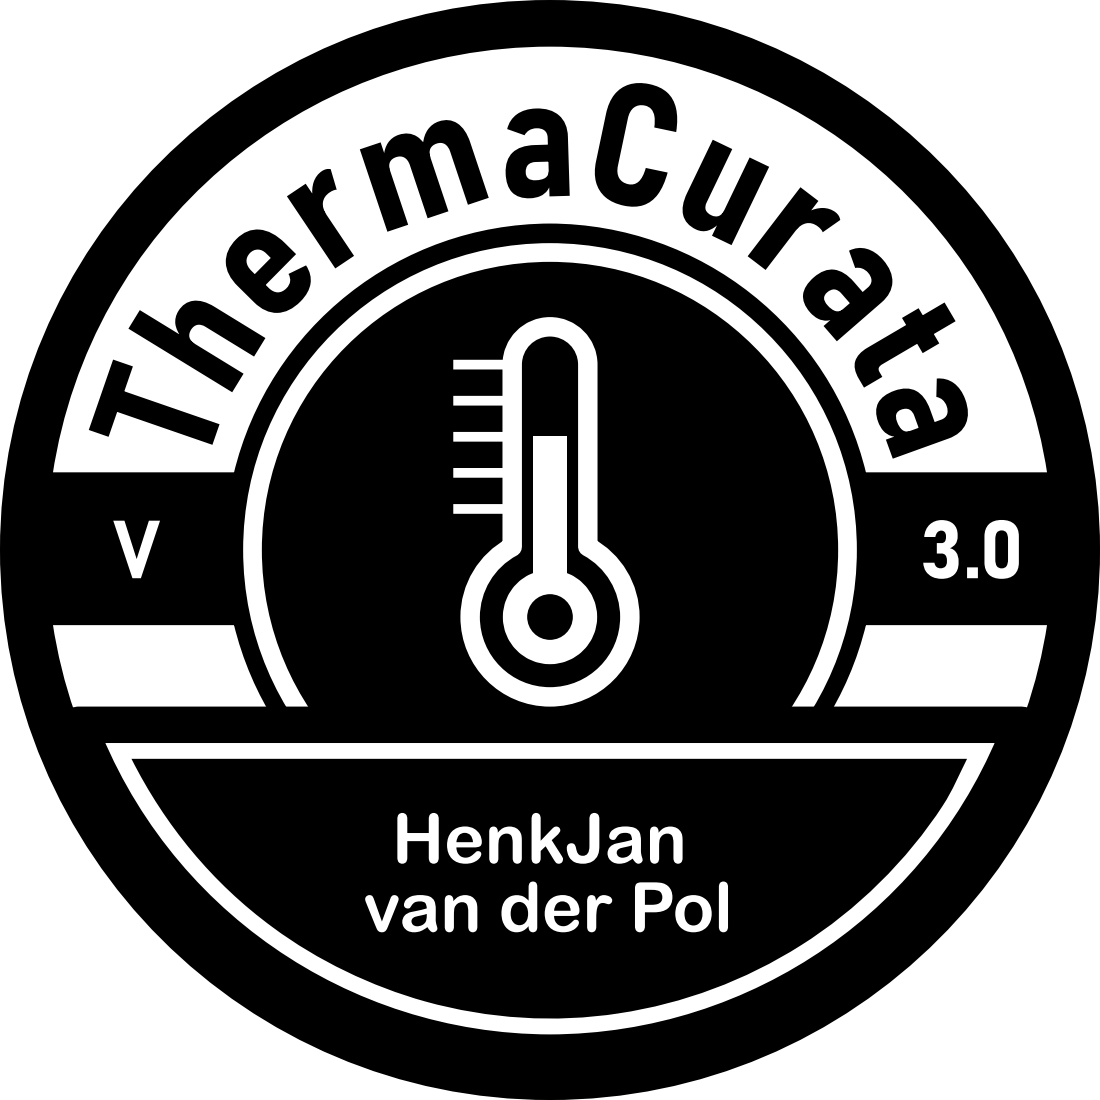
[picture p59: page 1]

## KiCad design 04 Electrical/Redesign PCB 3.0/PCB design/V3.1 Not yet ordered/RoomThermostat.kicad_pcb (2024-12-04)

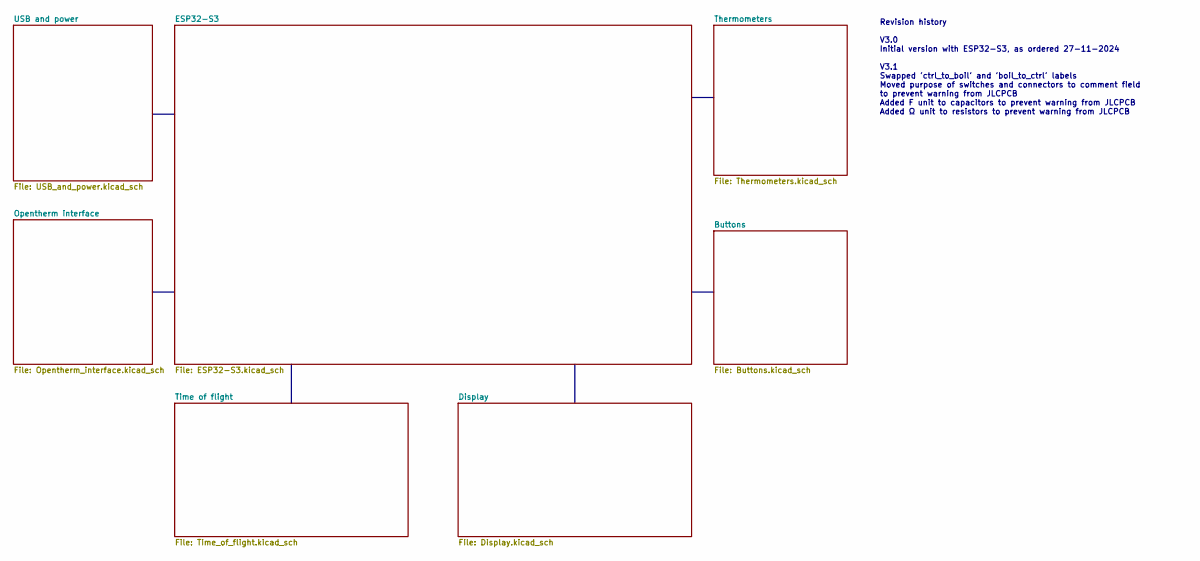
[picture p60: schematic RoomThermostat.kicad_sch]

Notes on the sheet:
Revision history V3.0 Initial version with ESP32-S3, as ordered 27-11-2024 V3.1 Swapped 'ctrl_to_boil' and 'boil_to_ctrl' labels Moved purpose of switches and connectors to comment field to prevent warning from JLCPCB Added F unit to capacitors to prevent warning from JLCPCB Added Ω unit to resisto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

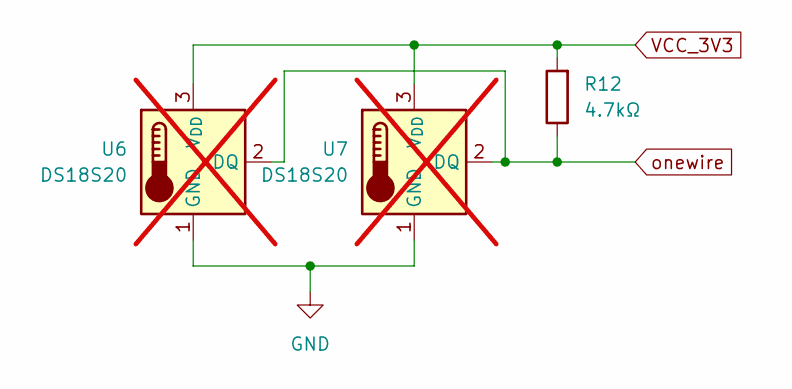
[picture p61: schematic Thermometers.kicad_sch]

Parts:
R12: 4.7kΩ; R_0603_1608Metric; LCSC Part # C23162
U6, U7: DS18S20; TO-92L_HandSolder; not fitted

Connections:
GND: U6.1 (GND), U7.1 (GND); also elsewhere on the board
VCC_3V3: R12.2, U6.3 (V_{DD}), U7.3 (V_{DD}); also elsewhere on the board
onewire: R12.1, U6.2 (DQ), U7.2 (DQ); also elsewhere on the board

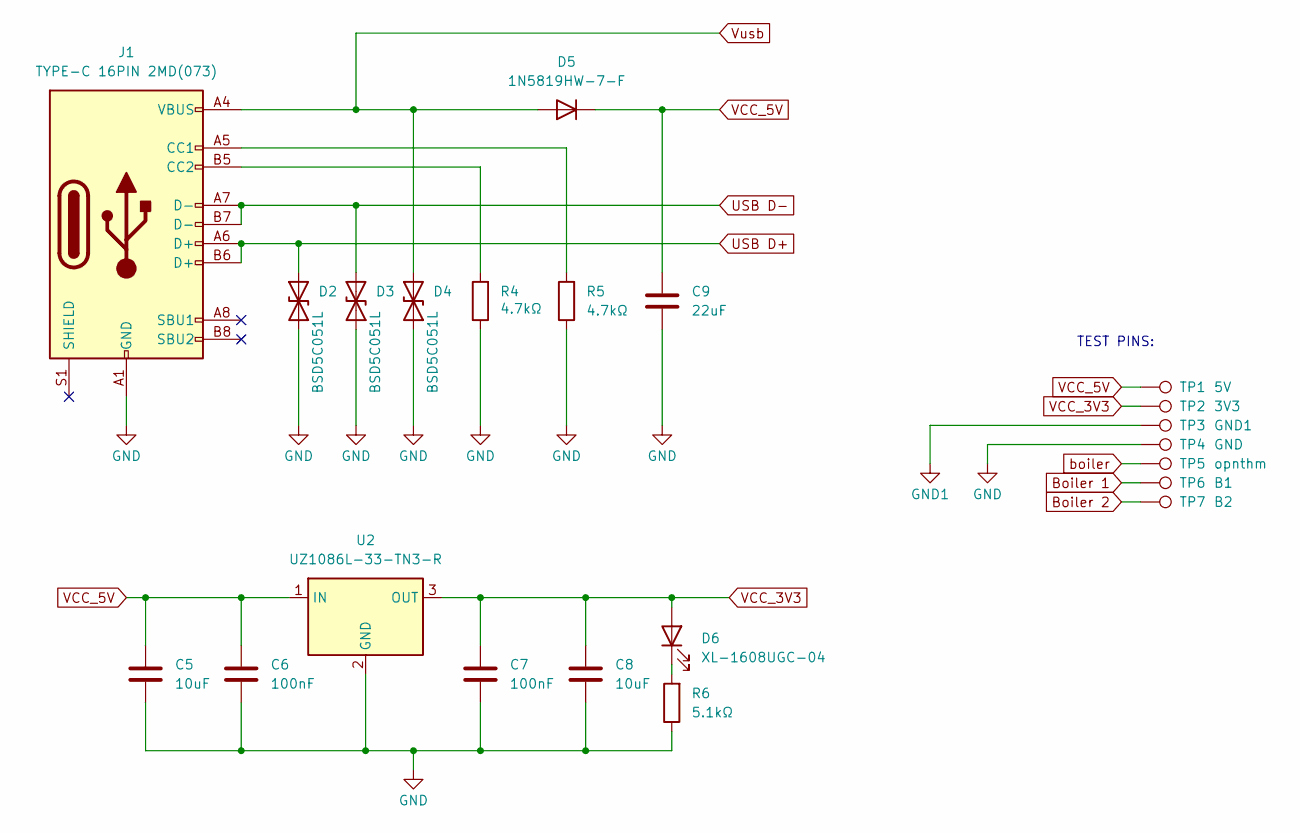
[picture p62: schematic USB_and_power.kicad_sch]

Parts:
C5, C8: 10uF; C_0402_1005Metric; LCSC Part # C15525
C6, C7: 100nF; C_0603_1608Metric; LCSC Part # C14663
C9: 22uF; C_0805_2012Metric; LCSC Part # C45783
D2, D3, D4: BSD5C051L; D_SOD-523; LCSC Part # C151983
D5: 1N5819HW-7-F; D_SOD-123; LCSC Part # C82544
D6: XL-1608UGC-04; LED_0603_1608Metric; LCSC Part # C965804
J1: TYPE-C 16PIN 2MD(073); USB_C_Receptacle_GCT_USB4105-xx-A_16P_TopMnt_Horizontal; LCSC Part # C2765186
R4, R5: 4.7kΩ; R_0603_1608Metric; LCSC Part # C23162
R6: 5.1kΩ; R_0603_1608Metric; LCSC Part # C23186
TP1: 5V; TestPoint_Keystone_5015_Micro-Minature; LCSC Part # C5199798
TP2: 3V3; TestPoint_Keystone_5015_Micro-Minature; LCSC Part # C5199798
TP3: GND1; TestPoint_Keystone_5015_Micro-Minature; LCSC Part # C5199798
TP4: GND; TestPoint_Keystone_5015_Micro-Minature; LCSC Part # C5199798
TP5: opnthm; TestPoint_Keystone_5015_Micro-Minature; LCSC Part # C5199798
TP6: B1; TestPoint_Keystone_5015_Micro-Minature; LCSC Part # C5199798
TP7: B2; TestPoint_Keystone_5015_Micro-Minature; LCSC Part # C5199798
U2: UZ1086L-33-TN3-R; TO-252-2; LCSC Part # C125862

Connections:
Boiler 1: TP6.1; also elsewhere on the board
Boiler 2: TP7.1; also elsewhere on the board
GND: C5.2, C6.2, C7.2, C8.2, C9.2, D2.1 (A1), D3.1 (A1), D4.1 (A1), J1.A1 (GND), J1.A12 (GND), J1.B1 (GND), J1.B12 (GND), R4.1, R5.1, R6.1, TP4.1, U2.2 (GND); also elsewhere on the board
GND1: TP3.1; also elsewhere on the board
unnamed: D6.1 (K), R6.2
unnamed: J1.A5 (CC1), R5.2
unnamed: J1.B5 (CC2), R4.2
USB D+: D2.2 (A2), J1.A6 (D+), J1.B6 (D+); also elsewhere on the board
USB D-: D3.2 (A2), J1.A7 (D-), J1.B7 (D-); also elsewhere on the board
VCC_3V3: C7.1, C8.1, D6.2 (A), TP2.1, U2.3 (OUT); also elsewhere on the board
VCC_5V: C5.1, C6.1, C9.1, D5.1 (K), TP1.1, U2.1 (IN)
Vusb: D4.2 (A2), D5.2 (A), J1.A4 (VBUS), J1.A9 (VBUS), J1.B4 (VBUS), J1.B9 (VBUS)
boiler: TP5.1; also elsewhere on the board

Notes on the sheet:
TEST PINS:

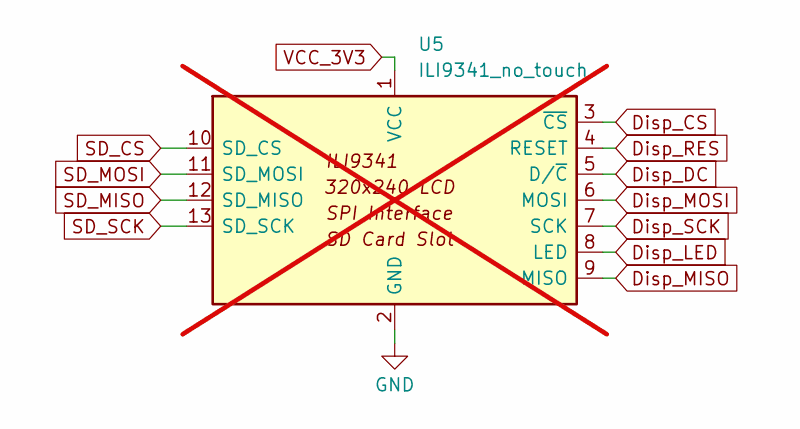
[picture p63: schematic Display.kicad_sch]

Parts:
U5: ILI9341_no_touch; ILI9341_no_touch_no_mount; not fitted

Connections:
Disp_CS: U5.3 (~CS); also elsewhere on the board
Disp_DC: U5.5 (D/~C); also elsewhere on the board
Disp_LED: U5.8 (LED); also elsewhere on the board
Disp_MISO: U5.9 (MISO); also elsewhere on the board
Disp_MOSI: U5.6 (MOSI); also elsewhere on the board
Disp_RES: U5.4 (RESET); also elsewhere on the board
Disp_SCK: U5.7 (SCK); also elsewhere on the board
GND: U5.2 (GND); also elsewhere on the board
SD_CS: U5.10 (SD_CS); also elsewhere on the board
SD_MISO: U5.12 (SD_MISO); also elsewhere on the board
SD_MOSI: U5.11 (SD_MOSI); also elsewhere on the board
SD_SCK: U5.13 (SD_SCK); also elsewhere on the board
VCC_3V3: U5.1 (VCC); also elsewhere on the board

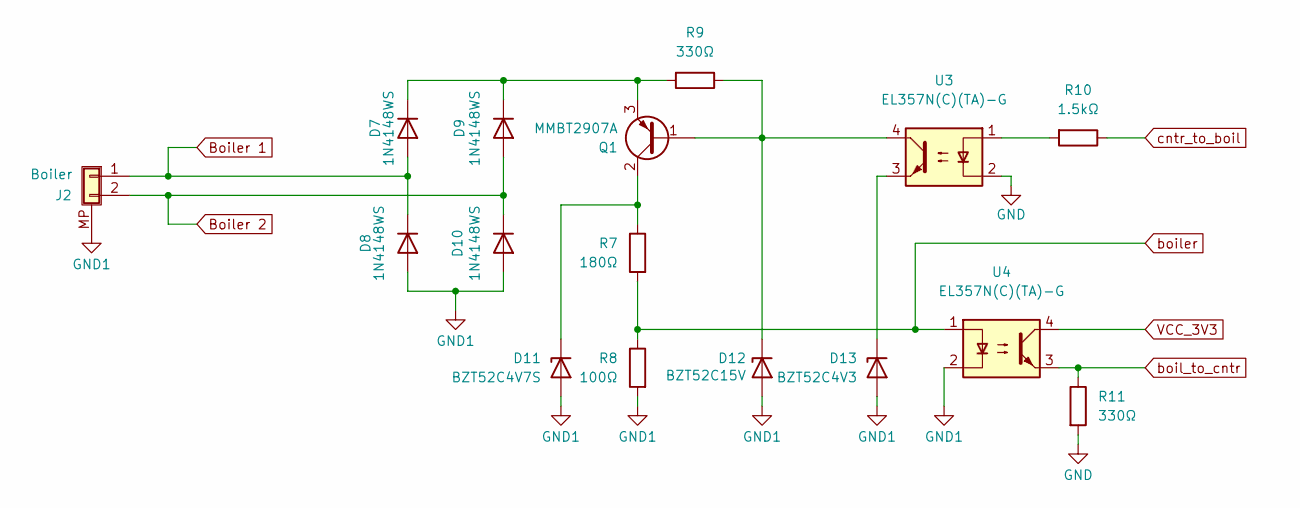
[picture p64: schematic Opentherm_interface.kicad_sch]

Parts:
D7, D8, D9, D10: 1N4148WS; D_SOD-323; LCSC Part # C2128
D11: BZT52C4V7S; D_SOD-323; LCSC Part # C5190168
D12: BZT52C15V; D_SOD-123; LCSC Part # C5299435
D13: BZT52C4V3; D_SOD-123; LCSC Part # C726993
J2: SM02B-SRSS-TB(LF)(SN); JST_SH_SM02B-SRSS-TB_1x02-1MP_P1.00mm_Horizontal; LCSC Part # C160402
Q1: MMBT2907A; SOT-23; LCSC Part # C916373
R7: 180Ω; R_0805_2012Metric; LCSC Part # C25270
R8: 100Ω; R_0805_2012Metric; LCSC Part # C17408
R9, R11: 330Ω; R_0805_2012Metric; LCSC Part # C17630
R10: 1.5kΩ; D_0805_2012Metric; LCSC Part # C4310
U3, U4: EL357N(C)(TA)-G; SO-4_4.4x3.6mm_P2.54mm; LCSC Part # C29981

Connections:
Boiler 1: D7.2 (A), D8.1 (K), J2.1; also elsewhere on the board
Boiler 2: D9.2 (A), D10.1 (K), J2.2; also elsewhere on the board
GND: R11.2, U3.2; also elsewhere on the board
GND1: D8.2 (A), D10.2 (A), D11.2 (A), D12.2 (A), D13.2 (A), J2.MP (Shield), R8.2, U4.2; also elsewhere on the board
unnamed: D7.1 (K), D9.1 (K), Q1.3 (E), R9.2
unnamed: D11.1 (K), Q1.2 (C), R7.1
unnamed: D12.1 (K), Q1.1 (B), R9.1, U3.4
unnamed: D13.1 (K), U3.3
unnamed: R10.2, U3.1
VCC_3V3: U4.4; also elsewhere on the board
boil_to_cntr: R11.1, U4.3; also elsewhere on the board
boiler: R7.2, R8.1, U4.1; also elsewhere on the board
cntr_to_boil: R10.1; also elsewhere on the board

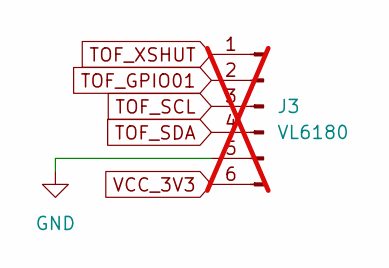
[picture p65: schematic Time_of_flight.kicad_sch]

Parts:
J3: VL6180; PinHeader_1x06_P2.00mm_Vertical; not fitted

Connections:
GND: J3.5; also elsewhere on the board
TOF_GPIO01: J3.2; also elsewhere on the board
TOF_SCL: J3.3; also elsewhere on the board
TOF_SDA: J3.4; also elsewhere on the board
TOF_XSHUT: J3.1; also elsewhere on the board
VCC_3V3: J3.6; also elsewhere on the board

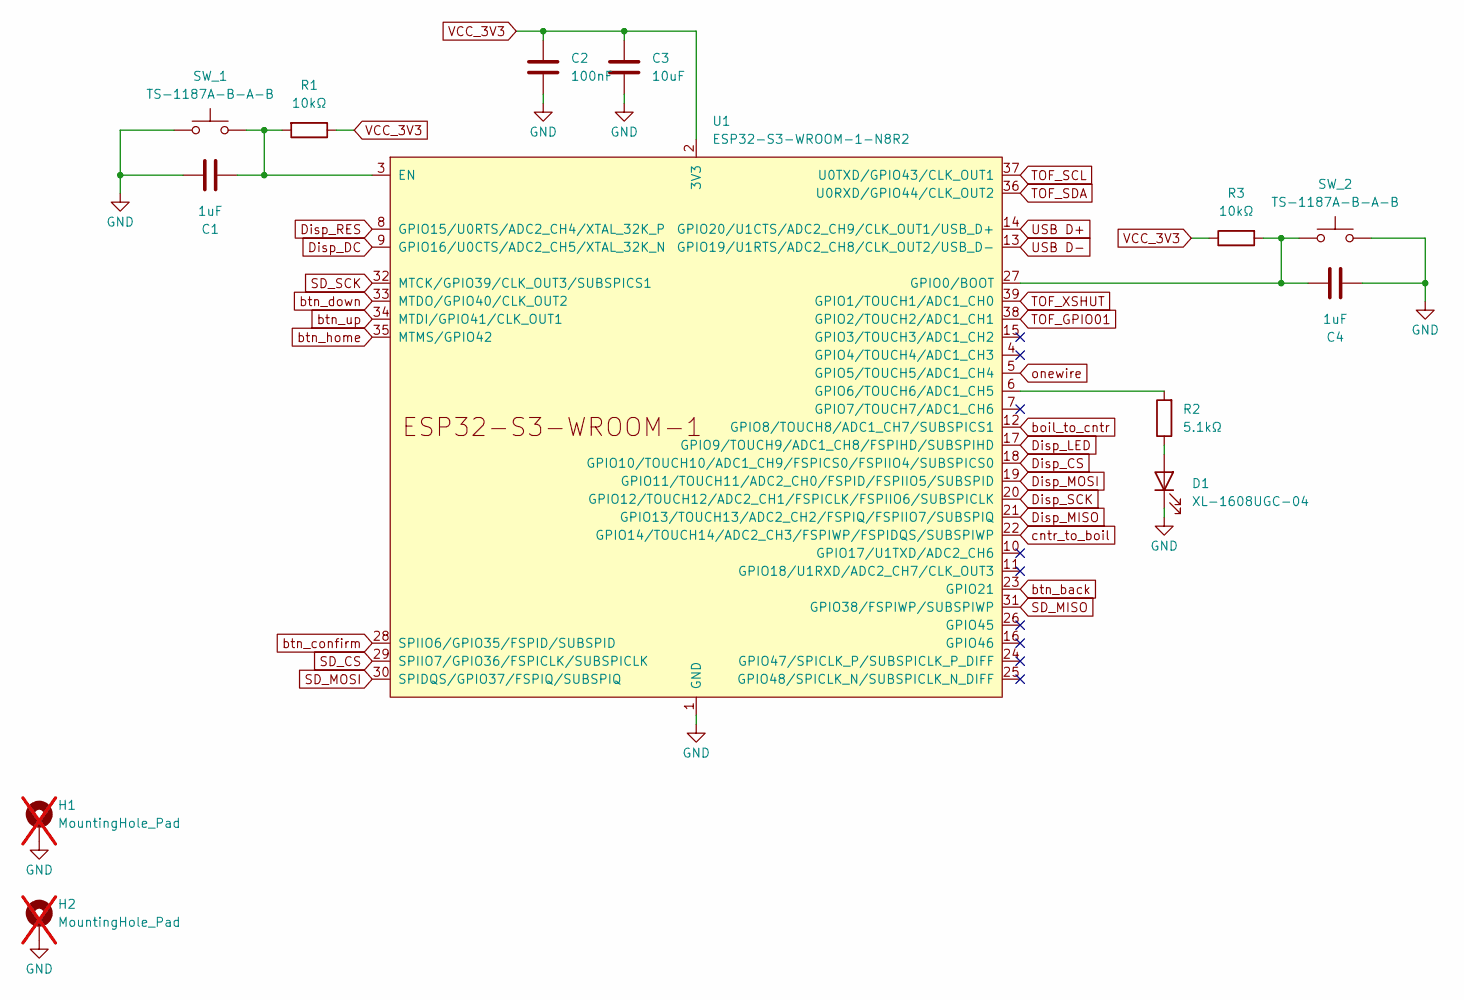
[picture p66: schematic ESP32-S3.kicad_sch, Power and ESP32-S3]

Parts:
C1, C4: 1uF; C_0603_1608Metric; LCSC Part # C15849
C2: 100nF; C_0603_1608Metric; LCSC Part # C14663
C3: 10uF; C_0402_1005Metric; LCSC Part # C15525
D1: XL-1608UGC-04; LED_0603_1608Metric; LCSC Part # C965804
H1, H2: MountingHole_Pad; MountingHole_3.2mm_M3_ISO7380_Pad_TopBottom; not fitted
R1, R3: 10kΩ; R_0603_1608Metric; LCSC Part # C25804
R2: 5.1kΩ; R_0603_1608Metric; LCSC Part # C23186
SW_1, SW_2: TS-1187A-B-A-B; SW_SPST_TL3342; LCSC Part # C318884
U1: ESP32-S3-WROOM-1-N8R2; ESP32-S3-WROOM-1; LCSC Part # C2913204

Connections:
Disp_CS: U1.18 (GPIO10/TOUCH10/ADC1_CH9/FSPICS0/FSPIIO4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); also elsewhere on the board
Disp_DC: U1.9 (GPIO16/U0CTS/ADC2_CH5/XTAL_32K_N); also elsewhere on the board
Disp_LED: U1.17 (GPIO9/TOUCH9/ADC1_CH8/FSPIHD/SUBSPIHD); also elsewhere on the board
Disp_MISO: U1.21 (GPIO13/TOUCH13/ADC2_CH2/FSPIQ/FSPIIO7/S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); also elsewhere on the board
Disp_MOSI: U1.19 (GPIO11/TOUCH11/ADC2_CH0/FSPID/FSPIIO5/S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); also elsewhere on the board
Disp_RES: U1.8 (GPIO15/U0RTS/ADC2_CH4/XTAL_32K_P); also elsewhere on the board
Disp_SCK: U1.20 (GPIO12/TOUCH12/ADC2_CH1/FSPICLK/FSPIIO6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); also elsewhere on the board
GND: C1.2, C2.2, C3.2, C4.2, D1.1 (K), H1.1, H2.1, SW_1.2, SW_2.2, U1.1 (GND), U1.40 (GND), U1.41 (GND); also elsewhere on the board
unnamed: D1.2 (A), R2.1
unnamed: C1.1, R1.2, SW_1.1, U1.3 (EN)
unnamed: C4.1, R3.2, SW_2.1, U1.27 (GPIO0/BOOT)
unnamed: R2.2, U1.6 (GPIO6/TOUCH6/ADC1_CH5)
SD_CS: U1.29 (SPIIO7/GPIO36/FSPICLK/SUBSPICLK); also elsewhere on the board
SD_MISO: U1.31 (GPIO38/FSPIWP/SUBSPIWP); also elsewhere on the board
SD_MOSI: U1.30 (SPIDQS/GPIO37/FSPIQ/SUBSPIQ); also elsewhere on the board
SD_SCK: U1.32 (MTCK/GPIO39/CLK_OUT3/SUBSPICS1); also elsewhere on the board
TOF_GPIO01: U1.38 (GPIO2/TOUCH2/ADC1_CH1); also elsewhere on the board
TOF_SCL: U1.37 (U0TXD/GPIO43/CLK_OUT1); also elsewhere on the board
TOF_SDA: U1.36 (U0RXD/GPIO44/CLK_OUT2); also elsewhere on the board
TOF_XSHUT: U1.39 (GPIO1/TOUCH1/ADC1_CH0); also elsewhere on the board
USB D+: U1.14 (GPIO20/U1CTS/ADC2_CH9/CLK_OUT1/USB_D+); also elsewhere on the board
USB D-: U1.13 (GPIO19/U1RTS/ADC2_CH8/CLK_OUT2/USB_D-); also elsewhere on the board
VCC_3V3: C2.1, C3.1, R1.1, R3.1, U1.2 (3V3); also elsewhere on the board
boil_to_cntr: U1.12 (GPIO8/TOUCH8/ADC1_CH7/SUBSPICS1); also elsewhere on the board
btn_back: U1.23 (GPIO21); also elsewhere on the board
btn_confirm: U1.28 (SPIIO6/GPIO35/FSPID/SUBSPID); also elsewhere on the board
btn_down: U1.33 (MTDO/GPIO40/CLK_OUT2); also elsewhere on the board
btn_home: U1.35 (MTMS/GPIO42); also elsewhere on the board
btn_up: U1.34 (MTDI/GPIO41/CLK_OUT1); also elsewhere on the board
cntr_to_boil: U1.22 (GPIO14/TOUCH14/ADC2_CH3/FSPIWP/FSPIDQS/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); also elsewhere on the board
onewire: U1.5 (GPIO5/TOUCH5/ADC1_CH4); also elsewhere on the board

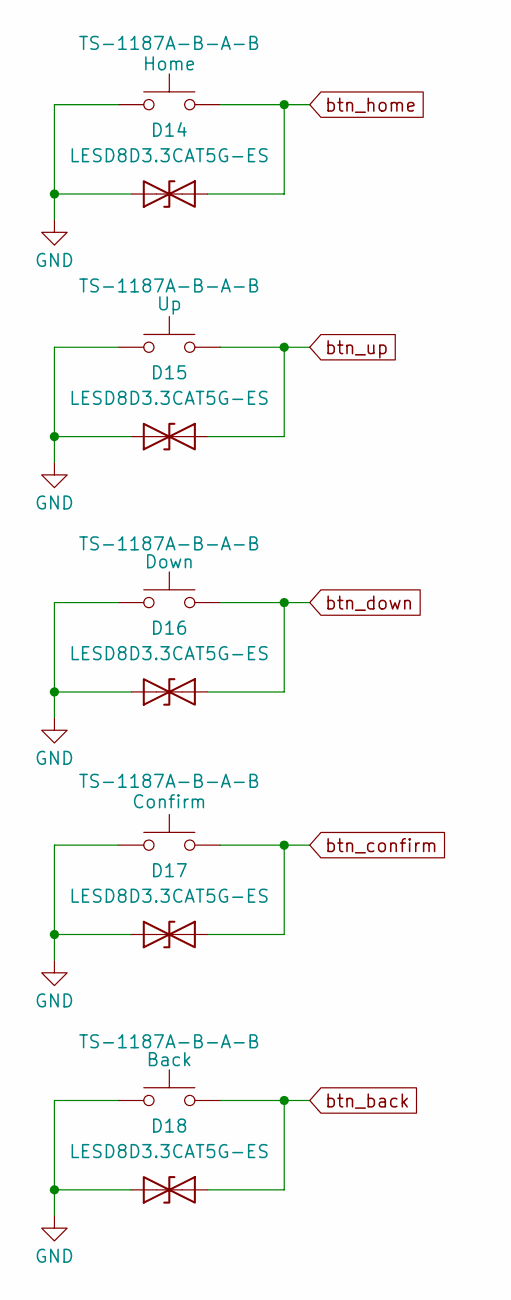
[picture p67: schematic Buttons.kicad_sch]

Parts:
D14, D15, D16, D17, D18: LESD8D3.3CAT5G-ES; D_SOD-882; LCSC Part # C5199186
SW_3, SW_4, SW_5, SW_6, SW_7: TS-1187A-B-A-B; SW_SPST_TL3342; LCSC Part # C318884

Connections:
GND: D14.1 (A1), D15.1 (A1), D16.1 (A1), D17.1 (A1), D18.1 (A1), SW_3.2, SW_4.2, SW_5.2, SW_6.2, SW_7.2; also elsewhere on the board
btn_back: D18.2 (A2), SW_7.1; also elsewhere on the board
btn_confirm: D17.2 (A2), SW_6.1; also elsewhere on the board
btn_down: D16.2 (A2), SW_5.1; also elsewhere on the board
btn_home: D14.2 (A2), SW_3.1; also elsewhere on the board
btn_up: D15.2 (A2), SW_4.1; also elsewhere on the board

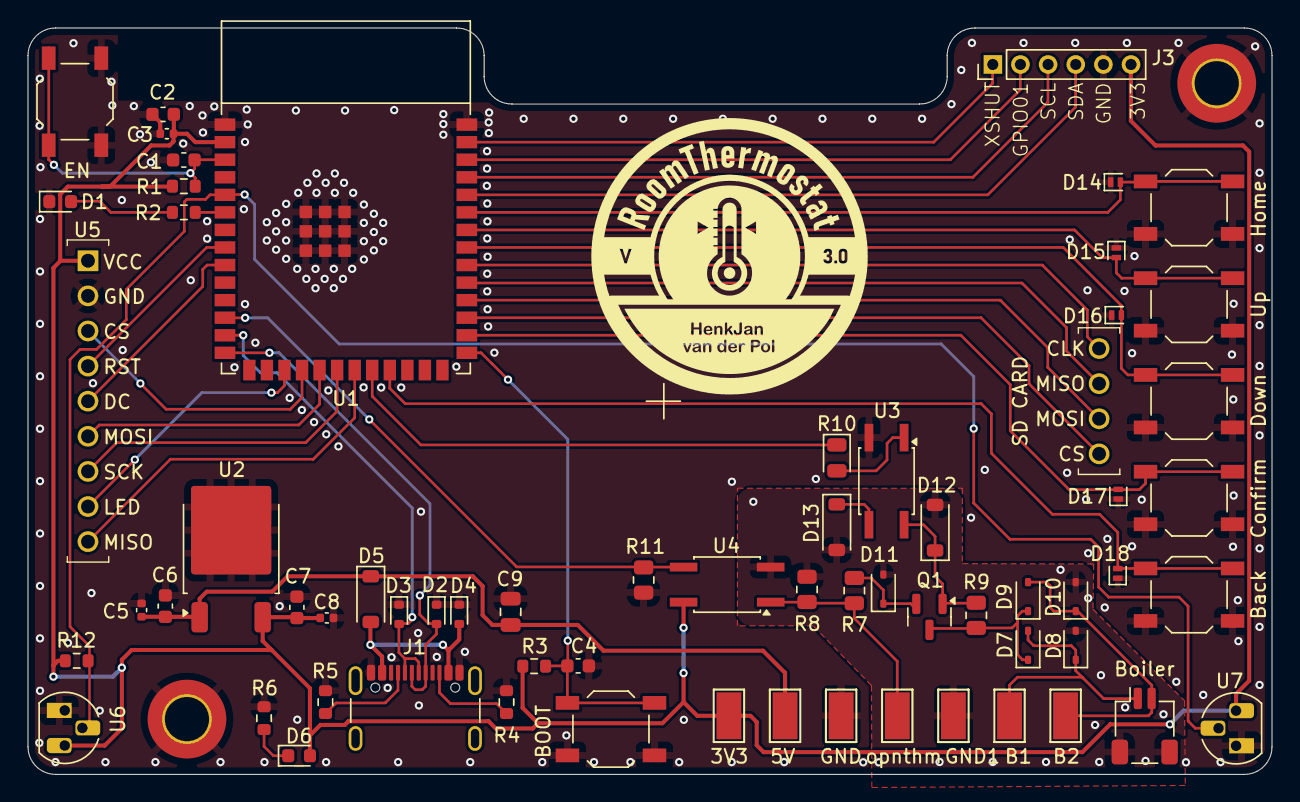
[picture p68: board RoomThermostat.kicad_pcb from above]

Board: 2 copper layers, 90.0 x 54.0 mm, 66 parts (0 on the bottom side), 45 nets.

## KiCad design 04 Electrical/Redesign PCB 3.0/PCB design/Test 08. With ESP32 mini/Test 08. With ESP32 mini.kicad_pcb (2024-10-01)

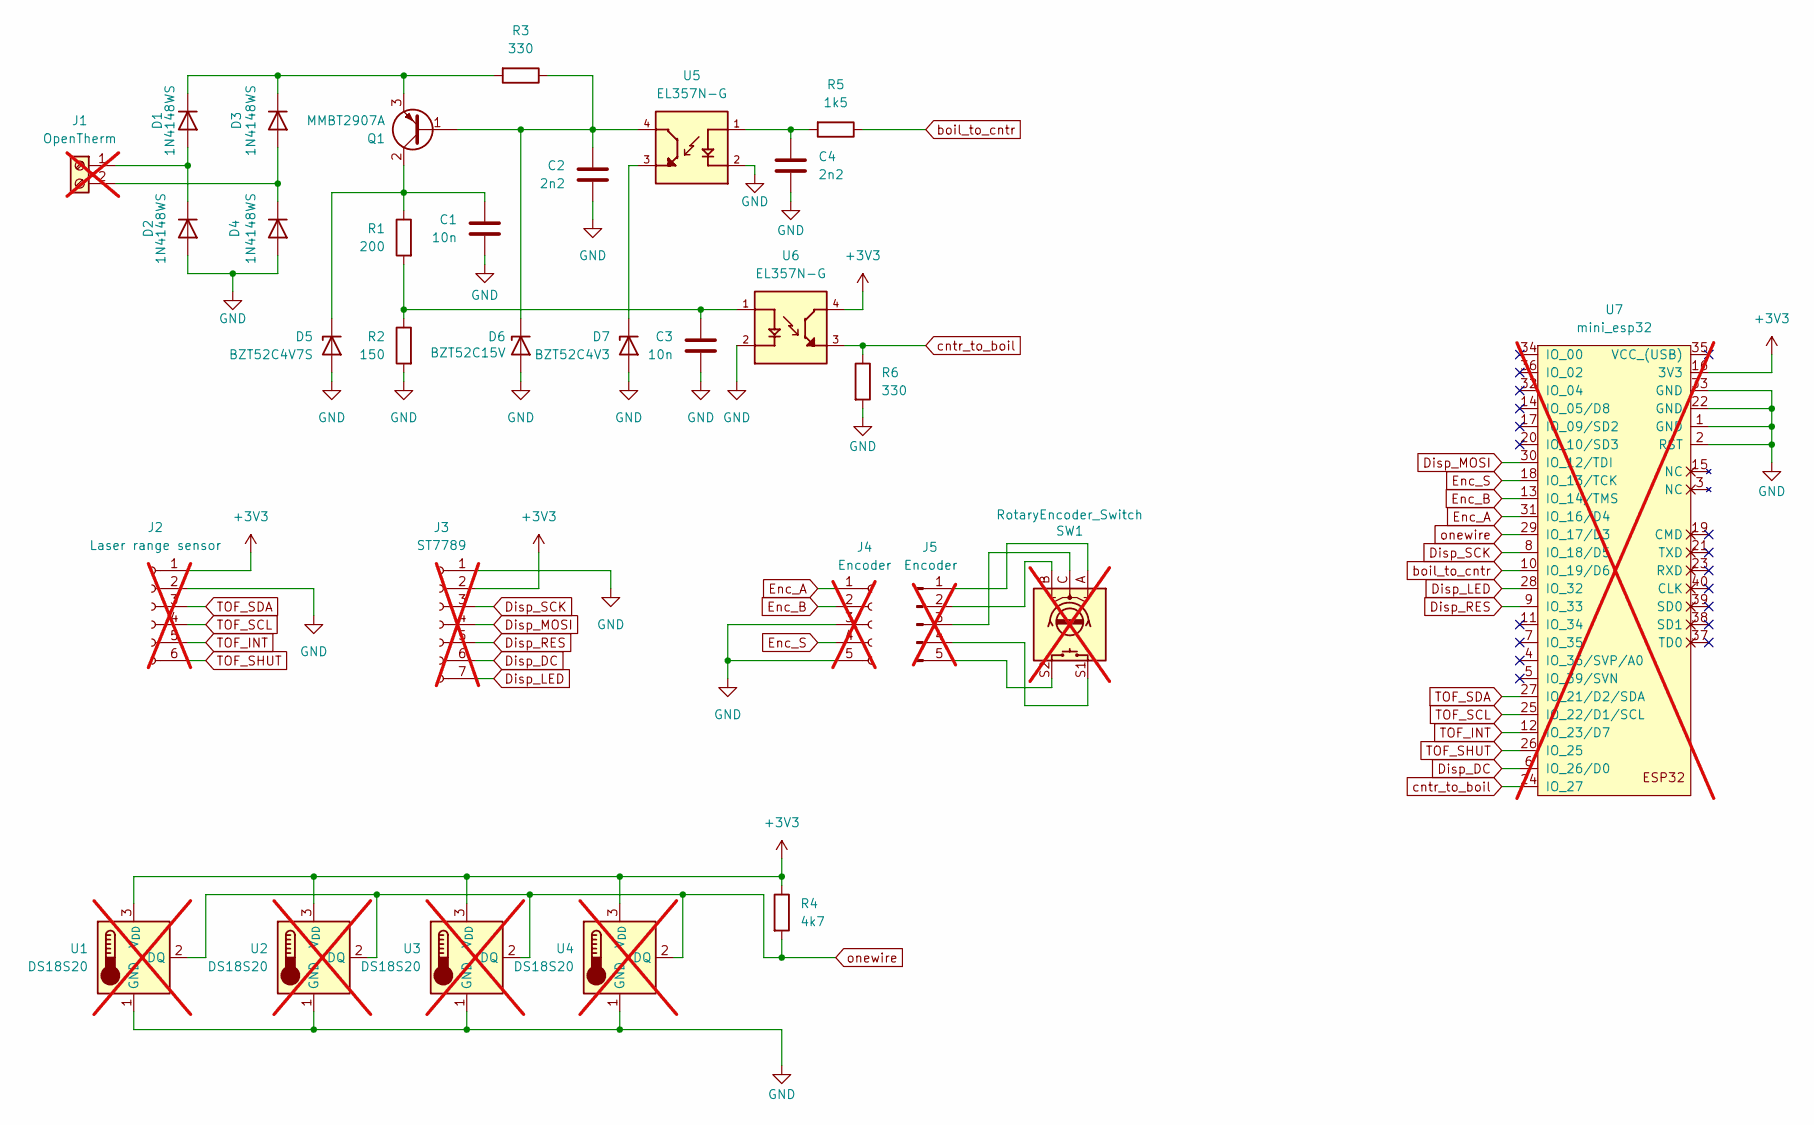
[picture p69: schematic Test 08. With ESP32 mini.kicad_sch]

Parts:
C1, C3: 10n; C_0603_1608Metric; LCSC Part # C57112
C2, C4: 2n2; C_0603_1608Metric; LCSC Part # C1604
D1, D2, D3, D4: 1N4148WS; D_SOD-323; LCSC Part # C2128
D5: BZT52C4V7S; D_SOD-323; LCSC Part # C5190168
D6: BZT52C15V; D_SOD-123; LCSC Part # C5299435
D7: BZT52C4V3; D_SOD-123; LCSC Part # C726993
J1: OpenTherm; TerminalBlock_bornier-2_P5.08mm; not fitted
J2: Laser range sensor; PinHeader_1x06_P2.54mm_Vertical; not fitted
J3: ST7789; PinHeader_1x07_P2.54mm_Vertical; not fitted
J4: Encoder; PinHeader_1x05_P2.54mm_Vertical; not fitted
J5: Encoder; not fitted
Q1: MMBT2907A; SOT-23; LCSC Part # C916373
R1: 200; R_0805_2012Metric; LCSC Part # C25292
R2: 150; R_0805_2012Metric; LCSC Part # C17471
R3: 330; R_0805_2012Metric; LCSC Part # C17630
R4: 4k7; R_0805_2012Metric; LCSC Part # C23162
R5: 1k5; D_0805_2012Metric; LCSC Part # C4310
R6: 330; D_0805_2012Metric; LCSC Part # C17630
SW1: RotaryEncoder_Switch; not fitted
U1, U2, U3, U4: DS18S20; TO-92L_HandSolder; not fitted
U5, U6: EL357N-G; OPTO_EL357N-G; PARTREV 6; LCSC Part # C29981
U7: mini_esp32; ESP32_mini; not fitted

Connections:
+3V3: J2.1, J3.2, R4.1, U1.3 (V_{DD}), U2.3 (V_{DD}), U3.3 (V_{DD}), U4.3 (V_{DD}), U6.4, U7.16 (3V3)
Disp_DC: J3.6, U7.6 (IO_26/D0)
Disp_LED: J3.7, U7.28 (IO_32)
Disp_MOSI: J3.4, U7.30 (IO_12/TDI)
Disp_RES: J3.5, U7.9 (IO_33)
Disp_SCK: J3.3, U7.8 (IO_18/D5)
Enc_A: J4.1, U7.31 (IO_16/D4)
Enc_B: J4.2, U7.13 (IO_14/TMS)
Enc_S: J4.4, U7.18 (IO_13/TCK)
GND: C1.1, C2.2, C3.1, C4.1, D2.2 (A), D4.2 (A), D5.2 (A), D6.2 (A), D7.2 (A), J2.2, J3.1, J4.3, J4.5, R2.2, R6.2, U1.1 (GND), U2.1 (GND), U3.1 (GND), U4.1 (GND), U5.2, U6.2, U7.1 (GND), U7.2 (RST), U7.22 (GND), U7.33 (GND)
unnamed: C3.2, R1.2, R2.1, U6.1
unnamed: C4.2, R5.2, U5.1
unnamed: D1.2 (A), D2.1 (K), J1.1
unnamed: D1.1 (K), D3.1 (K), Q1.3 (E), R3.2
unnamed: D3.2 (A), D4.1 (K), J1.2
unnamed: C1.2, D5.1 (K), Q1.2 (C), R1.1
unnamed: C2.1, D6.1 (K), Q1.1 (B), R3.1, U5.4
unnamed: D7.1 (K), U5.3
unnamed: J5.1, SW1.A
unnamed: J5.2, SW1.B
unnamed: J5.3, SW1.C
unnamed: J5.4, SW1.S1
unnamed: J5.5, SW1.S2
TOF_INT: J2.5, U7.12 (IO_23/D7)
TOF_SCL: J2.4, U7.25 (IO_22/D1/SCL)
TOF_SDA: J2.3, U7.27 (IO_21/D2/SDA)
TOF_SHUT: J2.6, U7.26 (IO_25)
boil_to_cntr: R5.1, U7.10 (IO_19/D6)
cntr_to_boil: R6.1, U6.3, U7.24 (IO_27)
onewire: R4.2, U1.2 (DQ), U2.2 (DQ), U3.2 (DQ), U4.2 (DQ), U7.29 (IO_17/D3)

Board: 2 copper layers, 29 parts (0 on the bottom side), 25 nets, no tracks yet.

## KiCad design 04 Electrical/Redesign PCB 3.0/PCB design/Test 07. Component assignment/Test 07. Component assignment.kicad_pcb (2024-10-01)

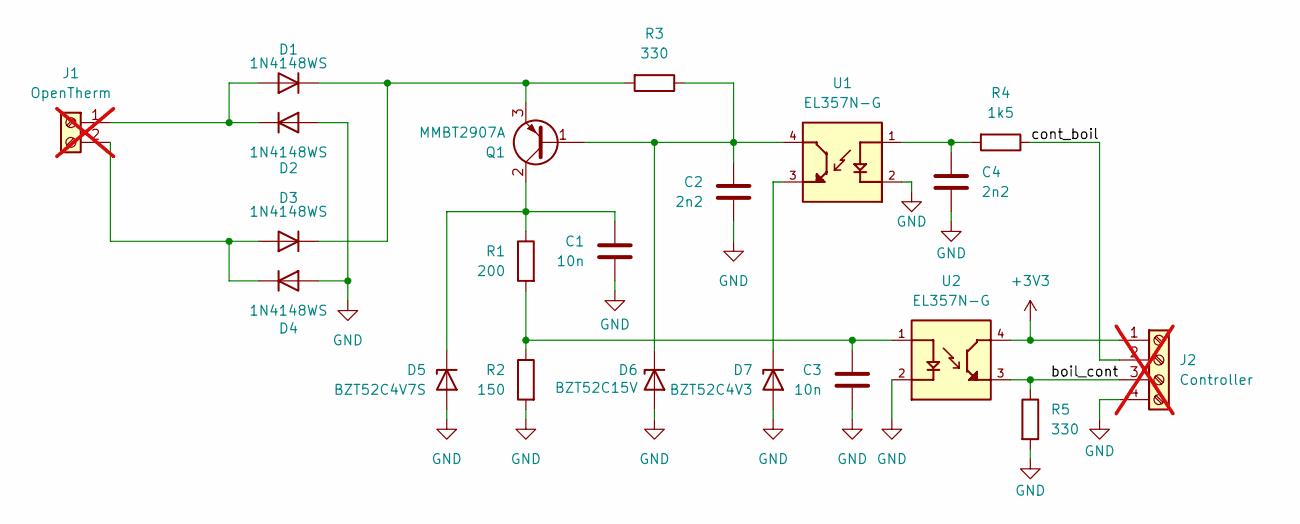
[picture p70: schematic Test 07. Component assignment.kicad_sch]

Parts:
C1, C3: 10n; C_0603_1608Metric; LCSC Part # C57112
C2, C4: 2n2; C_0603_1608Metric; LCSC Part # C1604
D1, D2, D3, D4: 1N4148WS; D_SOD-323; LCSC Part # C2128
D5: BZT52C4V7S; D_SOD-323; LCSC Part # C5190168
D6: BZT52C15V; D_SOD-123; LCSC Part # C5299435
D7: BZT52C4V3; D_SOD-123; LCSC Part # C726993
J1: OpenTherm; TerminalBlock_bornier-2_P5.08mm; not fitted
J2: Controller; TerminalBlock_bornier-4_P5.08mm; not fitted
Q1: MMBT2907A; SOT-23; LCSC Part # C916373
R1: 200; R_0805_2012Metric; LCSC Part # C17540
R2: 150; R_0805_2012Metric; LCSC Part # C17471
R3: 330; R_0805_2012Metric; LCSC Part # C17630
R4: 1k5; R_0805_2012Metric; LCSC Part # C4310
R5: 330; D_0805_2012Metric; LCSC Part # C17630
U1, U2: EL357N-G; OPTO_EL357N-G; PARTREV 6; LCSC Part # C29981

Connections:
+3V3: J2.1, U2.4
/boil_cont: J2.3, R5.1, U2.3
/cont_boil: J2.2, R4.1
GND: C1.1, C2.2, C3.1, C4.1, D2.2 (A), D4.2 (A), D5.2 (A), D6.2 (A), D7.2 (A), J2.4, R2.2, R5.2, U1.2, U2.2
unnamed: C3.2, R1.2, R2.1, U2.1
unnamed: C4.2, R4.2, U1.1
unnamed: D1.2 (A), D2.1 (K), J1.1
unnamed: D1.1 (K), D3.1 (K), Q1.3 (E), R3.2
unnamed: D3.2 (A), D4.1 (K), J1.2
unnamed: C1.2, D5.1 (K), Q1.2 (C), R1.1
unnamed: C2.1, D6.1 (K), Q1.1 (B), R3.1, U1.4
unnamed: D7.1 (K), U1.3

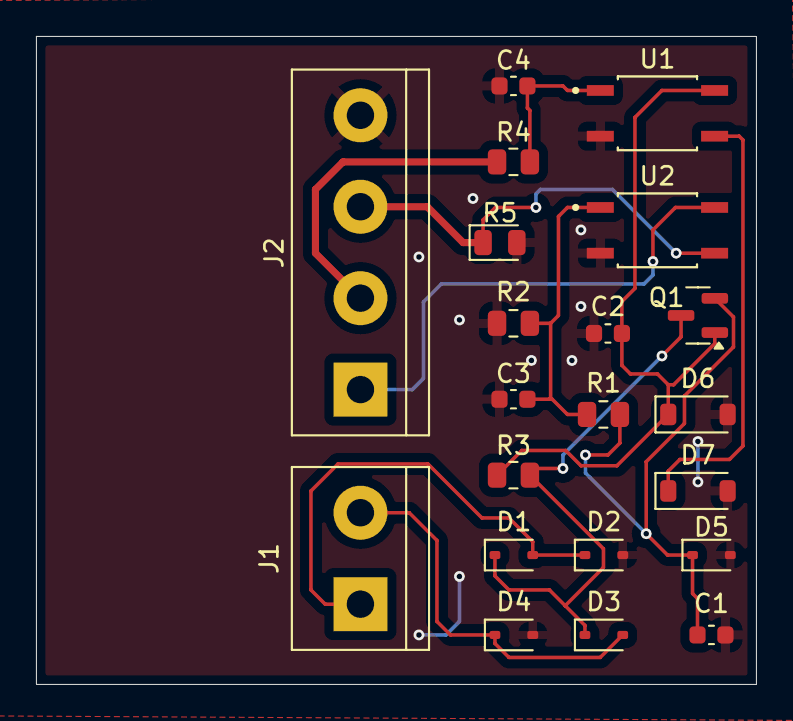
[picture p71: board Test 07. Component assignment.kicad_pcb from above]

Board: 2 copper layers, 40.0 x 36.0 mm, 21 parts (0 on the bottom side), 12 nets.

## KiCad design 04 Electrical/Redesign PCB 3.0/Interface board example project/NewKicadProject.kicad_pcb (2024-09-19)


Board: 2 copper layers, 46.5 x 18.5 mm, 17 parts (0 on the bottom side), 12 nets.

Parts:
D1, D2, D3, D4: 1N4448W; SOD-123_L2.7-W1.6-LS3.7-RD-1
D5: 4V7; SOD-123_L2.7-W1.6-LS3.7-RD-1
D6: 15V; SOD-123_L2.7-W1.6-LS3.7-RD-1
D7: 4V3; SOD-123_L2.7-W1.6-LS3.7-RD-1
J1: Boiler; TerminalBlock_RND_205-00001_1x02_P5.00mm_Horizontal
J2: Screw_Terminal_01x04; TerminalBlock_4Ucon_1x04_P3.50mm_Vertical
Q1: BC858; SOT-23-3_L2.9-W1.3-P1.90-LS2.4-BR
R1: 0805,220; 0805_2012Metric
R2: 1206,100; 1206_3216Metric
R3, R4: 0603,330; 0603_1608Metric
R5: 0402,1.5k; 0402_1005Metric
U1, U2: EL357N(C)(TA)-G; OPTO-SMD-4_L4.4-W4.1-P2.54-LS7.0-TL

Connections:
3V3: J2.1, U2.4 (COL)
GND: D1.2 (A), D2.2 (A), D5.2 (A), D6.2 (A), D7.2 (A), J2.4, R2.2, R4.1, U1.2 (CAT), U2.2 (CAT)
IN: J2.2, R5.2
unnamed: D1.1 (K), D4.2 (A), J1.2
unnamed: D2.1 (K), D3.2 (A), J1.1
unnamed: D3.1 (K), D4.1 (K), Q1.3 (E), R3.1
unnamed: D5.1 (K), Q1.2 (C), R1.1
unnamed: D6.1 (K), Q1.1 (B), R3.2, U1.4 (COL)
unnamed: D7.1 (K), U1.3 (EM)
unnamed: R5.1, U1.1 (AN)
unnamed: R1.2, R2.1, U2.1 (AN)
OUT: J2.3, R4.2, U2.3 (EM)

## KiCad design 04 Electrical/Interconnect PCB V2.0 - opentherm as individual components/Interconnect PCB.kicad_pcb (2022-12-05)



Board: 2 copper layers, 96.0 x 75.0 mm, 12 parts (3 on the bottom side), 20 nets.

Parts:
J1: MSTB-2,5-2-G; Phoenix_MSTB-2,5-2-G
R1: 4k7; Resistor
T1: ButtonUp; TouchPin
T2: ButtonSelect; TouchPin
T3: ButtonDown; TouchPin
U1: MH-ET Live MiniKit; ESP32_mini
U2: ILI9341_touch; ILI9341
U3: DIYless Master Shield; Opentherm Master Shield
U4, U5, U6, U7: DS18B20

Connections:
+3V3: R1.1, U1.16 (3V3), U2.1 (VCC), U3.4 (3V3), U4.3 (VDD), U5.3 (VDD), U6.3 (VDD), U7.3 (VDD)
+5V: U1.35 (VCC_(USB)), U3.19 (5V)
/MISO: U1.10 (IO_19/D6), U2.9 (MISO), U2.13 (T_DO)
/MOSI: U1.12 (IO_23/D7), U2.6 (MOSI), U2.12 (T_DIN)
/OneWire: R1.2, U1.29 (IO_17/D3), U4.2 (DQ), U5.2 (DQ), U6.2 (DQ), U7.2 (DQ)
/SCK: U1.8 (IO_18/D5), U2.7 (SCK), U2.10 (T_CLK)
GND: U1.1 (GND), U1.22 (GND), U1.33 (GND), U2.2 (GND), U3.18 (GND), U4.1 (GND), U5.1 (GND), U6.1 (GND), U7.1 (GND)
unnamed: J1.1, U3.23 (B1)
unnamed: J1.2, U3.24 (B2)
unnamed: T1.1 (BTN), U1.30 (IO_12/TDI)
unnamed: T2.1 (BTN), U1.32 (IO_04)
unnamed: T3.1 (BTN), U1.37 (TD0)
unnamed: U1.9 (IO_33), U2.4 (RESET)
unnamed: U1.13 (IO_14/TMS), U2.3 (~CS)
unnamed: U1.18 (IO_13/TCK), U2.14 (T_IRQ)
unnamed: U1.24 (IO_27), U2.5 (D/~C)
unnamed: U1.25 (IO_22/D1/SCL), U3.22 (OUT)
unnamed: U1.27 (IO_21/D2/SDA), U3.21 (IN)
unnamed: U1.28 (IO_32), U2.8 (LED)
unnamed: U1.31 (IO_16/D4), U2.11 (T_CS)

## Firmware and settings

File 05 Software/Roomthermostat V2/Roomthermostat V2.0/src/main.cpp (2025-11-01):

#define ARDUINOJSON_DECODE_UNICODE 1
#define LOAD_FLASH_FS

#include <Arduino.h>
#include <ArduinoJson.h>
#include "FS.h"
#include <LittleFS.h>
#include "MilliSecTimer.h"

#define VERSION "2.0.0"
// #define USE_TESTBOT true
#define USE_TESTBOT false

/*
  VERSION INFO:
  1.0.0 resolved some errors, improved telegramEnabled()
  1.0.1 timing report removed to prevent locking telegram
  1.0.2 added detailed debug report
        software version added
  1.0.3 boiler message shorter to prevend lockup Telegram
  1.0.4 removed the semaphore since we are no longer using FreeRTOS
        alternative queue for keyboard with simple message
        merge userEventMessage_t with command_t
        BugFix: Telegram responds only is ChatID is in message
  1.0.5 New structure of events and messages implemented
        unity of keyboard message restored
        drive backlight dimming with hardware timer
        increased value of bot.maxMessageLength to prevent lockup of Telegram
        return 7 day icons in Telegram
        implement cmdBoilerSending and cmdBoilerNormal in display
        create an additional debug screen (done in telegram)
  1.0.6 Simple logger added
        Telegram module simplified to be more in line with architectural graph
  1.0.7 Boiler communication interval reduced to 5 sec since otherwise the boiler
        switches to non-Opentherm mode and stops boiling since the connection is open
  1.0.8 Autosave of settings to SPIFFS
        increased value of Telegram maxMessageLength to 6000 to prevent lockup at cmdReportLog
  1.1.0 Over the air software updates implemented
  1.1.1 Menu improvements, emoticons added
        'Forever' mode added to multiple days
        Controller module simplified
  1.1.2 Graphical user interface redesign, using Telegram icons
        Minor improvements to handling overrule multiple days
  1.1.3 Weekend icon changed
  1.1.4 Switch to new Telegram client
  2.0.0 Switch to PlatformIO
        Removed over the air updates
        Changed filesystem from SPIFFS to LittleFS
        Changed storing settings to NVS

  TO DO:
    Potential improvements:
    * use MillisecTimer where possible
    * ESP crashes after use of hardware buttons
    * improve responsiveness (keys and Telegram)
      * try to get FreeRTOS working again to improve performance of buttons and Telegram
        * perhaps Telegram can run on other core?
      * implement OpenTherm protocol in hardware timer in non-blocking way
    * include icons in the menu
    * save logdata through WiFi connection
      * Deta Base?
      * send logfile as attachment to Telegram
    * much code can be simplified to remove structures that were used in previous attempts to get the code working
       * some userEventMessage_t constructs can be replaced with sendMessage() calls
       * some userEventMessage_t constructors may no longer be used
       * ...
    * send automatic updates to last message of known clients every 15 minutes
      * also store list of chatIDs in permanent storage?
      * add functionality to whitelist or blacklist chatIDs?
    * optimize heater control functionality
        * allow user to modify water temperature of heater and shower
        * check if D-action is implemented well in PID controller
        * take into account the weather in the control strategy
        * monitor the time it takes to heat the room in the morning, and compensate that by starting earlier or start with higher temperature
    * also enable setting the time and date through hardware buttons if WiFi is unavailable
    * display progress upon startup
    * try if SPI frequency in TFT_eSPI can be set to higher value

    Code cleanup:
    * find replace action GoOut > Leave
    * cleanup Serial.print
    * check use of const in function calls
    * cleanup the use of messages. Some fields may no longer be needed

    Hardware:
    * add a capacitor to prevent brownout of the ESP32 at startup
*/

#include "a_constants.h"
#include "b_logger.h"
#include "c_interfaces.h"
#include "d_keyboard.h"
#include "e_menu.h"
#include "f_telegram.h"
#include "g_controller.h"
#include "h_temperature.h"
#include "i_wifi_time.h"
#include "j_jpeg.h"
#include "k_display.h"
#include "l_backlight.h"

#include <esp_task_wdt.h>      // Watchdog timer
#define WATCHDOG_TIMEOUT 3*60  // 3 minute watchdog
#define REPORT_INTERVAL 60000

void listDir(fs::FS &fs, const char * dirname, uint8_t levels){
    Serial.printf("Listing directory: %s\r\n", dirname);

    File root = fs.open(dirname);
    if(!root){
        Serial.println("- failed to open directory");
        return;
    }
    if(!root.isDirectory()){
        Serial.println(" - not a directory");
        return;
    }

    File file = root.openNextFile();
    while(file){
        if(file.isDirectory()){
            Serial.print("  DIR : ");
            Serial.println(file.name());
            if(levels){
                listDir(fs, file.name(), levels -1);
            }
        } else {
            Serial.print("  FILE: ");
            Serial.print(file.name());
            Serial.print("\tSIZE: ");
            Serial.println(file.size());
        }
        file = root.openNextFile();
    }
}


void setup() {
  userEventMessage_t message;

  // Initilize serial port
  Serial.begin(115200);

  // Prepare onboard LED for output and switch LED off (used for over the air update)
  pinMode(PIN_ESP32_LED, OUTPUT);
  digitalWrite(PIN_ESP32_LED, false);

  // Initialize LITTLEFS
  delay(300);
  if (!LittleFS.begin(
        /*formatOnFail=*/true,
        /*basePath=*/"",
        /*maxOpenFiles=*/10,
        /*partitionLabel=*/"littlefs"  // <- must match partition label
      )) {
    delay(300);
    Serial.println("LittleFS mount failed");
    return;
  }

  // listDir(LittleFS, "/", 5);

  Serial.printf("Loading config data from '%s'\n", CONFIG_FILE);
  controllerData.loadConfig(LittleFS, CONFIG_FILE);
  Serial.printf("Bot API '%s'\n", controllerData.botToken.c_str());

  Serial.println("Loading controller settings");
  controllerData.loadSettingsNVS();

  Serial.println("Initializing menu");
  startMenu();

  Serial.println("Initializing temperature sensors and boiler");
  startTemperature();

  Serial.println("Initializing controller");
  startController();

  Serial.println("Initializing display");
  startDisplay();

  // delay(500);
  Serial.println("Initializing WiFi");
  WiFi.mode(WIFI_STA);
  WiFi.persistent(false);
  // WiFi.setTxPower(WIFI_POWER_8_5dBm); // default is 19.5 dBm
  // WiFi.setTxPower(WIFI_POWER_2dBm); // default is 19.5 dBm
  // WiFi.setTxPower(WIFI_POWER_MINUS_1dBm); // default is 19.5 dBm

  setupWifi(controllerData);
  // delay(500);

  Serial.println("Initializing backlight");
  startBacklight();

  Serial.println("Initializing Telegram handler");
  startTelegram();

  Serial.println("Initializing keyboard");
  startKeyboard();

  // Enable watchdog
  Serial.println("Configuring watchdog");
  esp_task_wdt_init(WATCHDOG_TIMEOUT, true); //enable panic so ESP32 restarts
  esp_task_wdt_add(NULL); //add current thread to WDT watch

  Serial.println("Setup finished\n\n");
}

void loop() {
  static unsigned long lastTimeDetailedReport=0;      // last time temperature measurement was done
  // static unsigned long lastSettingsSave = millis();
  static int eventCounter = 0;
  static int counter =0;
  userEventMessage_t message;
  static MilliSecTimer settingsTimer(60*1000); // Save settings every minute if changed

  // ArduinoOTA.handle();

  // If controller settings were changed, autosave the settings every minute
  if(settingsTimer.lapsed()) {
    // lastSettingsSave = millis();
    if( controllerData.settingsChanged ) {
      disableKeyboard(); // Really necessary!
      // controllerData.saveSettings(LittleFS, SETTINGS_TEMP, SETTINGS_FILE);
      controllerData.saveSettingsNVS();
      enableKeyboard();
      Serial.println("Autosaved settings");
    }
  }

  controllerData.logBusyTime.start(btTotal);
  controllerData.logBusyTime.start(btTemperature);    checkTemperatureIfNeeded();              controllerData.logBusyTime.finish(btTemperature);
  controllerData.logBusyTime.start(btMenu);           checkMenu();                             controllerData.logBusyTime.finish(btMenu);
  controllerData.logBusyTime.start(btDisplay);        checkDisplayQueue();                     controllerData.logBusyTime.finish(btDisplay);
  controllerData.logBusyTime.start(btTelegram);       checkTelegramIfNeeded();                 controllerData.logBusyTime.finish(btTelegram);
  controllerData.logBusyTime.start(btController);     processControllerIfNeeded();             controllerData.logBusyTime.finish(btController);
  controllerData.logBusyTime.start(btBacklight);      checkBacklight();                        controllerData.logBusyTime.finish(btBacklight);
  controllerData.logBusyTime.start(btWifi);           reconnectWiFiIfNeeded(controllerData);   controllerData.logBusyTime.finish(btWifi);

  controllerData.logBusyTime.start(btTimeSynch);
  requestTimeZoneIfNeeded(controllerData);
  syncTimeIfNeeded(controllerData);
  controllerData.logBusyTime.finish(btTimeSynch);

  controllerData.logBusyTime.finish(btTotal);

  if (millis() - lastTimeDetailedReport > REPORT_INTERVAL) {
    lastTimeDetailedReport = millis();
    Serial.println( String("Wifi connected: ") + String(wifiConnected() ? "Y" : "N") );
    Serial.println( controllerData.logBusyTime.report() );
    int64_t t1 = esp_timer_get_time();
    multi_heap_info_t heapInfo;
    heap_caps_get_info( &heapInfo, MALLOC_CAP_DEFAULT );

    Serial.println( String("Software version: ") + VERSION );
    Serial.println( String("- Time since reboot: ") + secondsToDuration(t1/1e6) );
    Serial.println( String("- Keyboard polling microseconds: ") + String(keyboardMicroSeconds) );
    Serial.println( String("- Temperature measurement successful: ") + String(controllerData.temperatureMeasurementOK ? "Y" : "N") );
    Serial.println( String("- Total free bytes in the heap: ") + String(heapInfo.total_free_bytes) );
    Serial.println( String("- Total bytes allocated to data in the heap: ") + String(heapInfo.total_allocated_bytes) );
    Serial.println( String("- Size of the largest free block in the heap: ") + String(heapInfo.largest_free_block) );
    Serial.println( String("- Lifetime minimum free heap size: ") + String(heapInfo.minimum_free_bytes) );
    Serial.println( String("- Number of blocks allocated in the heap: ") + String(heapInfo.allocated_blocks) );
    Serial.println( String("- Number of free blocks in the heap: ") + String(heapInfo.free_blocks) );
    Serial.println( String("- Total number of blocks in the heap: ") + String(heapInfo.total_blocks) );
  }

  // Reset watchdog timer
  esp_task_wdt_reset();
}

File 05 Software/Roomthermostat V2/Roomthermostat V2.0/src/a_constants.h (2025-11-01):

#pragma once

#include <map>
#include <list>
#include <string>

using namespace std;

/*************************
 * PINOUT OF PERIPHERALS *
 *************************/

#define PIN_ESP32_LED             2
// OpenTherm Shield pins configuration
#define PIN_OPENTHERM_IN         22   // beware: in and out were flipped due to mistake creating a symbol in KiCad
#define PIN_OPENTHERM_OUT        21

// One wire bus and temperature sensor
#define PIN_ONE_WIRE_BUS         17
#define TEMPERATURE_PRECISION    11   // Resolution 0.125°C. Requires 375 ms to fetch temperature

// Keyboard
#define PIN_BUT_UP               12   // Capacitive pin for up button
#define PIN_BUT_SELECT            4   // Capacitive pin for select button
#define PIN_BUT_DOWN             15   // Capacitive pin for down button

#define KEYBOARD_TIMER_ID         0   // Number of the keyboard timer (0..3)
#define KEY_THRESHOLD            25   // Level to trigger capacitive keyboard button

// Backlight
#define PIN_BACKLIGHT            32

#define BACKLIGHT_TIMEOUT       20*1000
#define BACKLIGHT_LED_CHANNEL         0
#define BACKLIGHT_FREQUENCY        5000
#define BACKLIGHT_RESOLUTION          8

// Pinout of the display is in the TFT_eSPI config file

// Display
// Screen colors converted to RGB565
#define CLR_BACKGROUND       0xFFFF   // FF, FF, FF = white
#define CLR_CIRCLE_OUTLINE   0x738E   // 73, 73, 73 = dark grey
#define CLR_CIRCLE_FILL      0xEE13   // E8, C3, 9E = beige
#define CLR_MEASURED_TEMP    0x0000   // 00, 00, 00 = black
#define CLR_DARK_TEXT        0x8410   // 80, 80, 80 = dark grey
#define CLR_LIGHT_TEXT       0xB596   // B0, B0, B0 = light grey
#define CLR_SETPOINT_TEMP    0xF8C3   // FF, 19, 19 = red
#define CLR_MENU_TITLE       0x0000   // 00, 00, 00 = black
#define CLR_MENU_SUBTITLE    0x8410   // 80, 80, 80 = dark grey
#define CLR_MENU_TEXT        0x0000   // 00, 00, 00 = black
#define CLR_MENU_SELECT      0xF8C3   // FF, 19, 19 = red
#define CLR_BLUE_TEXT        0x1A7F   // 19, 4F, FF = blue
#define CLR_RED_TEXT         0xF8C3   // FF, 19, 19 = red

// Screen fonts
#define FONT_MENU_HEADER        "Noway_Medium24"  // Font Noway_Medium24 height 24
#define FONT_MENU               "Noway_Light18"   // Font Noway_Light18 height 17
#define FONT_SUBMENU            "Noway_Light18"   // Font Noway_Light18 height 17
#define FONT_DATE               "Noway_Light24"   // Font Noway_Light24 height 23
#define FONT_TIME               "Noway_Medium24"  // Font Noway_Medium24 height 24
#define FONT_TEMP_MEASURED      "Noway_Medium60"  // Font Noway_Medium60 height 58
#define FONT_TEMP_MEASURED_DEG  "Noway_Light32"   // Font Noway_Light32 height 31
#define FONT_TEMP_SETPOINT      "Noway_Medium32"  // Font Noway_Medium32 height 31
#define FONT_TEMP_SETPOINT_DEG  "Noway_Light18"   // Font Noway_Light18 height 17
#define FONT_NORMAL             "Noway_Regular24" // Font Noway_Regular24 height 23
#define FONT_MEDIUM             "Noway_Medium24"  // Font Noway_Medium24 height 24

/*
  Height in pixels for each font:
  Font Noway_Medium24 height    24
  Font Noway_Light18 height     17
  Font Noway_Light24 height     23
  Font Noway_Medium60 height    58
  Font Noway_Light32 height     31
  Font Noway_Medium32 height    31
  Font Noway_Regular24 height   23
 */

#define SECS_PER_MINUTE  (         60                   )
#define SECS_PER_HOUR    (         60 * SECS_PER_MINUTE )
#define SECS_PER_DAY     (         24 * SECS_PER_HOUR   )
#define SECS_PER_WEEK    (          7 * SECS_PER_DAY    )
#define SECS_PER_YEAR    ( 365.242199 * SECS_PER_DAY    )
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

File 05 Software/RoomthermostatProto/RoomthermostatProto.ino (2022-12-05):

#include <TFT_eSPI.h>
#include <SPI.h>
#include <JPEGDecoder.h>
#include "SPIFFS.h"
#include "time.h"

#include <esp_task_wdt.h> // Watchdog timer

#define WDT_TIMEOUT 180   // 3 minutes watchdog


//#define USE_ILI9341
#define USE_BUTTONS

// Preceding letters added since Arduino opens libraries in alphabetical order
#include "a_Constants.h"
#include "b_Buttons.h"
#include "c_Eventlog.h"
#include "d_Heaterprogram.h"
#include "e_Controller.h"
#include "f_Wifi.h"
#include "g_Time.h"
#include "h_Datalogging.h"
#include "i_Telegram.h"

#ifdef USE_ILI9341
#include "j_jpeg.h"
#include "k_Menu.h"
#endif


TFT_eSPI tft = TFT_eSPI();       
TFT_eSprite menuItem = TFT_eSprite(&tft);
Data data;

#ifdef USE_ILI9341
Menu menu(&tft, &menuItem, &data);
#endif

/*
ToDo: 

implement low pass filter on temperature measurements

study effectivity of anti-windup during the night

make the status description in Telegram more clear, perhaps also with a hint on next steps

check if Opentherm indeed needs 4 wires (3V3, GND, in, out)
solder actual device
check if buttons work (perhaps lower controller and log frequency)

align normal menu structure with telegram menu structure 

implement saving data in JSON file, including whole schedule

also setting for temperature offset
also setting for hot water temperature
implement switching heater off permanently

additional screen for boiler data

menu to set the time if wifi if not connected
incorporate screen saver and wake-up
check if menuItem sprite can also be declared in the menu class (instead of being a global variable)
export logfile through telegram CSV

over the air updates through telegram

permanently load JPEGs in RAM
perhaps more colors for icons

wifi connection through local hub
*/
 
void setup() {
  // Initilize serial port
  Serial.begin(115200);

  // Initialize SPIFFS
  SPIFFS.begin();
  delay(500);

  // Load config data from SPIFFS
  data.loadConfig(SPIFFS, CONFIG_FILE);

  // Prepare backlight dimming
  /*
  ledcSetup(BCK_LED_CHANNEL, BCK_PWM_FREQ, BCK_RESOLUTION);
  ledcAttachPin(PIN_BACKLIGHT, BCK_LED_CHANNEL);
  ledcWrite(BCK_LED_CHANNEL, 8);
  */
  
  #ifdef USE_ILI9341
  // Initialize screen
  tft.init();
  tft.setRotation(3);
  tft.fillScreen(CLR_LIGHT_TEXT);
  tft.setTextDatum(MC_DATUM);
  tft.loadFont(FONT_TEMP_MEASURED); 
  tft.setTextColor(CLR_DARK_TEXT, CLR_LIGHT_TEXT);
  tft.drawString("Welcome", 160, 120);
  #endif

  // Initialize wifi
  setupWifi(data);

  // Initialize keyboard
  startKeyboard();

  // Initialize temperature controller
  startController();
  
  data.wifiConnected = (WiFi.status() == WL_CONNECTED);

  // Check current daylight saving time for our timezone
  requestTimeZoneIfNeeded(data);

  // Sync with atomic clock
  syncTimeIfNeeded(data);

  setupTelegram(data);

  // Draw menu
  #ifdef USE_ILI9341
  menu.selectMenu(mnHomeScreen);
  #endif

  // Enable watchdog
  Serial.println("Configuring watchdog");
  esp_task_wdt_init(WDT_TIMEOUT, true); //enable panic so ESP32 restarts
  esp_task_wdt_add(NULL); //add current thread to WDT watch
  
  logMessage("Thermostat restarted");
}

void loop() {
  
  // Check if a button is pressed
  #ifdef USE_ILI9341
  if     (keyUp)     { menu.buttonUp();     keyUp    =false; }
  else if(keySelect) { menu.buttonSelect(); keySelect=false; }
  else if(keyDown  ) { menu.buttonDown();   keyDown  =false; }
  #endif

  data.wifiConnected = (WiFi.status() == WL_CONNECTED);

  // Determine if setpoint temperature needs to be changed
  data.setSetpoint();

  requestTimeZoneIfNeeded(data);
  syncTimeIfNeeded(data);
  
  #ifdef USE_ILI9341
  menu.periodicScreenUpdate();
  #endif

  reconnectIfNeeded(data);
  handleTelegramIfNeeded(data);
  logIfNeeded(data);
  sendLogFileIfNeeded();
  controlTemperatureIfNeeded(data);

  // Reset watchdog timer
  esp_task_wdt_reset();      
}

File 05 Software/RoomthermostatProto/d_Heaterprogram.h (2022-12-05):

#pragma once

#include <list>
#include <map>
#include <string>
#include <cmath>
#include "time.h"
#include <ArduinoJson.h>
#include <OpenTherm.h>

#include "a_Constants.h"
#include "c_Eventlog.h"

using namespace std;

// All data in the thermostat
// most importantly the switching of the temperature setpoint
class Data {
  public:
    Data() { setSetpoint(); };

    // WIFI ACCESS POINT INFORMATION
    list<tAccessPoint> AccessPoints;
    bool locationKnown=false;            
    bool timeSynched=false;
    char timezone[64]="Europe/Amsterdam";
    int  timeZoneOffset=3600;
    int  timeDSToffset=0;
    bool wifiConnected = false;

    // PROGAM TO SWITCH THE TEMPERATURE SETPOINT
    // Regular weekly schedule (Sunday is day 0)
    //                           Sunday     Monday          Tuesday         Wednesday       Thursday        Friday          Saturday  
    dayType_t regularWeek[7] = { dtWeekend, dtWorkAtOffice, dtWorkAtOffice, dtWorkAtOffice, dtWorkAtOffice, dtWorkAtOffice, dtWeekend }; 

    timeValue_t workFromHomeWakeUp = {  6, 45 };
    timeValue_t workFromHomeSleep  = { 21, 30 };

    timeValue_t workAtOfficeWakeUp = {  6, 45 };
    timeValue_t workAtOfficeGoOut  = {  7, 30 };
    timeValue_t workAtOfficeComeIn = { 17, 00 };
    timeValue_t workAtOfficeSleep  = { 21, 30 };

    timeValue_t weekendWakeUp      = {  9, 00 };
    timeValue_t weekendSleep       = { 22, 30 };

    float highTemp = 19.5;
    float lowTemp  = 10.0;

    // Current settings of temperature
    dayType_t overrideToday     = dtAuto;
    dayType_t overrideTomorrow  = dtAuto;
    dayType_t overrideMultiple  = dtAuto;
    int overrideMultipleCount   = 3;

    bool overrideTempNow = false;
    float overrideSetpoint = 19.5;
    setpointReason_t reasonForSetpoint;

    //bool forceMessageToController=true;

    // TEMPERATURE MEASUREMENT
    // Measuring and controlling the temperature
    float measuredTemperatureOffset = -2.6; // Actual temperature = raw sensor signal + offset

    // TEMPERATURE CONTROL
    float temperatureSetpoint = 21.0;
    float domesticHotWaterSetpoint = 55.0;
    float actualDomesticHotWaterTemperature;
    float measuredTemperature;
    float boilerPercentage;
    float requestedBoilerTemperature;
    float P;
    float I;
    float D;
    float ierr;
    float derivative;
    bool isCentralHeatingActive;
    bool isHotWaterActive;
    bool isFlameOn;
    float actualBoilerTemperature;
    String responseFromController="Not started yet";
    
    bool enableCentralHeating = true;
    bool enableHotWater = true;
    bool enableCooling = false;
    
    // DISPLAY OF THE PHYSICAL DEVICE
    // Screen and messages
    bool forceScreenUpdate=true;

    enum icon_t icons[7] = { iconHome, iconWork, iconWeekend, iconWeekend, iconAway, iconAway, iconAway };

    // TELEGRAM
    // Telegram bot settings
    String botName;
    String botUserName;
    String botToken;
    String botChatID;

    void loadConfig(fs::FS &fs, const char * configFile);
    void setIcons();
    void setSetpoint();

    // Various handlers for the user interface, both device and Telegram
    void setpointLower();
    void setpointAuto();
    void setpointHigher();
    void goAway();
    void overruleTodayWorkFromHome();
    void overruleTodayWorkFromOffice();
    void overruleTodayWeekend();
    void overruleTodayAway();
    void overruleTodayAutomatic();
    void overruleTomorrowWorkFromHome();
    void overruleTomorrowWorkFromOffice();
    void overruleTomorrowWeekend();
    void overruleTomorrowAway();
    void overruleTomorrowAutomatic();
    void overruleMultipleWorkFromHome();
    void overruleMultipleWorkFromOffice();
    void overruleMultipleWeekend();
    void overruleMultipleAway();
    void overruleMultipleAutomatic();
    void overruleMultipleLessDays();
    void overruleMultipleMoreDays();
    void setWeekSchedule(uint8_t dayOfWeek, dayType_t typeOfDay);
    void workFromHomeWakeUpEarlier();
    void workFromHomeWakeUpLater();
    void workFromHomeSleepEarlier();
    void workFromHomeSleepLater();
    void workFromOfficeWakeUpEarlier();
    void workFromOfficeWakeUpLater();
    void workFromOfficeGoOutEarlier();
    void workFromOfficeGoOutLater();
    void workFromOfficeComeInEarlier();
    void workFromOfficeComeInLater();
    void workFromOfficeSleepEarlier();
    void workFromOfficeSleepLater();
    void weekendWakeUpEarlier();
    void weekendWakeUpLater();
    void weekendSleepEarlier();
    void weekendSleepLater();
    void highTempLower();
    void highTempHigher();
    void lowTempLower();
    void lowTempHigher();

  private:

};

void Data::loadConfig(fs::FS &fs, const char * configFile) {    
  // Retrieve configuration data from the configuration file stored in SPIFFS 
  StaticJsonDocument<1024> doc;

  File input = fs.open(configFile);
  DeserializationError error = deserializeJson(doc, input);
  
  if (error) {
    Serial.print(F("deserializeJson() of configfile failed: "));
    Serial.println(error.f_str());
    return;
  }
      
  for (JsonObject elem : doc["AccessPoints"].as<JsonArray>()) {
    tAccessPoint AccessPoint;
    strlcpy(AccessPoint.ssid     ,elem["SSID"],    sizeof(AccessPoint.ssid    ));
    strlcpy(AccessPoint.password ,elem["password"],sizeof(AccessPoint.password));
    strlcpy(AccessPoint.timezone ,elem["timezone"],sizeof(AccessPoint.timezone));          
    AccessPoints.push_back(AccessPoint);  
  }
  
  botName=    doc["BotName"    ].as<String>();
  botUserName=doc["BotUsername"].as<String>();
  botToken=   doc["BotToken"   ].as<String>();
  botChatID=  doc["ChatID"     ].as<String>();

  Serial.println("Config loaded");  
};

void Data::setIcons() {
  time_t now;
  time(&now); // Get current time
  struct tm * lctm = localtime(&now); // Convert time to local time

  uint8_t dayOfWeek = lctm->tm_wday;
  dayType_t daytype;

  // By default, set the icons according to the weekly schedule
  for(int i=0; i<7; i++) {
    daytype=regularWeek[dayOfWeek];  // 0=Sunday
    icons[i]=DAYTYPE_TO_ICON[daytype];
    dayOfWeek++;
    if(dayOfWeek>6) dayOfWeek=0;
  };

  // Override multiple days if needed
  if(overrideMultiple!=dtAuto) {
    for(int i=0; i<overrideMultipleCount; i++) {
      if(i<7) icons[i]=DAYTYPE_TO_ICON[overrideMultiple];
    };  
  };

  // Override today if needed
  if(overrideToday!=dtAuto) {
    icons[0]=DAYTYPE_TO_ICON[overrideToday];
  }

  // Override tomorrow if needed
  if(overrideTomorrow!=dtAuto) {
    icons[1]=DAYTYPE_TO_ICON[overrideTomorrow];
  }
};
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

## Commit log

2022-12-05 Rename template.json
    [architecture.ods]
2022-12-05 Adding DeviceReset option
2022-12-06 Temperature update
2022-12-12 Minor tweaks device startup
2022-12-14 Tried to resolve issue boiler communiation
    [h_temperature.h]
2022-12-15 Mechanical design for TTGO
    [JustTTGO.FCStd, SelftappingScrew3.0x12.FCStd]
2022-12-20 PCB modifications
    [Interconnect PCB-B_Cu.gbl, Interconnect PCB-B_Mask.gbs, Interconnect PCB-B_Silkscreen.gbo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]
2022-12-21 Adjusted polling frequency, the last bug before release
    [h_temperature.h]
2022-12-21 Release of v1.0.7 - first fully working version
    [architecture.ods]
2022-12-22 Hide current week schedule for main screen
    [Menu structure.ods]
2022-12-22 Readme update
    [Bill of materials.ods]
2022-12-24 Added permanent storage of controller settings
    [Config and settings files.ods]
2022-12-25 V1.1.0 release
    [architecture.ods]
2022-12-28 Temporary housing added
    [DallasSensor.FCStd, JustTTGO.FCStd, Logfile.csv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]
2023-01-03 Same icons in user interface like in Telegram
    [Color converter RGB565.ods]
2023-01-06 Cleaned up print
2023-01-10 Early mechanical concept with rotary encoder added
    [RoomThermostat with PCB and rotary encoder (concept).FCStd]
2023-01-13 Wall thickness for magnets increased
    [Screw interface.3mf, Wall plate.3mf]
2023-01-26 Introduction to AsyncTelegram2
    [Logfile.csv]
2023-02-01 Test with CSV logfile added
    [cities.csv]
2023-05-29 Various changes
    [architecture.ods]
2024-09-19 Opentherm interface example project
    [NewKicadProject.csv, NewKicadProject.kicad_pcb, NewKicadProject.kicad_sch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]
2024-09-24 Reverse engineering OpenTherm
    [NewKicadProject.kicad_sch, Reverse engineering Opentherm interface.xlsx, Reverse engineering.xlsx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]
2024-09-26 Test circuits KiCad simulation
    [Test 01. Diode.kicad_pcb, Test 01. Diode.kicad_sch, Test 02. Zener.kicad_pcb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]
2024-09-28 PCB design (without ESP32) completed
    [D7.csv, EL357N-G.step, Opentherm simulation.csv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]
2024-09-28 ESP32 integrated
    [D7.csv, Opentherm simulation.csv, QU1.csv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]
2024-10-07 Added schematic sheet
    [D7.csv, Opentherm simulation.csv, QU1.csv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]
2024-10-15 First version of PCB without errors
    [Buttons.kicad_sch, Display.kicad_sch, ESP32-S3.kicad_sch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]
2024-10-15 Schematic update
    [ESP32-S3.kicad_sch, Opentherm_interface.kicad_sch, Test 09. With ESP module.kicad_pcb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]
2024-10-15 SPI port on default pins
    [ESP32-S3.kicad_sch, Housing.FCStd, Test 09. With ESP module.kicad_pcb]
2024-10-25 Component assignment
    [ESP32-S3.kicad_sch, LEDs.kicad_sch, Test 09. With ESP module.kicad_pcb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]
2024-11-16 Redesign PCB
    [Buttons.kicad_sch, D7.csv, Display.kicad_sch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]
2024-11-18 Routing PCB test 9
    [Buttons.kicad_sch, D7.csv, Display.kicad_sch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]
2024-11-25 Logo added to PCB
    [Buttons.kicad_sch, Design check and ESP32-S3 pins.xlsx, Display.kicad_sch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]
2024-11-27 As ordered at JLCPCB
    [Buttons.kicad_sch, Design check and ESP32-S3 pins.xlsx, Display.kicad_sch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]
2024-11-27 As ordered V3.0 at JLCPCB
    [Buttons.kicad_sch, D7.csv, Display.kicad_sch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]
2025-01-17 Photo of PCB added
2025-11-01 v2.0 for PlatformIO
    [architecture.ods, partitions.csv]
2026-10-24 Stand for housing. Minor UI improvements
